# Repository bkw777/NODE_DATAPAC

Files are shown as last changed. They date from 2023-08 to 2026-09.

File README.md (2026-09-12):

# NODE Systems DATAPAC
* [Documentation](#documentation)
* [Hardware](#datapac-hardware)
  * [Reproduction Schematic & PCB](#reproduction-schematic--pcb)
  * [Theory of Operation](#theory-of-operation)
  * [Battery](#battery)
  * [Upgrading 128K to 256K](#upgrading-to-256k)
  * [Model Compatibility](#model-compatibility)
* [Software](#software)
  * [BASIC](#basic)
<!-- 
  * [RAMDSK](#ramdsk)
    * [Installation](#installing-ramdsk)
    * [Usage](#using-ramdsk)
  * [NBOOT](#nboot)
  * [RAMPAC Inspector](#rampac-inspector)
  * [XOS-C](#xos-c)
  * [N-DKTR](#n-dktr)
  * [NODE-PDD-Link](#node-pdd-link)
  * [NDEXE](#ndexe)
  * [RAMPAC Diagnostic](#rampac-diagnostic)
-->
* [MiniNDP](#minindp)
<!--
  * [PCB & BOM](#minindp-pcb--bom)
  * [Cover](#minindp-cover)
-->

This repo documents the NODE Systems [DATAPAC](PICS/DATAPAC/), [rampac](PICS/rampac/), and a new clone, the [MiniNDP](#minindp).

The NODE Systems DATAPAC/rampac was a popular ram disk peripheral for TRS-80 / TANDY Models 100, 102, & 200 computers.

The schematic and PCB below documents the DATAPAC.

rampac is a smaller later version of the same device that uses fewer larger sram chips and replaces most of the discrete logic IC's with a single PLD, but functions exactly the same.

Here is some disorganized [INFO](software/) mostly gathered from the [M100SIG archive](https://github.com/LivingM100SIG/Living_M100SIG) and [club100](http://www.club100.org).

TLDR: To use the hardware, install [RAMDSK](software/RAMDSK), and what you get is a ram disk of 128k to 1M depending on model and installed ram.

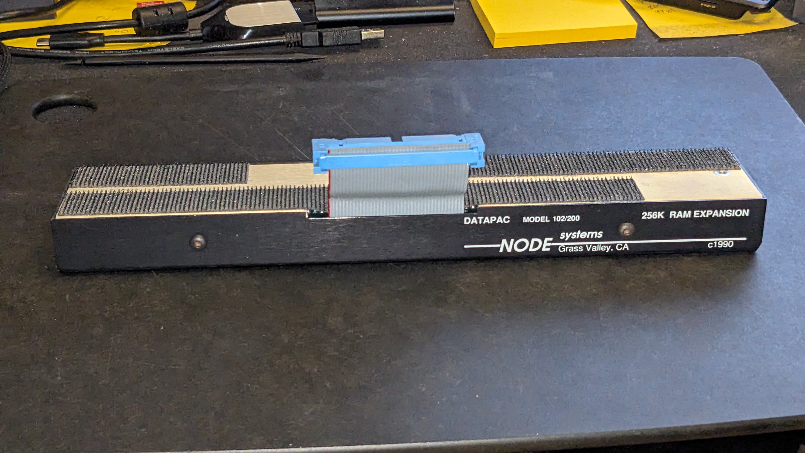
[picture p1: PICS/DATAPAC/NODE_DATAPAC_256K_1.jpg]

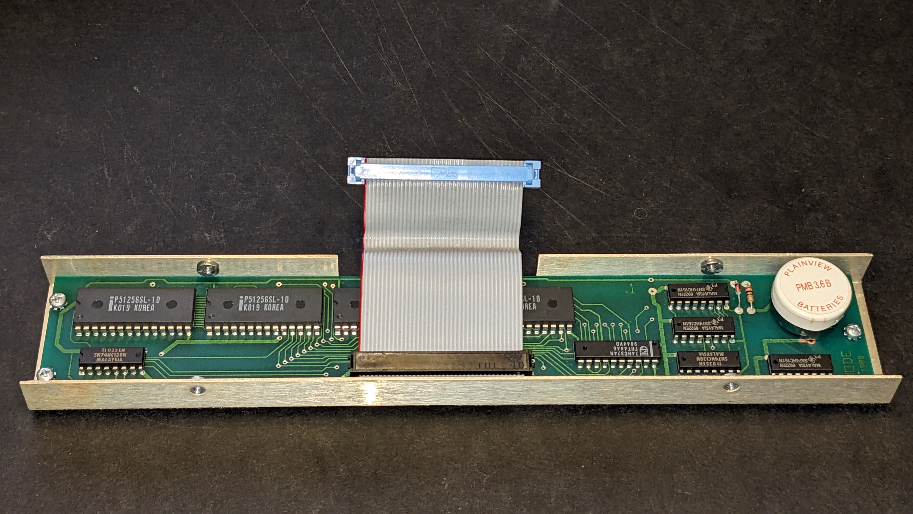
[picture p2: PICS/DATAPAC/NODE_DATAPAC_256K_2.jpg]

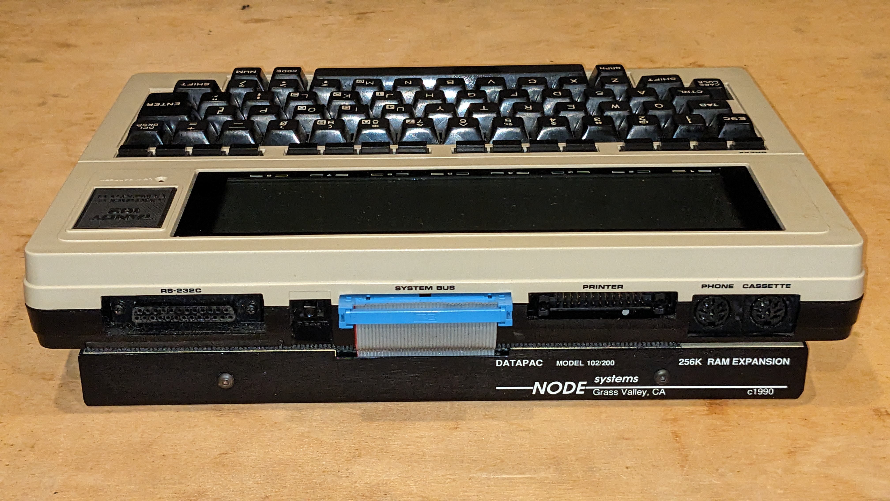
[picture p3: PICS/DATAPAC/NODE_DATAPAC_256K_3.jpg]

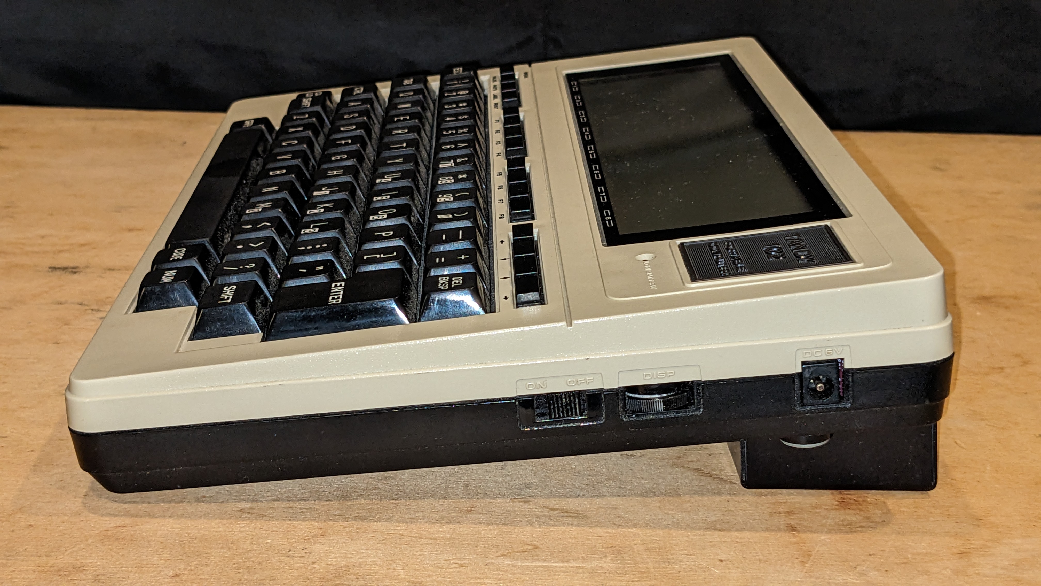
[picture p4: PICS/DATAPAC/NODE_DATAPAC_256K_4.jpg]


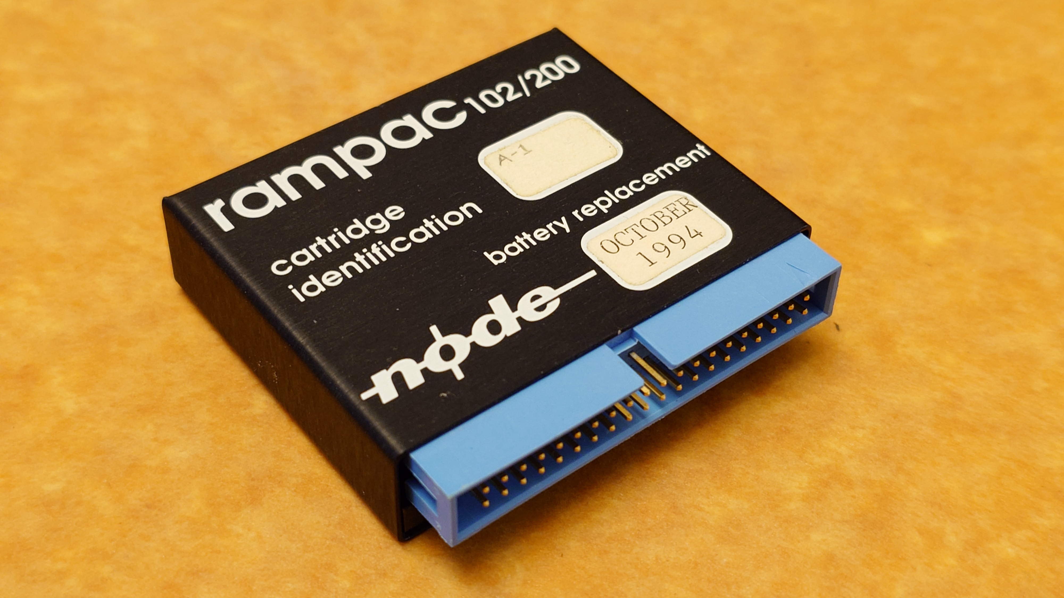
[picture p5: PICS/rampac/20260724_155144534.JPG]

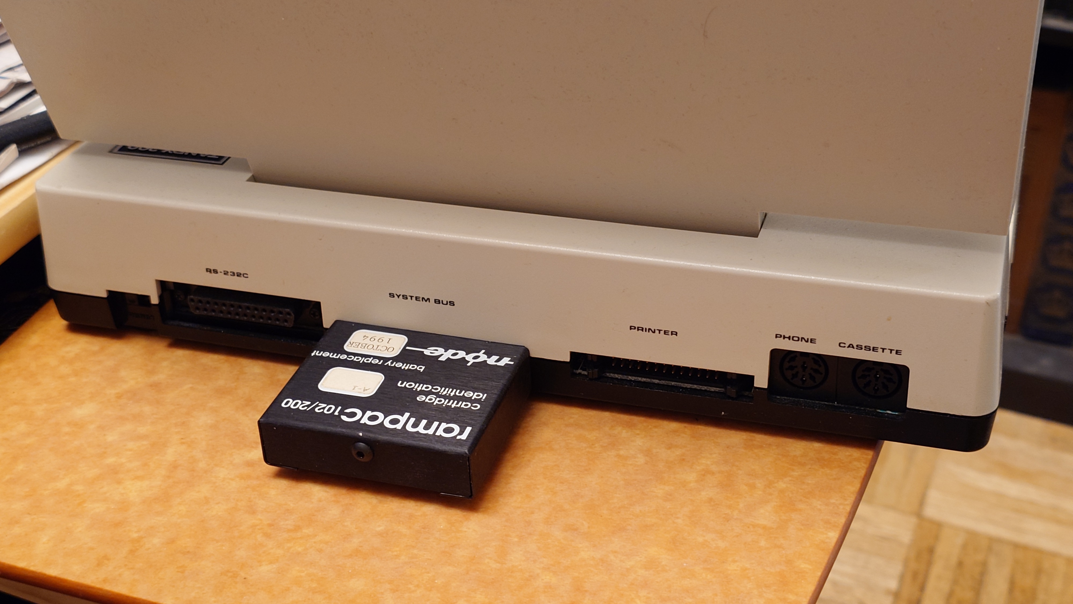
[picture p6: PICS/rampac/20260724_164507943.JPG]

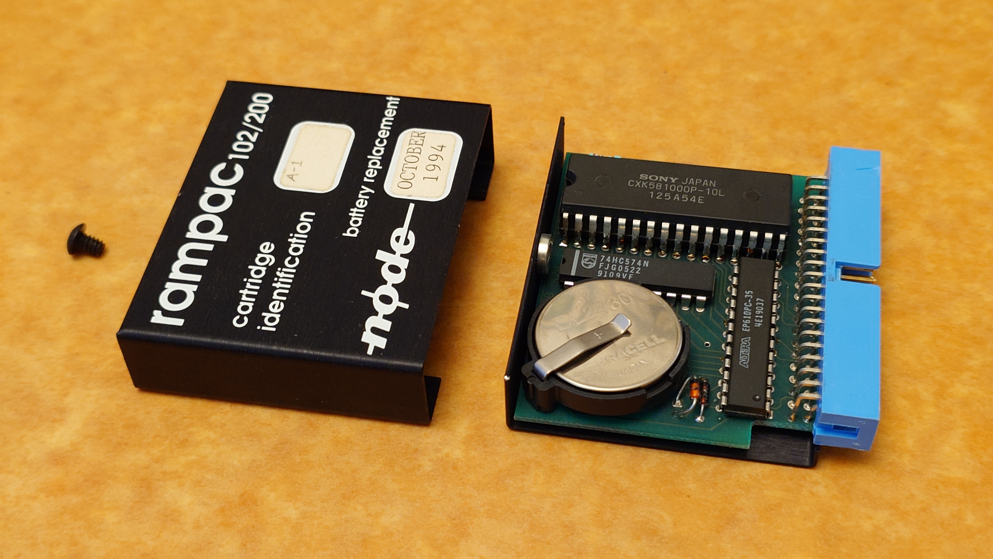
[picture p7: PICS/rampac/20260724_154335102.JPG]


# Documentation
The original text file manual [RAMDSK.DO](ROM/100/RAMDSK.DO).  
The [NODE ROM](ROM) that came with the unit generates this file when formatting a device.

There are also some discussions in the [M100SIG archive](https://github.com/LivingM100SIG/Living_M100SIG) and Paul Globmans software on [club100](http://www.club100.org/library/libpg.html).  
Most of these are collected in [docs](docs).  
See also the docs for the various bits of [software](software).

Other References  
* "Database management with both the Node RAMPAC & DATAPAC."  
  Alspaugh, Ron - [Portable 100, Nov 90:8-11](https://archive.org/details/P100-Magazine/1990-11/page/8/)  
* "Node utility mini-extravaganza! Here are two special programs for Node Datapac/RAMPAC users."  
  Globman, Paul - [Portable 100, Dec 90:19-20](https://archive.org/details/P100-Magazine/1990-12/page/18/)  

# DATAPAC Hardware
## Reproduction Schematic & PCB
This is a new drawing but aims to reflect the original actual device as exactly as possible.  
It's meant to be a form of documentation or reference describing the original hardware as it was.  
For instance, the ungrounded inputs on the 161's, the inconsistent thickness of power traces, the fact that only 1 of the 2 bus VDD pins is connected, the VCC trace that almost touches one of the mounting screw heads, etc, are all exactly as in the original.  
(I added a fiber washer to that screw in my units after noticing that. The case is not connected to ground, but still...)  

For a historical reproduction version of the original PCB (minus the NODE copyright mark), see: NODE_DATAPAC_256K_historical_reproduction.kicad_pro

For a version of the original PCB that still uses the same components and fits in the same case, but cleans up a few things, see: NODE_DATAPAC_256K_bkw.kicad_pro



PCB TOP
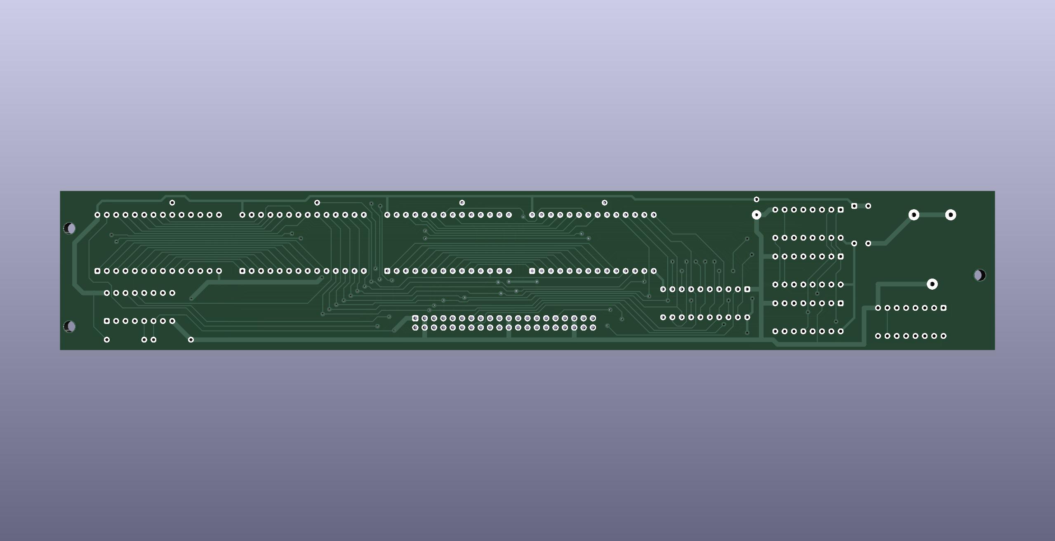
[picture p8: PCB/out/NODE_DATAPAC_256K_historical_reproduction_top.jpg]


PCB BOTTOM
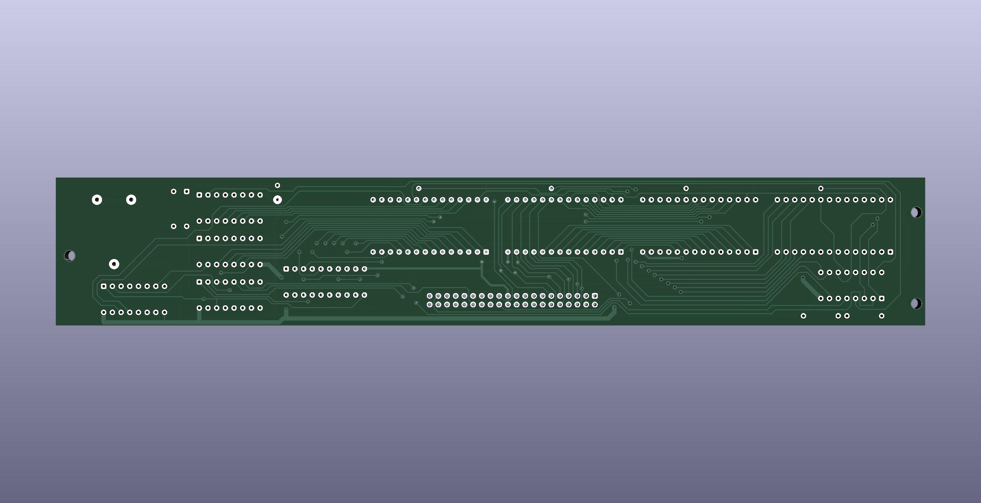
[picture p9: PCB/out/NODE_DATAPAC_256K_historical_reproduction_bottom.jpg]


The original PCB has no silkscreen. This image has silkscreen added to show where the components from the schematic go.
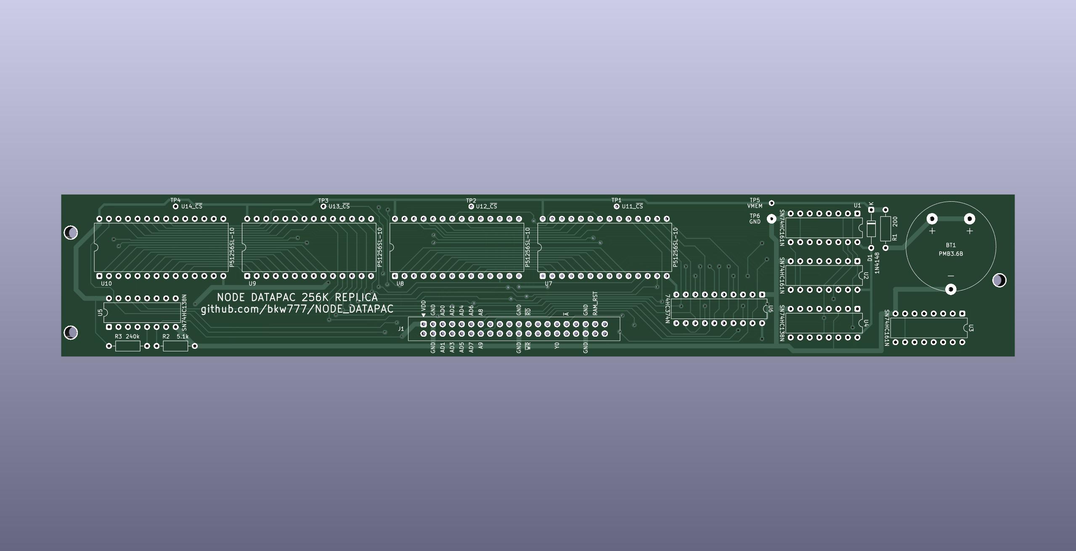
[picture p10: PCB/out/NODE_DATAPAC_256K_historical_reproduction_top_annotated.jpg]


<!--
## Updated Replacement PCB that fits the original case

Uses all the same through-hole parts, fits in the original enclosure, improves the trace routing a little, for example moving that VCC line away from that screw head, GND traces replaced by zone fills, thicker and all the same size vcc lines, decoupling caps, silkscreen.  
![](PCB/out/NODE_DATAPAC_256K_bkw.svg)
![](PCB/out/NODE_DATAPAC_256K_bkw.top.jpg)
![](PCB/out/NODE_DATAPAC_256K_bkw.bottom.jpg)
![](PCB/out/NODE_DATAPAC_256K_bkw.f.jpg)
![](PCB/out/NODE_DATAPAC_256K_bkw.b.jpg)
-->

## Theory of Operation
The circuit has 2 functions, SELECT-BLOCK and READ/WRITE-BYTE, controlled by the internal active-low signals /BLOCK and /BYTE.

The U4 HC138 monitors four lines from the bus, `/Y0` `(A)` `A8` `A9`, and based on that asserts either `/BLOCK` or `/BYTE` or neither.  
If neither /BLOCK nor /BYTE is asserted then the bus traffic has no effect on any of the other chips.

The 3 HC161 form a 0-1023 counter, setting SRAM address bits A0-A9.  
Call this the byte-number or byte-position counter or offset.

The HC374 sets SRAM address bits A10-A17 from the bus data bits AD0-AD7, and latches that value on its outputs until triggered to update to a new value.  
Call this the block-number or block selector.

The U5 HC138 converts 3 bits of the block-number into 1 of 8 chip-select to select 1 of 8 32K SRAM chips,  
and also monitors both /BYTE and RAMRST and disables all ram while either /BYTE or RAMRST is high.

----

### SELECT-BLOCK
When /BLOCK goes low:
* SRAM A0-A9 are reset to 0  (byte-position counter is reset to 0)
* BUS AD0-AD7 are copied to SRAM A10-A17  (bus data lines AD0-AD7 select a block-number)

When /BLOCK goes high:
* SRAM A10-A17 are held latched at whatever they were set to  (block-number is locked in until next /BLOCK)

----

### READ-BYTE / WRITE-BYTE
When /BYTE goes low:
* SRAM is enabled  (bus data lines AD0-AD7 read from or write to the current address in SRAM)

When /BYTE goes high:
* SRAM is disabled
* A0-A9 are incremented by 1 (byte-position, thus the current address in SRAM, is advanced to the next byte)

----

The byte-number and block-number combine to form the current address in SRAM at any given time.  

The device provides up to 256 blocks (8-bit block-number) of 1024 bytes each (10-bit byte-number).

The host computer first does a SELECT-BLOCK to select a block number from 0-255, then does READ-BYTE or WRITE-BYTE to read or write one byte of data at byte number 0 in that block, then repeats the BYTE operation up to 1023 more times to read or write up to all 1024 bytes in the block.  

If you read or write more than 1024 times without selecting a new block, the byte-number counter just rolls over to 0 again.

You can also mix reads and writes in the same block. Each read OR write advances the byte position the same way each time, regardless if the previous operation was a read or a write. For instance in order to skip over 64 bytes without modifying them and then start writing at the 65th byte, you would read-and-ignore 64 times and then start writing.

"ramdisk" is an appropriate term because the device actually does operate like a disk even though it has no brains or firmware. The block-select latch acts like a track or sector address, and the binary counter acts like a disk or tape head reading or writing a sequential stream of bytes.

Later versions of RAMPAC were offered with 384k or 512k by adding a second bank of up to 256k, and later versions of RAMDSK.CO know how to access the 2nd bank.

In 512K units, the extra 256K is accessed by the state of bus address line A10 during a SELECT-BLOCK operation.  
SELECT-BLOCK with BUS_A10 low accesses bank0, with BUS_A10 high accesses bank1.  
All other aspects are the same, so accessing bank0 on a a 512K device is the same as accessing the only bank on a 256K device.  Old software is still compatible with bank0 on new hardware, new software is still compatible with old hardware.

[What this all means from the host computer software side of things](https://github.com/bkw777/NODE_DATAPAC?tab=readme-ov-file#low-level-direct-access-using-only-basic)

## Battery
The original battery is no longer made, and the modern cross-reference is almost 2mm taller and does not fit inside the enclosure.

NODE Systems themselves used to perform an update to older units to replace the original rechargeable NiCD cell with a non-rechargeable lithium cell which was supposed to last about 5 years.

The change is simple and easy, and the parts are common. You just remove the old battery and the 200 ohm resistor, and replace them with a CR2032 holder and a diode. That's it. Both parts fit and solder right in the same locations where the old parts came out. Point the diode stripe away from the battery, just like the other diode that is right there next to it. Any standard diode will do. Schottky is not recommended because the reverse leakage is not good for a lithium cell. Another 1N4148 like the one that's already there is perfect.  
This should give at least 4 years of memory.  
(The original NiCD battery may have only lasted as little as a few months per charge according to a review in the archives. So the coin cell mod is not merely more conveniently available with current parts, it's an improvement.)

BEFORE
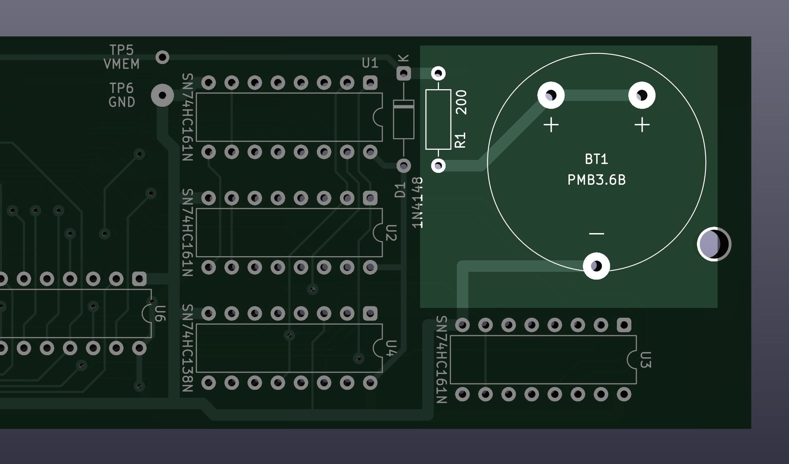
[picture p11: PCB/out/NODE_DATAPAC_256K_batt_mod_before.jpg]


AFTER
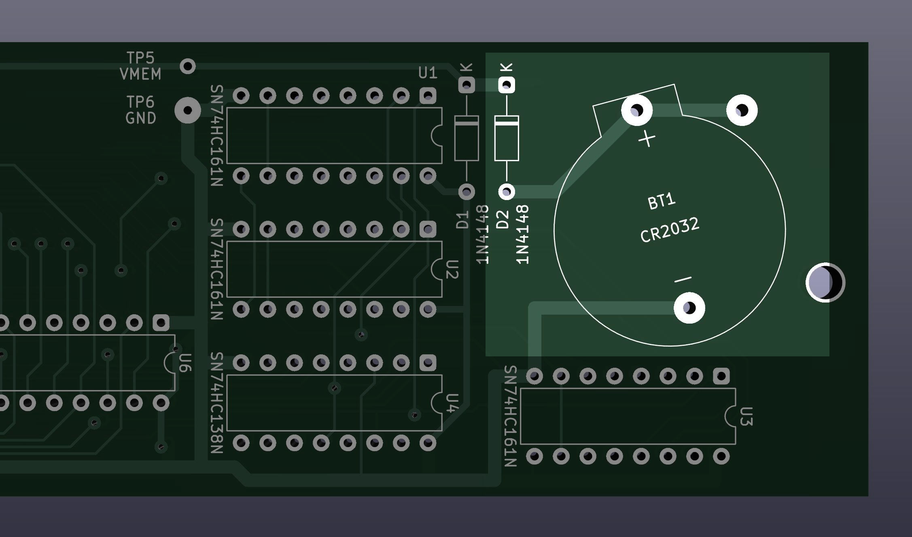
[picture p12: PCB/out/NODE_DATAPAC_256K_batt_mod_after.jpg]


STEPS
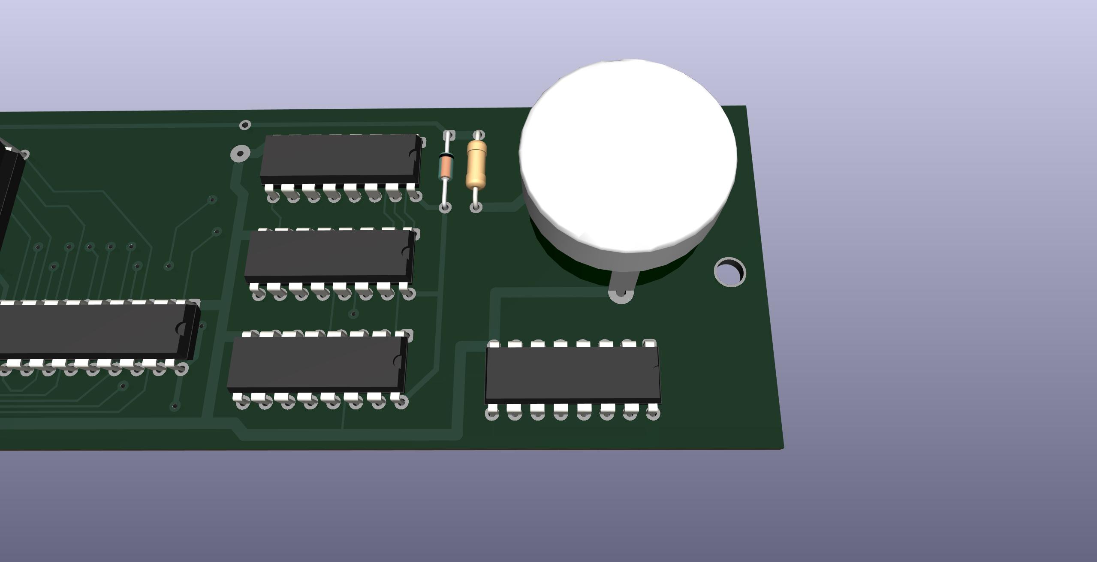
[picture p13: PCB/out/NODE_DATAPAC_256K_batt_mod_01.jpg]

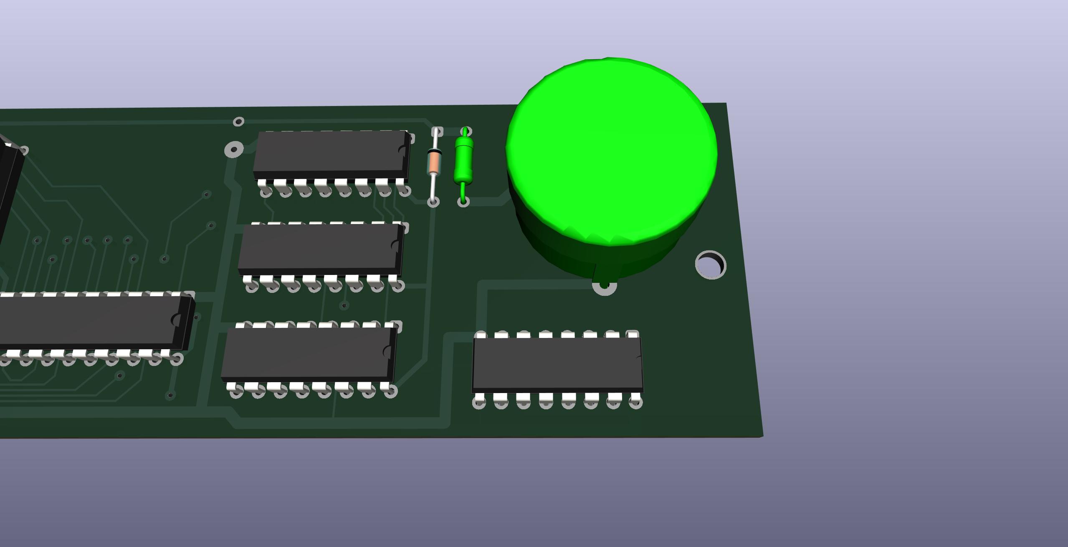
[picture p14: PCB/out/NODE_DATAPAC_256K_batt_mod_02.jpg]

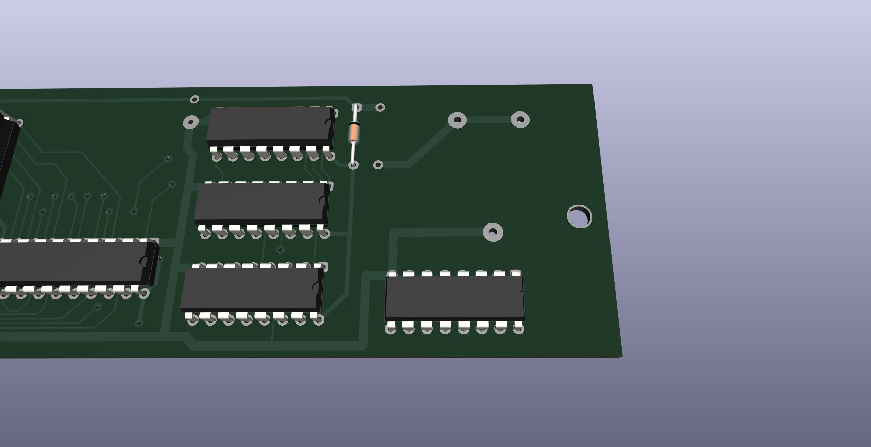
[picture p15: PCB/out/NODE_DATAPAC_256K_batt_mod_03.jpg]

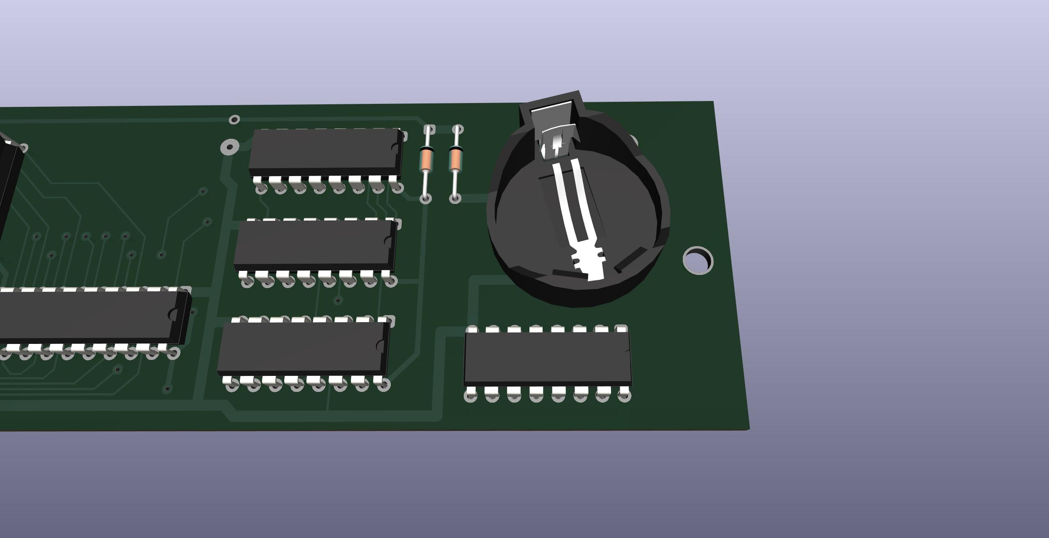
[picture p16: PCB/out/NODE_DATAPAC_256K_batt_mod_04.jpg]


If you wish to keep using a rechargeable battery, then one suitable option is FL3/V80H. That is 3 16x5.8mm NiMH button cells in a flat in-line pack with wire leads. It fits perfectly in the space next to the ribbon cable. It needs to be secured with hot glue or foam mounting tape, and connected with wires run to the original battery location.  
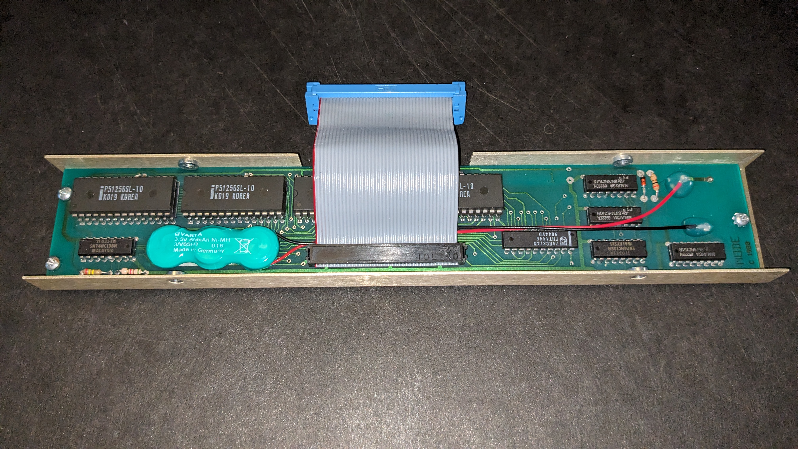
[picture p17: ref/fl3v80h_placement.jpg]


The charging circuit is utterly basic, so do not connect any other type of battery except NiCD or NiMH.  
You can use any cell form factor and any larger or smaller mAh capacity, but must be 3.6v and only NiCD or NiMH chemistry.

## Upgrading to 256K
A 128k unit may be upgraded to 256k by just adding 4 more SRAM chips piggy-backed onto the existing chips.

The PCB has 4 DIP-28 footprints for the SRAM chips.  
Each DIP-28 footprint also has an extra via close to pin 20.

A 128k unit has a low-power 62256 installed in each footprint, and nothing connected to the via near pin 20.

To get 256k, a second set of chips are soldered piggyback on top of the first four.  
All pins except pin 20 (chip-select) are simply soldered to the chip below.  
Pin 20 is bent out and connected to the extra via on the pcb (with a short bit of wire to reach) and not connected to the chip below.  

No other parts or changes are needed to upgrade an existing 128k unit to 256k.

Any 62256 will work, but for old parts you want the low-power version for standby battery life.  
New parts already naturally have as low or lower standby current than the low-power versions of old parts even if they don't say "low power".  
Old standard: HM62256    70uA  
Old lowpower: HM62256LP  4uA  
Old lowpower: P51256SL   2uA  
New standard: AS6C62256  1uA

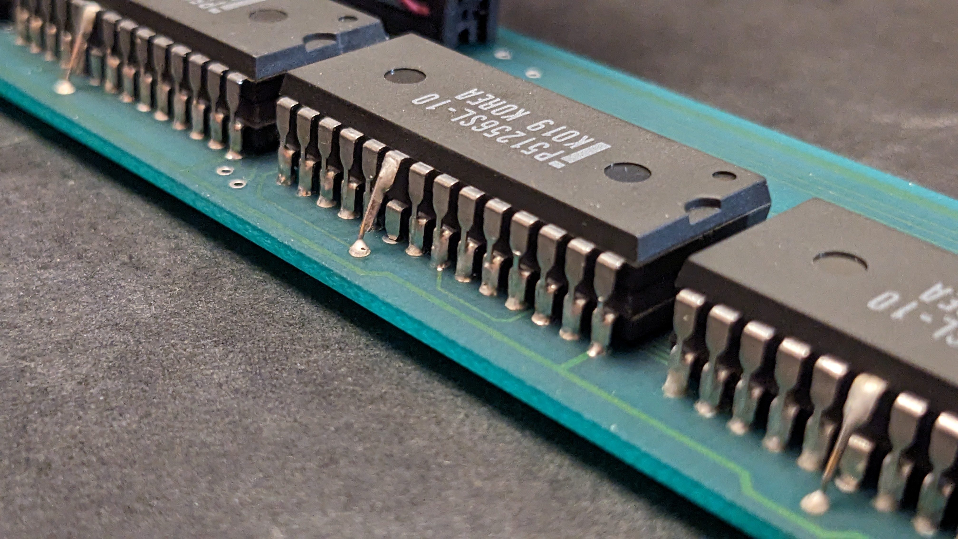
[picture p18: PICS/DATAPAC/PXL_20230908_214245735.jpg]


The same is true for rampac. Except:  
 - single 128k sram chip, ex: AS6C1008
 - chip-select is pin 30
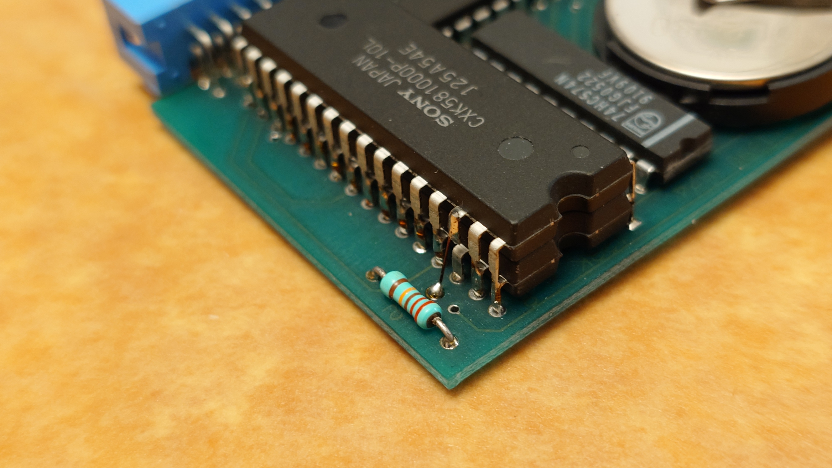
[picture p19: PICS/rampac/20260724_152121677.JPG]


## Model compatibility  
Originally only North-American Models 100, 102, & 200 were ever supported.  
Kyotronic KC-85 and Olivetti M-10 are also supported today because RAMDSK has been disassembled and ported, and the assembly source means the international models could be added as well.  
The device is not compatible with NEC PC-8201/PC-8300.

Although the DATAPAC was primarily designed for Model 102 & 200, the crimp-on boxed male IDC pin header on the cable does not actually fit into a 200 without enlarging the opening around the bus connector on the 200. If you want to connect an original DATAPAC to a 200 without hacking up the 200's case or modifying the DATAPAC cable, you can build a small [adapter](ref/T200_adapter.jpg) by just soldering a [male](https://www.digikey.com/en/products/detail/sullins-connector-solutions/SBH11-PBPC-D20-ST-BK/1990068) & [female](https://www.digikey.com/en/products/detail/sullins-connector-solutions/SFH11-PBPC-D20-ST-BK/1990093) solder-type 2x20 boxed pin headers back to back. The solder box header does fit in the opening.
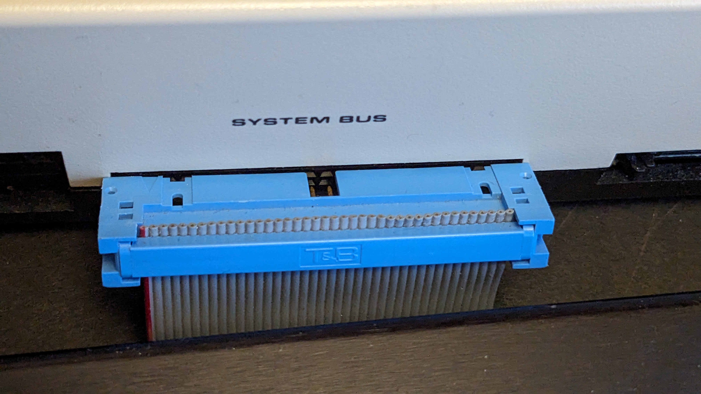
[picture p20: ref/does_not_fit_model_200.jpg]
  
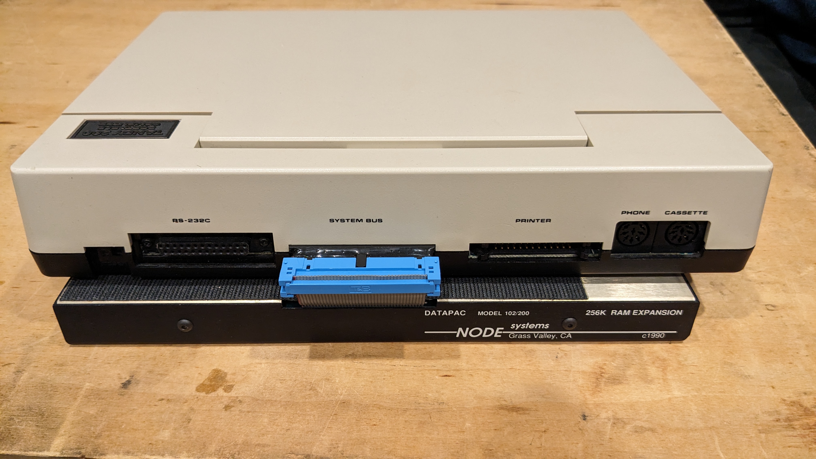
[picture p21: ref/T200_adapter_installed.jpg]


The DATAPAC case says "102/200", but it also works on Model 100, K85, and M10 with the right adapter cable. It's electrically compatible with everything but NEC.

For 100 & K85 the cable is just an IDC-DIP-40 aka "DIP-40 wire-to-board" connector and a standard 2x20 female IDC connector, both crimped onto a 40-pin ribbon cable about 8 inches long.  
[The Model 100 adapter part](https://github.com/bkw777/TRS-80_Disk_Video_Interface_Cable/blob/main/README.md#part-3---model-100-adapter) of this [3-part Disk/Video Interface Cable](http://tandy.wiki/Disk/Video_Interface:_Cable) is the same thing.

For Olivetti M-10 the cable is even simpler, a standard female to female IDC 40-pin ribbon cable.

[MiniNDP](#minindp) fits directly on both 102 and 200 with no adapter or cable, or M10 with a female-female ribbon cable at least 5 inches long.

[MiniNDP_u1M](#minindp-u1m---for-model-100-or-kyotronic-kc-85) fits directly in the bus socket of 100 or K85 with no adapter or cable, and the cover can even be closed over it.

# Software

 - [NODE ROM](ROM)  
 - [RAMDSK.CO](software/RAMDSK)  
 - [XOS-C](http://www.club100.org/library/libpg.html) ("sort of an OS" for the Model 200, does not require a rampac but leverages one if available. [Several of the NODE utils from the M100SIG require XOS-C.](software/Requires_XOS-C/))
 - [other](software)  

Originally these shipped with an [OPTION ROM](ROM) from NODE called RAMDISK.

Later, Paul Globman wrote [RAMDSK.CO](software/RAMDSK), and that was eventually licensed by NODE and shipped with new units.  

Later still, RAMDSK was updated with 2 changes:  
 - automatic repair of a corrupted format stamp on start-up  
 - support for 512k in 2 banks of 256k (RAMPAC & EXTRAM)

Recently, RAMDSK has been updated yet further:  
- disassembled to produce assembly source  
- ported to Kyotronic KC-85  
- ported to Olivetti M-10  
- support for 4 banks  
- format on demand from Label button  
- added safety confirmation to format & repair  
- removed dead code

Some other software culled from the [M100SIG archive](https://github.com/LivingM100SIG/Living_M100SIG) and [Club100](https://www.club100.org) are collected here in the [software](software) directory.  

## BASIC
How to access the hardware from BASIC.

### High level file operations using CALLable machine language routines
See [RAMDSK.DO](ROM/100/RAMDSK.DO) for the NODE ROM routines.  
See [RAMDSK.TIP](software/RAMDSK/RAMDSK.TIP) for the RAM100.CO/RAM200.CO routines.  
But note, the addresses in RAMDSK.TIP are incorrect for RAMDSK v2. We don't have a copy of RAMDSK v1 for 100 but we do for 200. So you can't follow those directions exactly except with RAMDSK v1 on 200.  

The latest RAMDSK built from the new source includes *.calls files that give the current addresses to the routines in those binaries, but actually using them has not been tested.

### Low level direct access using only BASIC
There are two low level operations that you use to access the device,  
BLOCK and BYTE, and each of those has two variations, for four total ops.

Select a BLOCK from BANK 0  
`OUT 129,n`  
Selects block# **n** (0-255) in bank 0, and resets the byte position to 0.

Select a BLOCK from BANK 1  
`OUT 133,n`  
Selects block# **n** (0-255) in bank 1, and resets the byte position to 0.

Read a BYTE  
`INP(131)`  
Reads the byte at the current byte position, and advances the byte position by one.

Write a BYTE  
`OUT 131,n`  
Writes the value **n** (0-255) to the current byte position, and advances the byte position by one.

The first read or write after selecting a block# applies to byte #0 of that block.  
The byte position advances by one after each read or write, so the next read or write will be byte #1, then byte #2, etc up to 1024.  
If you read or write more than 1024 times without selecting some other block, the byte position just rolls over to 0 again.

The position counter advances the same whether reading or writing.

Since the device can only read or write a single unsigned byte at a time, it's most efficient to use integer variables.  
Use the % suffix or DEFINT: `B%=INP(131)` or `DEFINT B : B=INP(131)`

The general sequence is always:  
1 - select a bank+block  
2 - read/write byte 0-1024 times

To seek to an arbitrary offset before reading or writing, read-and-ignore that many bytes.

For instance, in RBOOT.DO, to skip over the first 16 bytes of the block, it does `FORA=0TO15:N=INP(131):NEXT`  
N is not actually used, it's just reading 16 times and ignoring the data. This just advances the byte position counter to get from byte #0 past the 10-byte RAMDSK header and 6-byte .CO header to the start of the .CO executable data.

Examples

Select bank 0 block 0  
`OUT129,0`

read a byte, which will be byte #0 of this block  
`INP(131)`

Read and print the ascii of all the bytes in bank 0 block 2.  
(this will mess up the display from control bytes if there is a binary .CO file in this block)
```
10 OUT 129,2
20 FOR I=0 TO 1023
30 PRINT CHR$(INP(131));
40 NEXT
```

Do the same but in bank 1  
change line 10 to:  
`10 OUT 133,2`

Manually repair the first two bytes of block 0 to mark the bank as being formatted without touching any of the data.  
This means:
1. Select bank0 block0  
2. write one byte, value 64  
3. write one byte, value 4

`OUT129,0:OUT131,64:OUT131,4`

(BTW you usually don't need to do this because RAMDSK.CO will do it for you.)

# MiniNDP

New design that functions the same as DATAPAC/rampac.

1 megabyte in 4 banks of 256k.

How to access all 4 banks:  
Select bank 0, block N: `OUT 129,N`  
Select bank 1, block N: `OUT 133,N`  
Select bank 2, block N: `OUT 137,N`  
Select bank 3, block N: `OUT 141,N`

Everything else works the same as normal DATAPAC/rampac.

## MiniNDP EZ1M - For Model 102 and 200

Unlike the original DATAPAC, this actually fits into the bus port on the Model 200 without having to hack it's case.

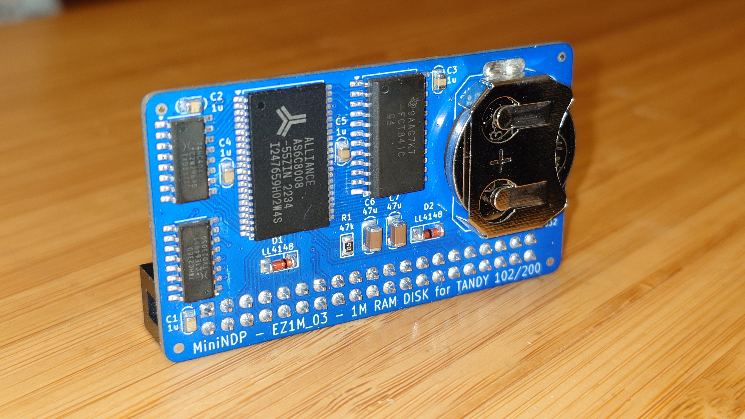
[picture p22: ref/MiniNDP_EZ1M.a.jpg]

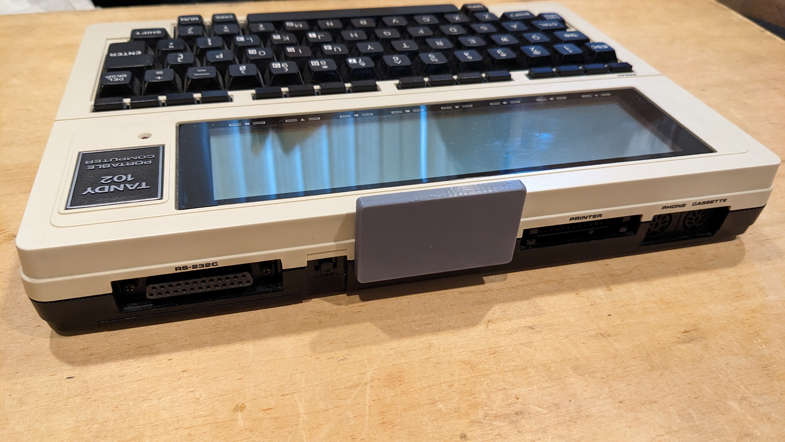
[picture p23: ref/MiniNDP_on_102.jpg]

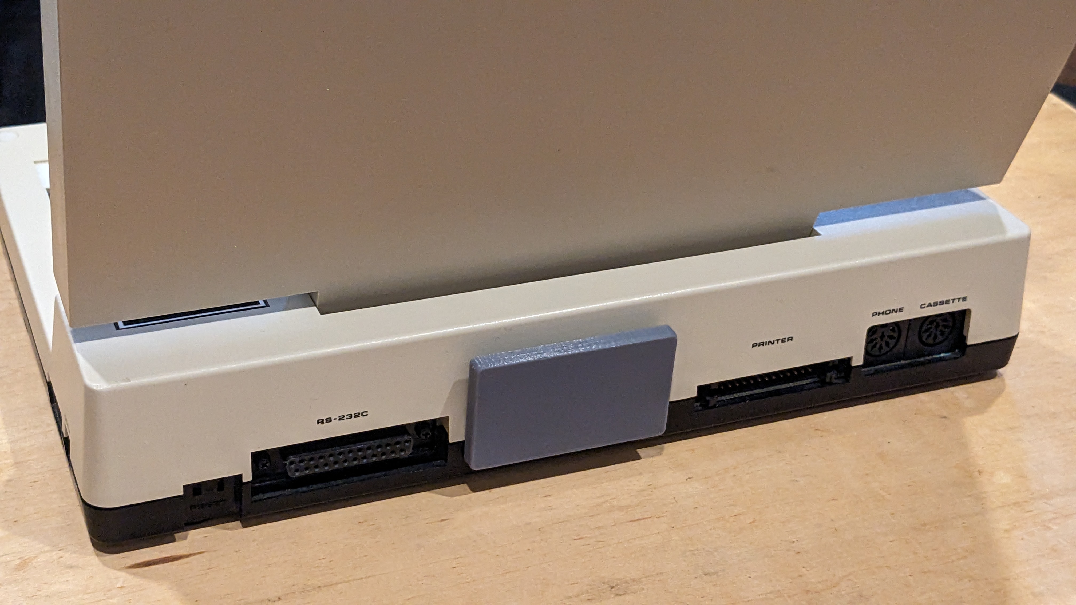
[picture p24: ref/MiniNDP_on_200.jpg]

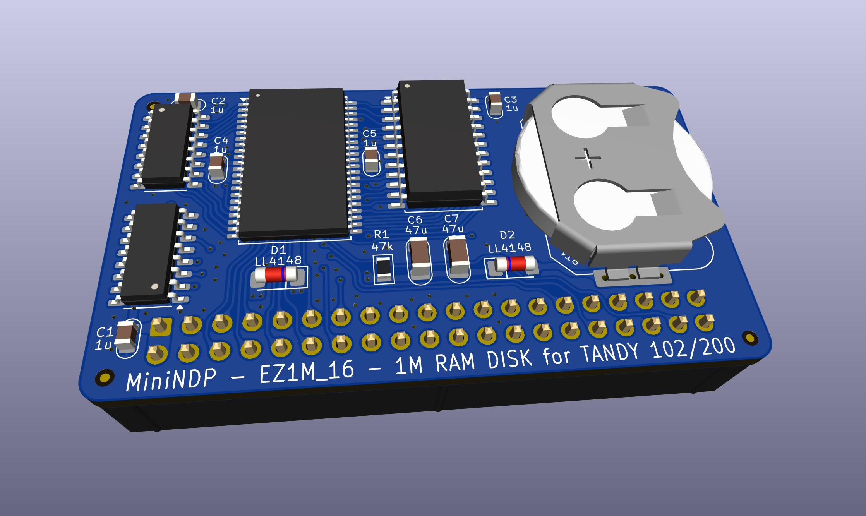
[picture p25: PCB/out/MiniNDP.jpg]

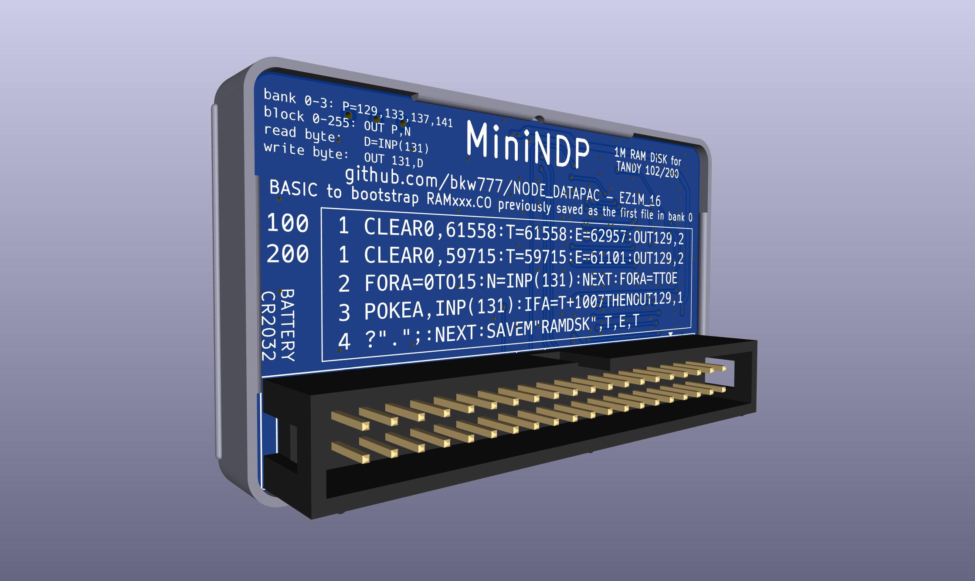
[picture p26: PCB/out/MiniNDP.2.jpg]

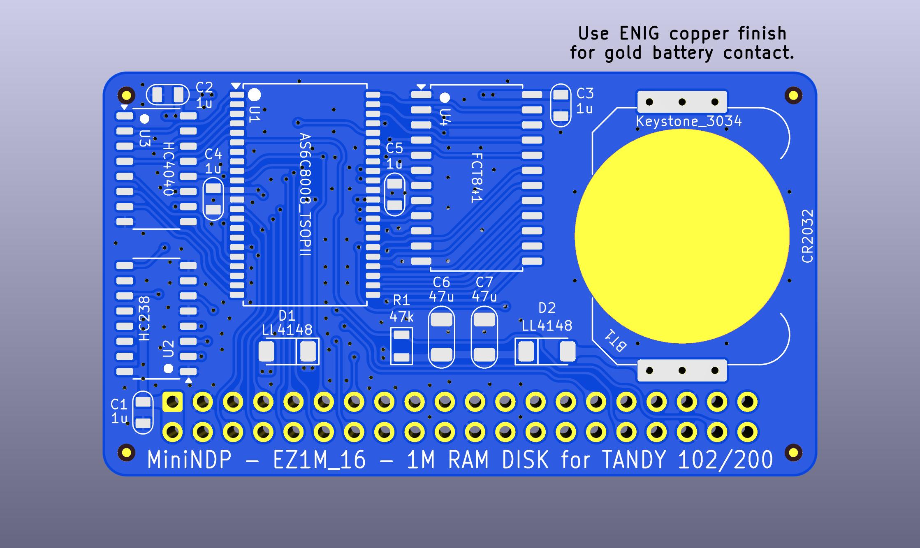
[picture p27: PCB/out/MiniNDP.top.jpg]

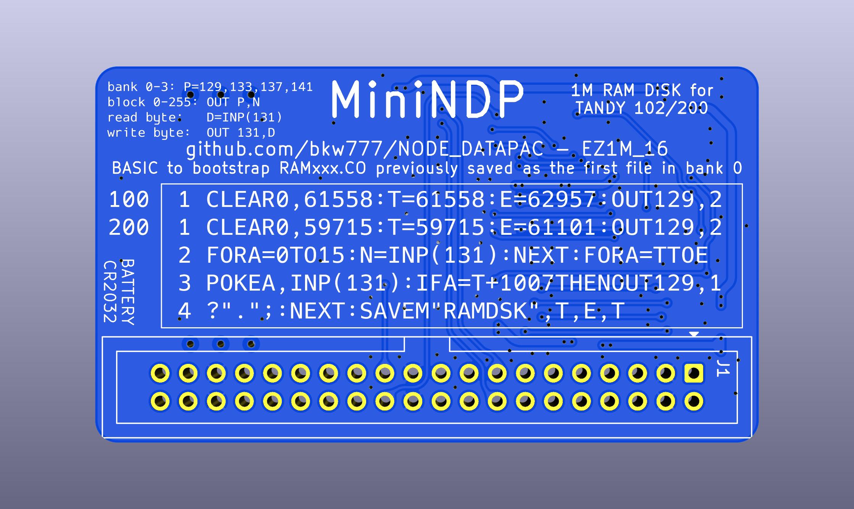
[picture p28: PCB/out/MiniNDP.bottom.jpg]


[MiniNDP.bom.csv](PCB/out/MiniNDP.bom.csv)

BOM: [DigiKey](https://www.digikey.com/short/m4h7bmh0)  
[MiniNDP EZ1M_16 PCB @ OSHPark](https://oshpark.com/shared_projects/7Jpm6F6c)  
Cover: [MiniNDP_Cover.stl](COVER/out/MiniNDP_Cover.stl) -- [Cover @ JawsTec](https://shop.jawstec.com/3d-printed-minindp-cover_p658.php)  
[Both PCB & Cover @ PCBWAY](https://www.pcbway.com/project/shareproject/MiniNDP_mini_Node_DataPac_d08018c4.html)  

## MiniNDP u1M - For Model 100 or Kyotronic KC-85

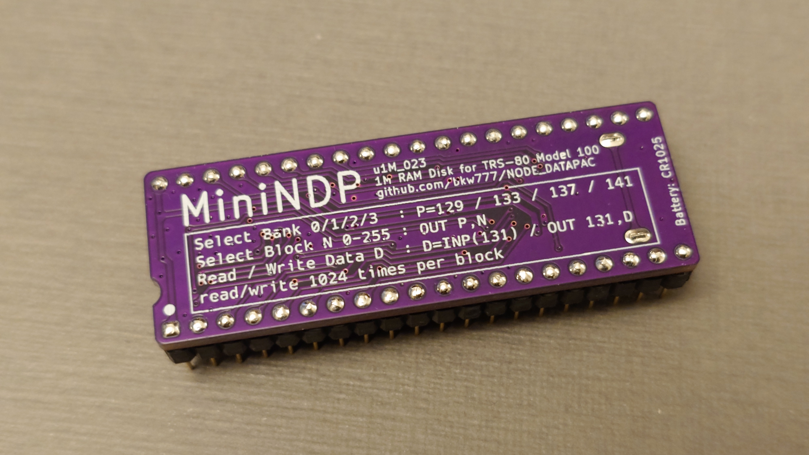
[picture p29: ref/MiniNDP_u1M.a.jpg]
  
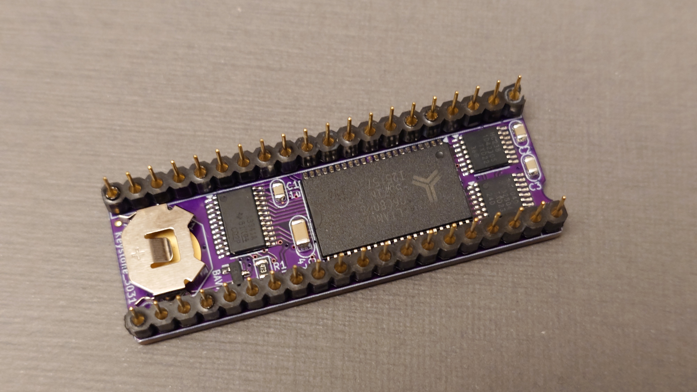
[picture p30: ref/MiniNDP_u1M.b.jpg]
  
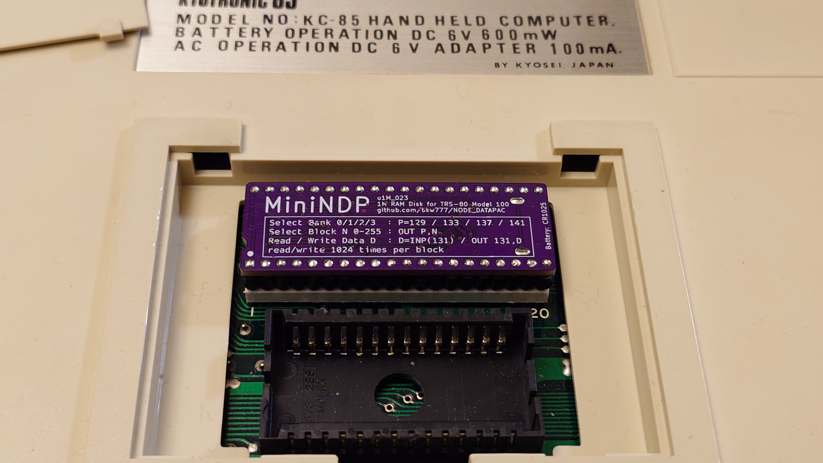
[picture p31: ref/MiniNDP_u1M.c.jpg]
  
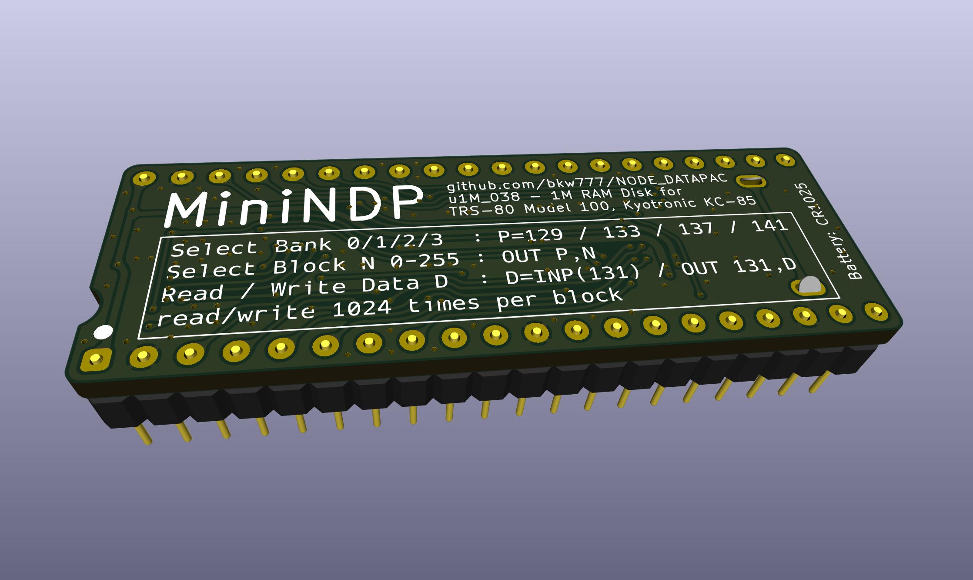
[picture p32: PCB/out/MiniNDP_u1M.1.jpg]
  
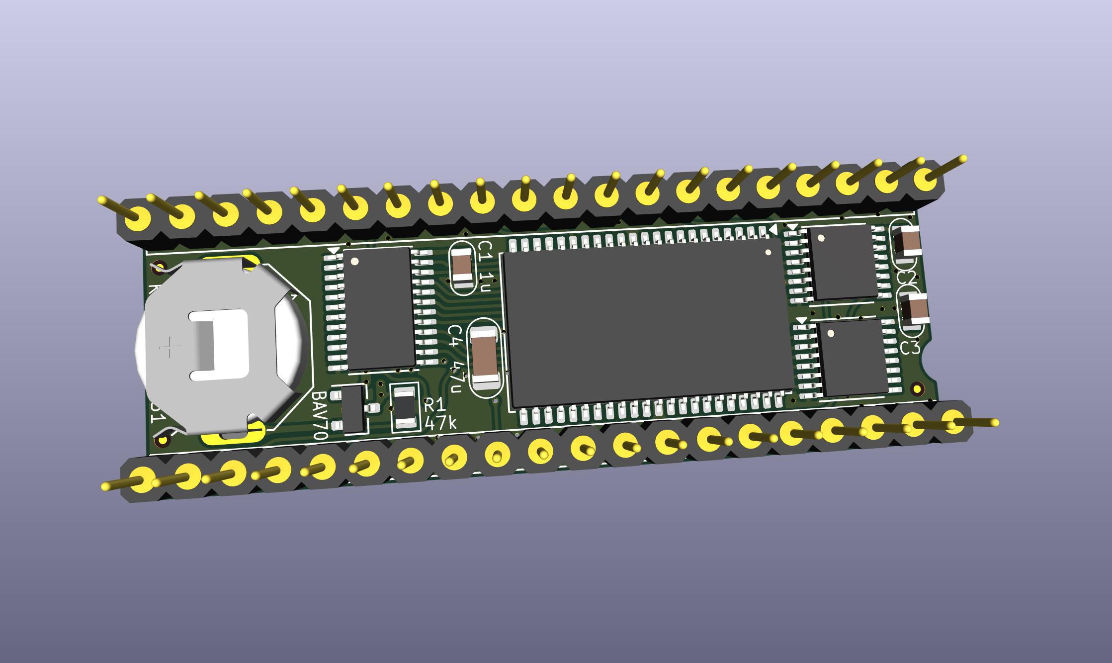
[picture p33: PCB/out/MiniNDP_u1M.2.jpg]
  
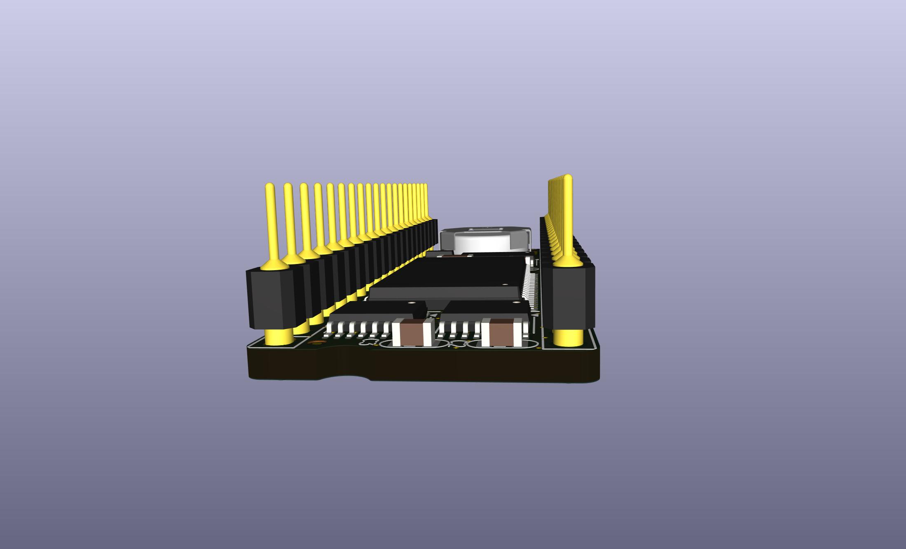
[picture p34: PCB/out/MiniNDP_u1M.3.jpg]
  
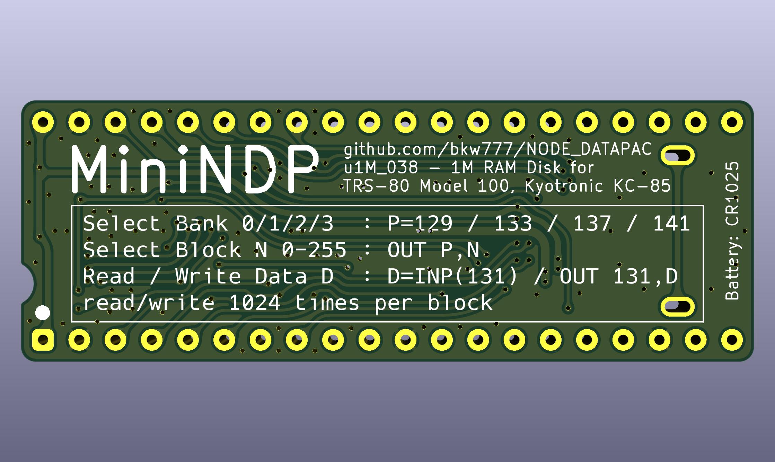
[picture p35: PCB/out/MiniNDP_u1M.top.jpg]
  
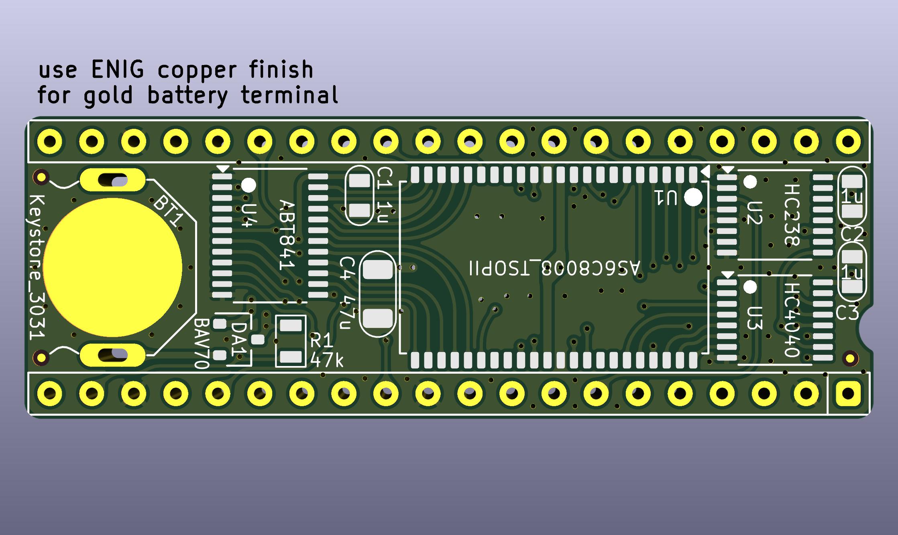
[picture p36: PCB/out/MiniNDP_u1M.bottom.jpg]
  
  

BOM: [MiniNDP_u1M.bom.csv](PCB/out/MiniNDP_u1M.bom.csv)  
[MiniNDP u1M_038 PCB @ OSHPark](https://oshpark.com/shared_projects/XwUDgfQu)

## MiniNDP M10 - For Olivetti M-10

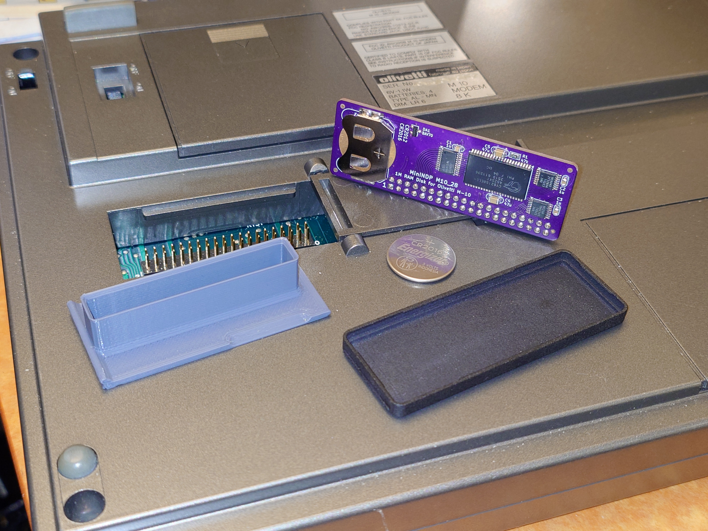
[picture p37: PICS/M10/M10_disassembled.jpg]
  
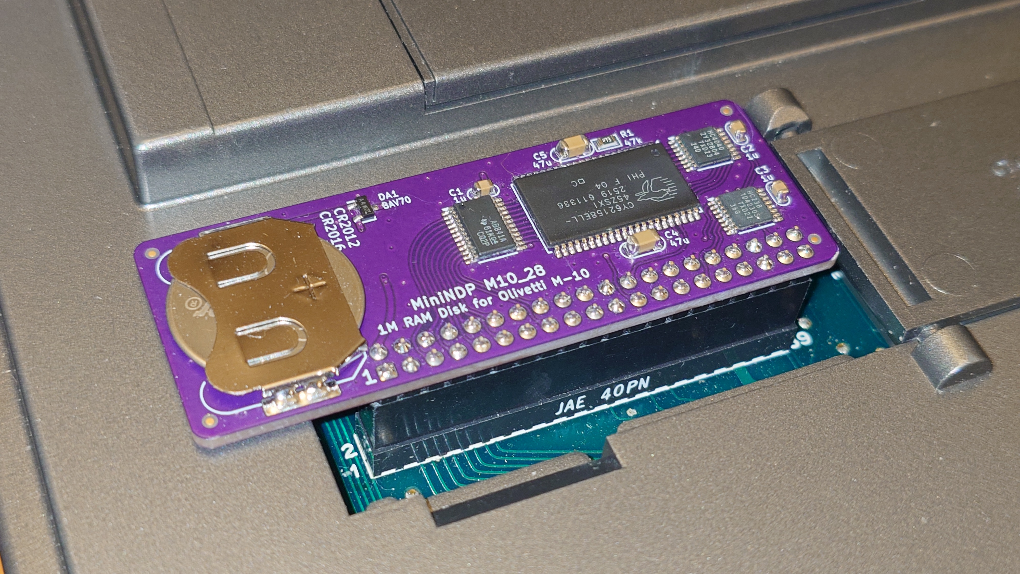
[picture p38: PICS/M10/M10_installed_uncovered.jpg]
  
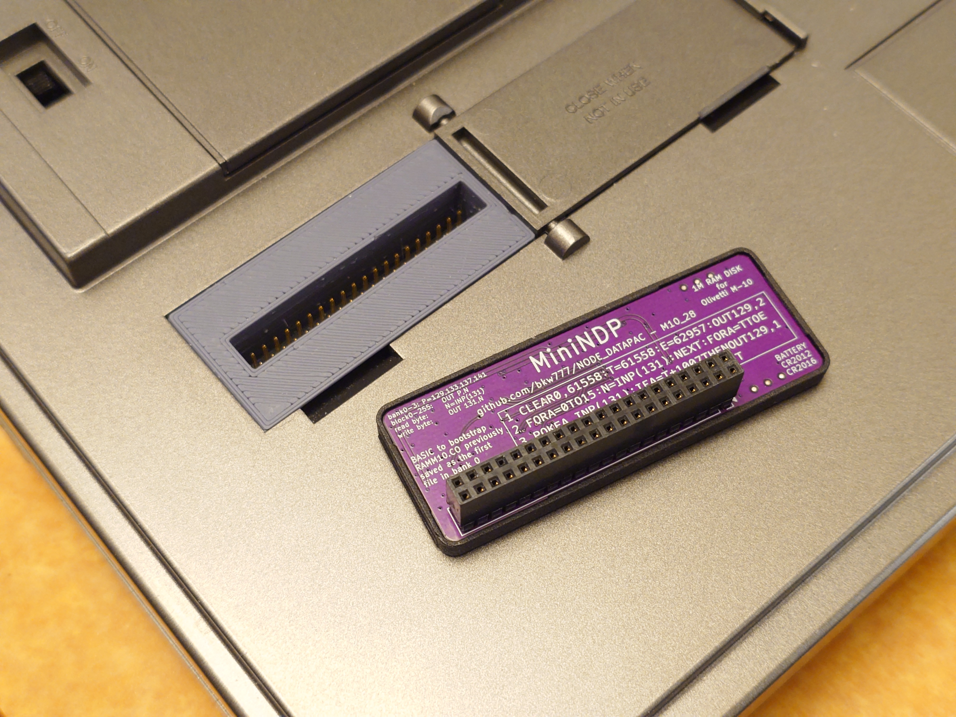
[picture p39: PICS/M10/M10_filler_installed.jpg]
  
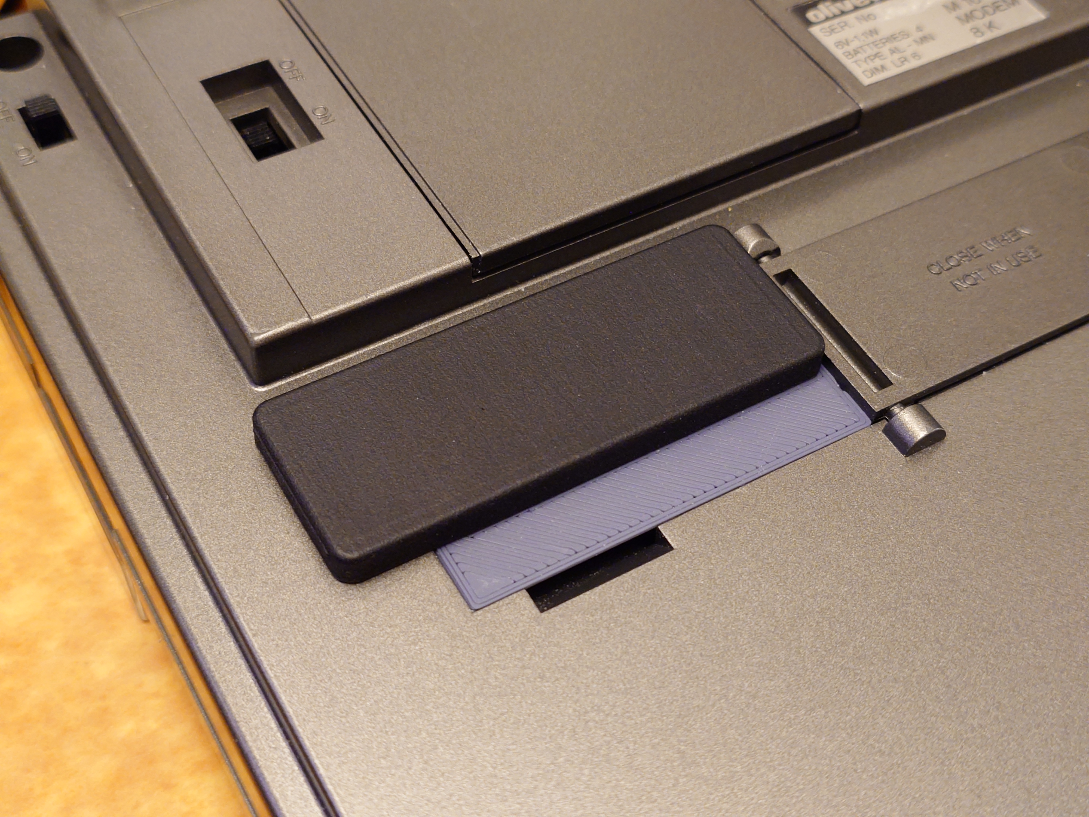
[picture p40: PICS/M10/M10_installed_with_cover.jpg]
  
  
  
  
  
  

BOM: [MiniNDP_M10.bom.csv](PCB/out/MiniNDP_M10.bom.csv)  
[MiniNDP M10_40 PCB @ OSHPark](https://oshpark.com/shared_projects/pgmxRV8e)  
Cover for M10: [MiniNDP_Cover_M10.stl](COVER/out/MiniNDP_Cover_M10.stl) -- [M10 Cover @ JawsTec](https://shop.jawstec.com/3d-printed-minindpm10-cover_p657.php)  
Bus connector guide & filler plate for M10 [M10_BUS_Filler_Plate.stl](COVER/out/M10_BUS_Filler_Plate.stl)

## [Other Versions](MiniNDP_variants.md)  
[SL1M](MiniNDP_variants.md#sl1m---slim-1-meg) - slim 1 meg, all thin chips to make a thin card  
[T512](MiniNDP_variants.md#t512---tsop-128k256k512k) - TSOP 128k/256k/512k  
[EZ512](MiniNDP_variants.md#ez512---easy-build-512k) - SOIC 512k  
<!-- ["OG"](MiniNDP_variants.md#minindp-og) - 128k-512k, most like the original DATAPAC schematic, more parts and more difficult, but the parts are more common  -->

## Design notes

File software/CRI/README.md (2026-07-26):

# Crude RAMPAC Inspector

You supply a bank number, block number, starting byte offset, and number of bytes, and it reads those bytes and displays them on screen.

bank: 0-3
block: 0-255
start: 0-1023
length: 1-1024

Press F2 while it's running to switch between ascii or hex display mode.

Press F8 while it's running or BREAK at the input prompt to quit.

The reason it exists when [RD](../Rampac_Diagnostic/) and [N-DKTR](../N-DKTR/) already exist is,  
* Smaller  
* No machine code - you can see everything it does or change anything it does all in BASIC  
* Stand-alone - does not require either the NODE rom or RAMDSK to work  
* Supports banks / devices with more than 256k

TODO - display/repair first 2 bytes formatted flag.  
TODO - display filenames and lengths from the headers.

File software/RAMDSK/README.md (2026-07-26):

# RAMDSK

Originally the DATAPAC was shipped with an option rom from Node (possibly commissioned from Travelling Software?) which saved and loaded files to/from the device.

Later, Paul Globman reverse-engineered the data format and wrote RAMDSK.CO, and Node eventually just licensed RAMDSK from Paul and shipped it with with the devices. (I call this RAMDSK v1)

Later still, Paul (or someone but presumably Paul) added support for 2 banks and added the format stamp repair function. (I call this RAMDSK v2)

Later still, I disassembled RAMDSK and modified it to support 4 banks and to improve the format/repair ux a little, and remove dead code, while artificially preserving the same file size and entry address as the previous version so that it would not require different boostrap/recovery BASIC code.

RAMDSK provides the same functionality as the NODE ROM, and is compatible with it.  
They both write the same filesystem structure to the device, either one can read/write a device that was formatted by the other.

Differences between the NODE ROM and RAMDSK:

The NODE ROM creates a text file when it formats a blank device, RAMDSK does not.

The NODE ROM docs claim it also supports PG Designs and PCSG ram expansions, which are NOT clones or work-alikes of the DATAPAC. RAMDSK only supports the DATAPAC or anything that works exactly the same way such as rampac, EXTRAM, MiniNDP.

RAMDSK supports banks (devices with more than 256K of ram), the NODE ROM only supports up to 256K.

RAMDISK includes a feature to automatically repair the easily-corrupted format stamp in the first 2 bytes of the device, the NODE ROM does not.

# Installing RAMDSK the first time

To get RAMDSK installed for the first time, use the appropriate `RAMxxx.DO` BASIC loader for your machine:  
  100: TRS-80 Model 100, TANDY Model 102  
  200: TANDY Model 200  
  K85: Kyotronic KC-85  
  M10: Olivetti M-10  

To bootstrap the BASIC loader from a PC running Windows:  
Install [tsend](https://github.com/bkw777/tsend)  
Then: `C:> tsend.ps1 -file RAM100.DO`

To bootstrap the BASIC loader from a PC running Linux, MACOS, FreeBSD, any unix, Cygwin/MSYS2:  
Install [dl2](https://github.com/bkw777/dl2)  
Then: `$ dl -v -b RAM100.DO`

Then run RAMDSK to format and use the device.

# Reinstalling RAMDSK from the device
Once you have RAMDSK installed, if you save a copy to the device as the very first file after a fresh format, then in the future you can re-install RAMDSK from the device itself after a hard reset by typing in a short BASIC program.

Archived docs mention an 8 line BASIC program called BOOT.  
That program does not seem to be archived anywhere, but I have written `RBOOT` below which is only 4 40-column lines.

Requires first saving a copy of RAMDSK.CO to the device, and must be the first file on the device.

You may notice that the inner byte-read loop is stupid. It's true but doesn't matter.  
This is optimized to tetris-pack into the fewest possible 40-column lines, with all platform differences in the first line.  

This has hard-coded TOP & END values that are only valid for the legacy RAMDSK v2 and the latest RAMDSK, only because the latest version is artificially padded to come out to the same length as the legacy version just for this reason.  
If you compile with other options or modified code, the makefile also generates RBOOT.xxx that is correct for the generated RAMxxx.CO (the same as these but with different TOP & END numbers in the 1st line)  
RAM200.CO v1 would also need different values than these.

## RBOOT for 100, 102, K85, & M10
```
1 CLEAR0,61558:T=61558:E=62957:OUT129,2
2 FORA=0TO15:N=INP(131):NEXT:FORA=TTOE
3 POKEA,INP(131):IFA=T+1007THENOUT129,1
4 ?".";:NEXT:SAVEM"RAMDSK",T,E,T
```

## RBOOT for 200  
```
1 CLEAR0,59715:T=59715:E=61101:OUT129,2
2 FORA=0TO15:N=INP(131):NEXT:FORA=TTOE
3 POKEA,INP(131):IFA=T+1007THENOUT129,1
4 ?".";:NEXT:SAVEM"RAMDSK",T,E,T
```

## multi-boot
Either of above may be adjusted to boot from a different bank instead of bank0.  
For bank 1, 2, or 3, change all (2) occurances of OUT129 to OUT133, 137, or 141.  
Example, Model 200 reinstalling from Bank1 (requres RAM200.CO saved as the first file in bank1):  
```
1 CLEAR0,59715:T=59715:E=61101:OUT133,2
2 FORA=0TO15:N=INP(131):NEXT:FORA=TTOE
3 POKEA,INP(131):IFA=T+1007THENOUT133,1
4 ?".";:NEXT:SAVEM"RAM200",T,E,T
```

You could get fancy and support for example both model 102 and model 200 at the same time on the same device by for example saving RAM100.CO to Bank0 and RAM200.CO to Bank1.

# Using RAMDSK
Usage is mostly pretty self-explanatory.  

A few things that aren't explained on-screen.  

* On legacy version RAMDSK v2 if you keep holding the Enter key down while RAMDSK starts up, then it switches from bank0 to bank1 before anything else, so you essentially start in bank1 instead of bank0.
  This code is omitted from the current version.  

* On startup RAMDSK looks at the first 2 bytes of the disk to tell if the disk is formatted or not.  
  If it does not see a valid format stamp (0x40 0x04), it asks if you want to format the disk.  
  You can answer Y or N here.  
  Don't panic if you get this on a device that is supposed to already be formatted and have files.  
  Just be sure to answer N! On the current version there is also an extra confirmation step so you even get 2 chances to avoid an unwanted format.  
  After you decline to format, you will get a chance to do a non-destructive repair instead.

* [The format stamp is easily corrupted](RAMPAC.001),  
  When this happens, you will get the format prompt above. Don't Panic.  
  If you answer N to format, then next it asks "Repair?"  
  If you answer Y to repair, it just re-writes the format stamp without touching anything else.

  <!-- (As Paul Globman said above, it was not a great decision to use byte0 for this critical purpose (or any purpose) for exactly this reason, but that's what NODE did so we just have to deal with it.)  -->
  <!-- What Paul mentions about the latch being volatile is probably a good thing.  
  Better to always corrupt the same byte 0 than random bytes all over.  
  The latch losing power is like parking the heads. -->
  <!--
  You know what? now that we have source and can hack on RAMDSK, who cares about strict compatibility with the NODE ROM any more?
  TODO: maybe one of these, or something else:  
   - Use only the 2nd byte and ignore the 1st byte (but keep resetting it just to maximise compatibility with old binaries and node rom because no reason not to)  
     Maybe to make it less likely for a random data byte to match the valid format value, make it a checksum over the fcb table? That will definitely break compatibility because the legacy software is looking for exactly 0x40 0x04
   - Ignore both bytes 0 & 1 and don't even perform a format check, just assume it's formatted and display the gibberish if it's not. Format by providing a format button.  
     All of the actual load/save/kill/etc functions must still perform a test-else-abort on the spot every time just before their actual work, because the device is externally attached and can be disconnected at any time. 
     It's harmless to let the file listing display giberish. It's not harmless to let any other function read and operate on gibberish.
   - The 2nd 512 bytes of block0 are un-used, use some of them?
  -->

* Finally it displays a screen full of disk filenames.  
The files are not listed in the order they exist on the device, nor alphabetically. First all of the .BA files are listed, then the .CO files, then the .DO files.

* If there are more than one page of files on the disk, press Enter to see the next page of filenames.

* You can press LABEL to format the disk.

* All other actions done by the labelled F-keys.

F1 Bank - Switch between banks of 256k each.  
  Only functional on a device that has more than 256k.  
  The current bank number is displayed at the top of the screen.

F2 Load - Copy a file from disk to ram.

F3 Save - Copy a file from ram to disk.

F4 Name - Rename a file on disk.

F5 Kill - Delete a file on disk.

F8 Menu - Exit RAMDSK.

# Filesystem Data Structure

This is not previously documented that I have found.  
This comes from a combination of exploring a formatted device with [RAMPAC Inspector](../CRI), and from disassembling RAMDSK.

At the hardware level the device provides 256 1k blocks (per bank)

The NODE ROM and RAMDSK use that space to store files this way:

Block 0 is reserved for the format stamp and FCB table.

Blocks 1-255 are available for files.

The format stamp is the first 2 bytes of block 0: `0x40 0x04`  
NODE ROM and RAMDISK look for this to decide if a device is formatted or not.

The FCB table is the next 255 pairs of bytes of block 0.

Each FCB corresponds to a block.  
fcb 1-255 <-> block 1-255  

Each FCB is 2 bytes: `attr next`

`attr` is a file attribute  
the same value used by the MKDIRENT routine in the system rom.  
(0x2239 in the North American Model 100 system rom)  

  0x00 = block exists and is available  
  any value > 0x00 = block is not available  
  0x20 = block is part of a file but is not the first block in the file  
  0x40 = block does not exist or is otherwise not available  
  (block 0, blocks 127-255 on a device with only 128k of sram)  
  0x80 = first block of a .BA file  
  0xD0 = first block of a .CO file  
  0xA0 = first block of a .DO file

`next` is the block number of the next block in the file.  
  0x00 = file ends in this block, or block is not part of a file.

Bytes 512-1024 of block 0 are not used.  
You could store 512 bytes of hidden secrets there :)

For the remaining blocks 1-255:

If a block is the first block in a file, then the first 10 bytes of the block contain the RAMDSK file header:  
0-5: 6 bytes filename base  
6-7: 2 bytes filename extension  
8-9: 2 bytes file length, not including the 10-byte header  
The remaining 1014 bytes are file data

If a block is part of a file but not the first block in the file, then the block is all file data starting right at byte 0 and ending wherever the file length says to end.  
The bytes after the end of the file to the end of that block are not used.

The first block of a file is located by scanning the FCB table for all FCBs that have an `attr` matching the file you want, then reading the 10-byte header of each potential matching block until finding the matching filename.

The remaining blocks in a file are found by following the chain of `next` block pointers until filesize runs out and/or `next`=0x00. The FCB for the 1st block points to the 2nd block, the FCB for the 2nd block points to the 3rd, etc.

This means a bank may contain up to 255 1k files, or 1 255k file.

| block | contents |
| --- | --- |
|0|FCB table|
|1|file data|
|...|...|
|255|file data|

Block 0 / FCB table:

|byte#|1 byte|1 byte|desc|
| --- | --- | --- | --- |
|0-1|0x40|0x04|Stamp|
|2-3|attr|next|FCB 1|
|4-5|attr|next|FCB 2|
|...|...|...|...|
|509-510|attr|next|FCB 255|
|512-1024|||unused|

First block of any file:

|basename<br>6 bytes|extension<br>2 bytes|filesize<br>2 bytes|data<br>1014 bytes|
| --- | --- | --- | --- |
|RAMDSK|CO|0x7E 0x05|...|

Any other block:

|data<br>1024 bytes|
| --- |
|...|

# Assembly Source

[src/](src/)

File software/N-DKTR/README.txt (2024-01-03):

2024 Brian K. White

Two notes about N-DKTR

1 - Warning: Do not run N-DKTR at all if the NODE has arbitrary raw data that isn't
a filesystem made by RAMDSK or the NODE ROM.

It appears to overwrite the first 2 bytes of bank 0 block 0 
with the filesystem formatted flag bytes, immediately on startup,
without asking if it's ok or doing any other kind of sanity check,
without the user invoking any functions or responding to any prompts.

This is fine if the device is supposed to have a filesystem,
but if the device is supposed to have arbitrary raw data,
then the first two bytes of data are destroyed.

Since it happens immediately on startup without asking or giving any chance to prevent it,
the only way to avoid losing data is don't run N-DKTR at all in the first place.

(Or modify N-DKTR to improve that behavior, which should be simple.)

2 - Does not support bank1 or >256k.

It looks like it probably could be added fairly easily.

The interactions with the device appear to all be in plain BASIC
so it should be easy to modify all the OUT129 to OUTX and add code to
select X=129 or X=133.

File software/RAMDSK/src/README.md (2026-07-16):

# Assembly Source for RAMDSK
Originally started as a disassembly of Paul Globman's RAM100.CO and RAM200.CO v2

RAMDSK.S85 is the main source  
100/200/K85/M10.S85 are platform headers  
Makefile uses [z88dk](https://github.com/z88dk/z88dk) to compile the asm to RAMxxx.CO, and co2ba.sh from [dl2](https://github.com/bkw777/dl2) to generate RAMxxx.DO  

Changes from the legacy version:  
 * Supports 4 banks / 1 Meg  
 * Kyotronic KC-85  
 * Olivetti M-10  
 * Bank-detect only runs once on start-up vs on every bank-switch  
 * Bank-detect preserves pre-existing disk data so non-ramdsk data is not corrupted  
 * Format & Repair both now have an extra confirm sure prompt  
 * Can trigger format/repair manually by pressing the LABEL key  
 * Answering N to both format & repair no longer exits the app  
 * F8 exit key now also works at the format/repair/sure prompts  
 * Several bits of dead code found and removed  
 * Several small refactors  
 * Binary length & origin artificially match the legacy binary by default for the sake of RBOOT.BA  

Makefile generates all of the following for each platform xxx = 100, 200, K85, M10:  
* RAMxxx.CO - binary executable  
* RAMxxx.DO - BASIC loader that contains and installs RAMxxx.CO  
* RAMxxx.calls - addresses to the main functions that can be CALLed from BASIC or another program  
* RBOOT.xxx - BASIC code that can be manually typed in to reinstall RAMxxx.CO from the device itself after a hard reset  

## Build
Build all: .CO & .DO for 100, 200, K85, & M10  
`make clean all`

## Build a custom relocated binary
Specify desired END address with `XFLAGS='-DHIMEM=addr'`  
`make clean 200 XFLAGS='-DHIMEM=60357'`

## Install  
`make load_100` or _200 _K85 _M10  
Which is just shorthand for `dl -v -b RAMxxx.DO`

Or, on Windows (if not using Cygwin/MSYS2), use the same .DO files with [tsend](http://github.com/bkw777/tsend)

## RBOOT.xxx
RBOOT.BA is an optional way to re-install RAMDSK after a hard reset, by loading it from the device itself without needing a computer or tape or TPDD. You can type-in the 4-line BASIC and that will load the file from the device, as long as RAMxxx.CO is the first file on the device.

The makefile generates RBOOT.xxx with the correct TOP & END addresses for the generated binary.  
IF you build without `-DMATCH_LEGACY_CO_HEADER`, then only the generated RBOOT.xxx will be correct for that binary.  

If you build with `-DMATCH_LEGACY_CO_HEADER` (the default), then the new binary is artificially made to match the old binary, and the RBOOT.BA code in the main readme and silkscreened on MiniNDP PCB which is hard-coded for the legacy binary's length and origin, is also correct for the new binary.  
For K85, use the code for 100 with RAMK85.CO  
For M10, use the code for 100 with RAMM10.CO  

## Legacy Reference Versions

Preserved original binaries:  
[../RAM100/orig/](../RAM100/orig/) and [../RAM200/orig/](../RAM200/orig/)

Assembly source that reproduces the original binaries exactly:  
[../RAM100/orig/disasm/](../RAM100/orig/disasm/) and [../RAM200/orig/disasm/](../RAM200/orig/disasm/)

## programming references
rom addresses cross map, ide support for 8085 asm, system roms & docs  
https://github.com/bkw777/m100_dev

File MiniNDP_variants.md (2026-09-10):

# Other MiniNDP Variants
There are a few other versions of the card just to allow for different parts availability and different soldering difficulty.  
They all work the same from a software point of view, and all are tested.

### SL1M - slim 1 meg
* Same as EZ1M, just with TSOP & TSSOP components.  
* Allows to make a thin card.

Use the thinner CR2016 version of the cover with this.  
The battery holder is technically for CR2012, but you can stuff a CR2016 in it.

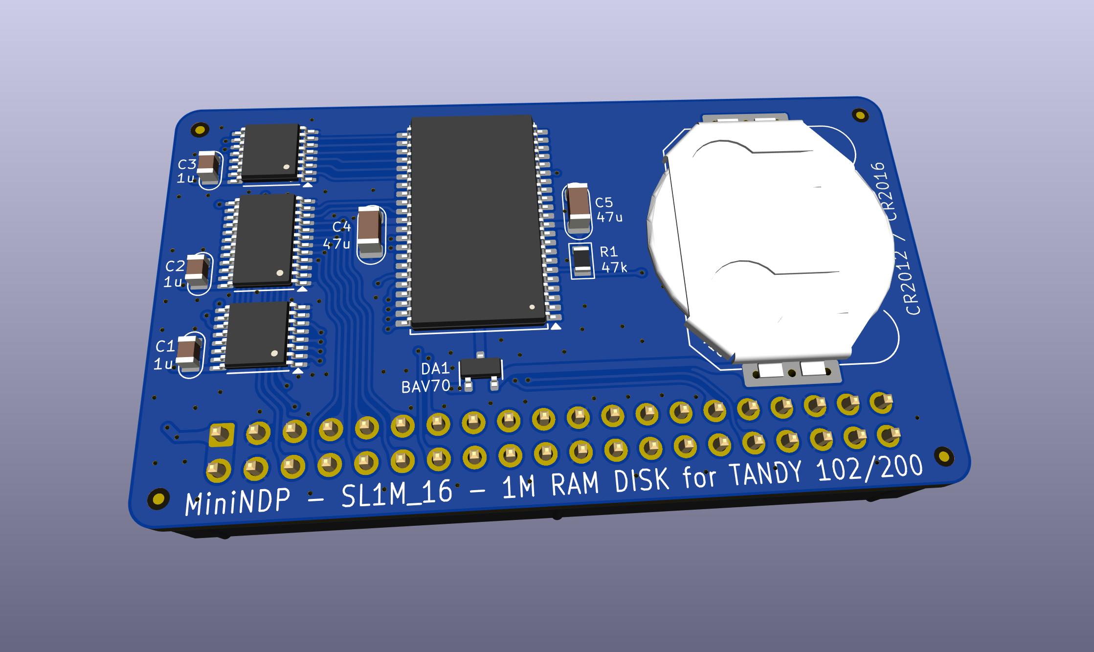
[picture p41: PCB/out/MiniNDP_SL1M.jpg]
  
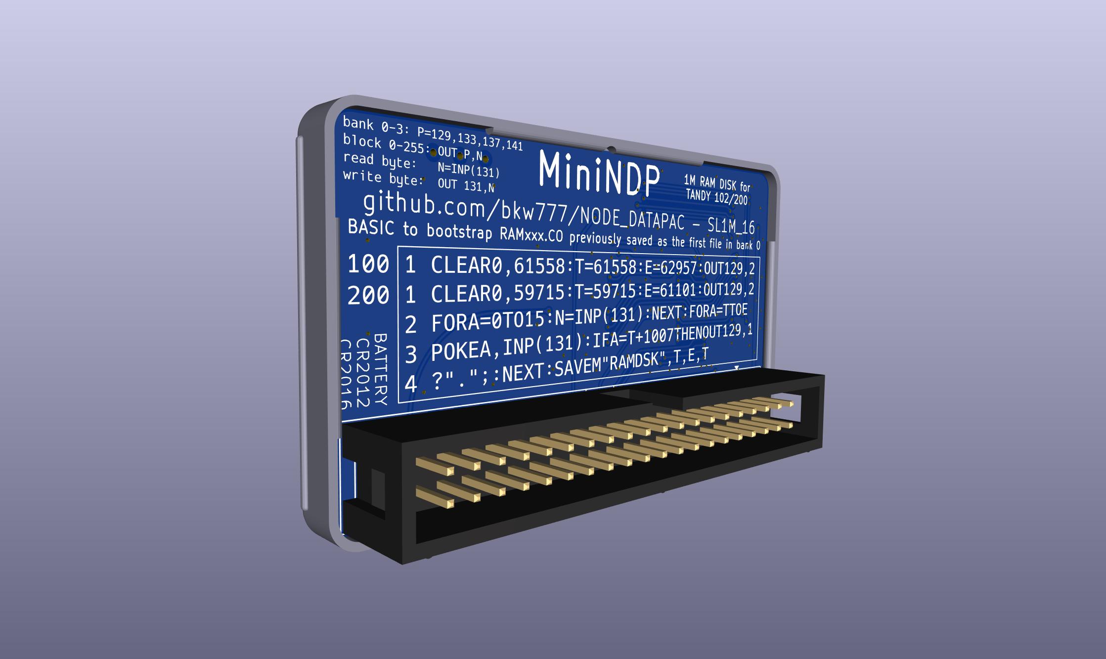
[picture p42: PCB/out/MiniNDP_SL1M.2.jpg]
  
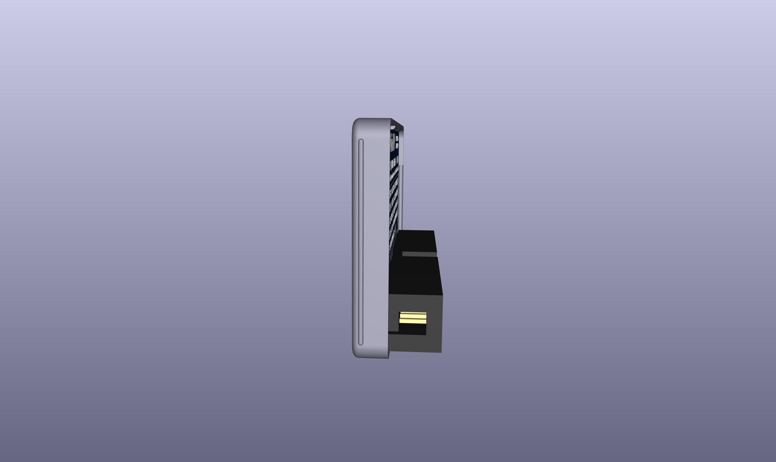
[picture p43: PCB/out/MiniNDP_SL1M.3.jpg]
  
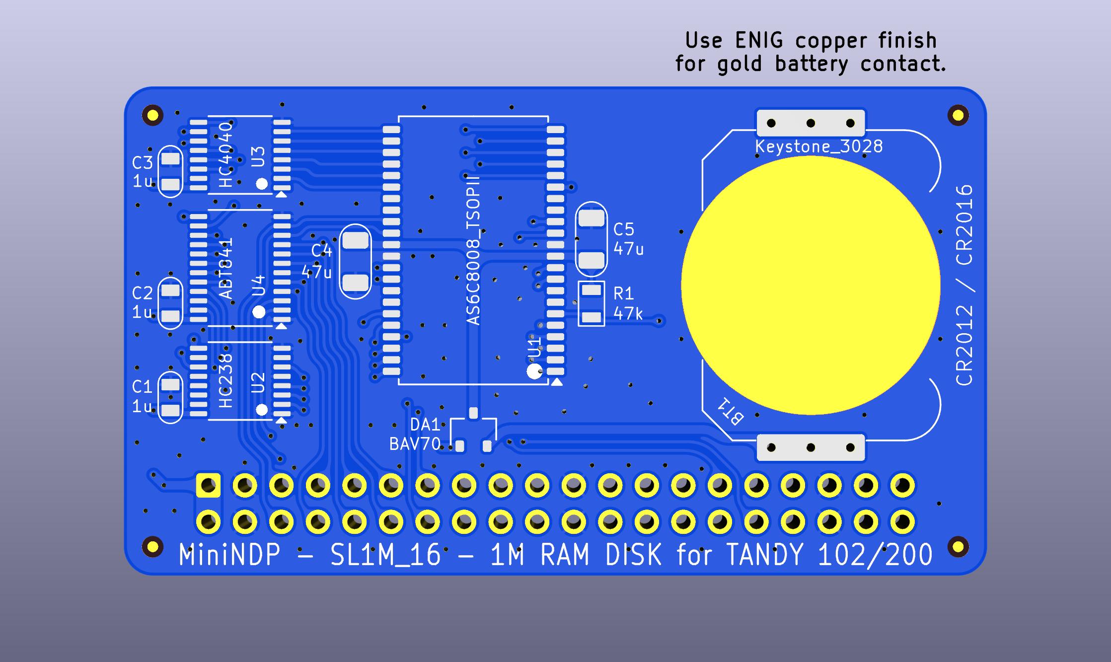
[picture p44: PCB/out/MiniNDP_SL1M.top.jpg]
  
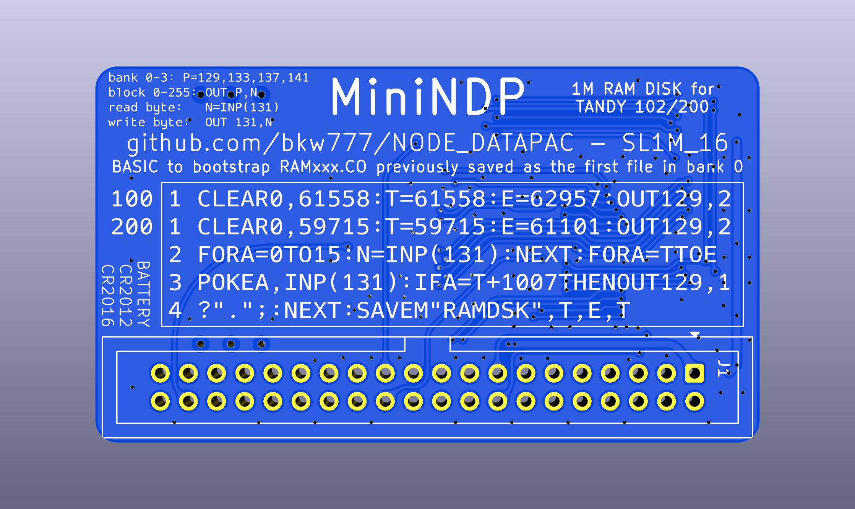
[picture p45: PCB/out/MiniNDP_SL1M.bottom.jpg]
  
  
[MiniNDP_SL1M.bom.csv](PCB/out/MiniNDP_SL1M.bom.csv)  
[MiniNDP SL1M_16 PCB @ OSHPark](https://oshpark.com/shared_projects/UxbSsLw0)  
THIN Cover: [MiniNDP_Cover_THIN.stl](COVER/out/MiniNDP_Cover_THIN.stl)  
[THIN cover @ JawsTec](https://shop.jawstec.com/3d-printed-minindp-sl1mt512-cover_p659.php)

## T512 - TSOP 128k/256k/512k 

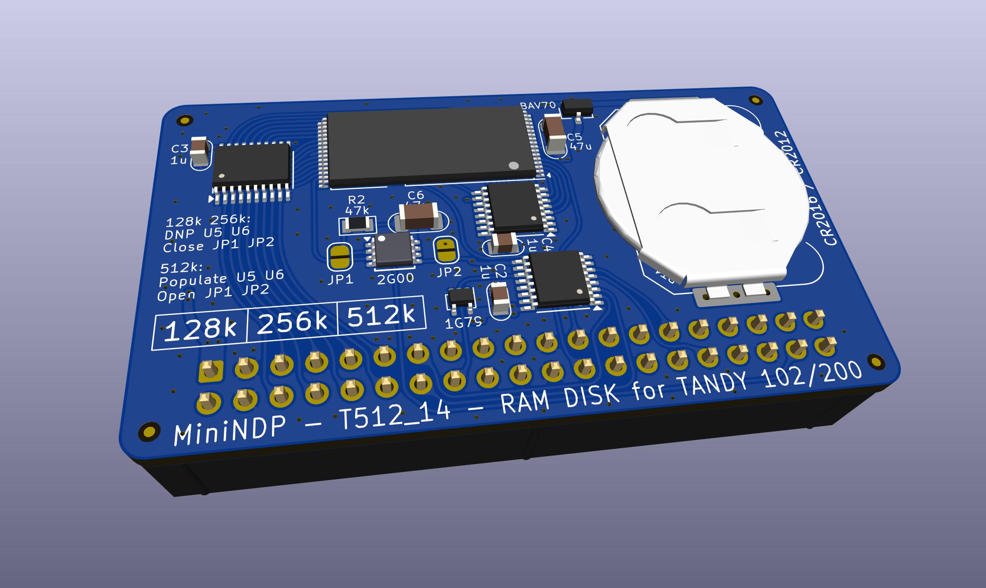
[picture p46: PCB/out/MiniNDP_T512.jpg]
  
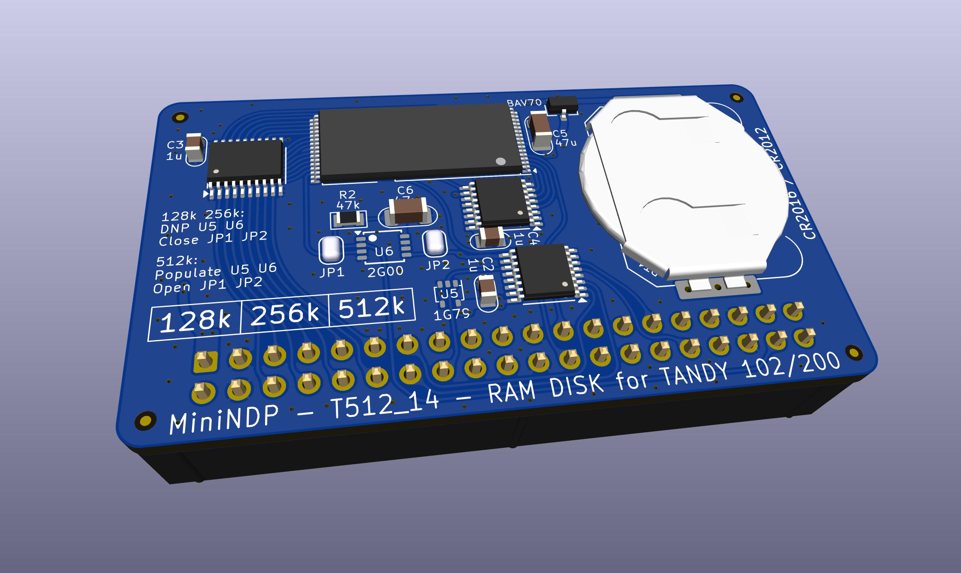
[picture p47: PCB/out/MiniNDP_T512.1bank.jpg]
  
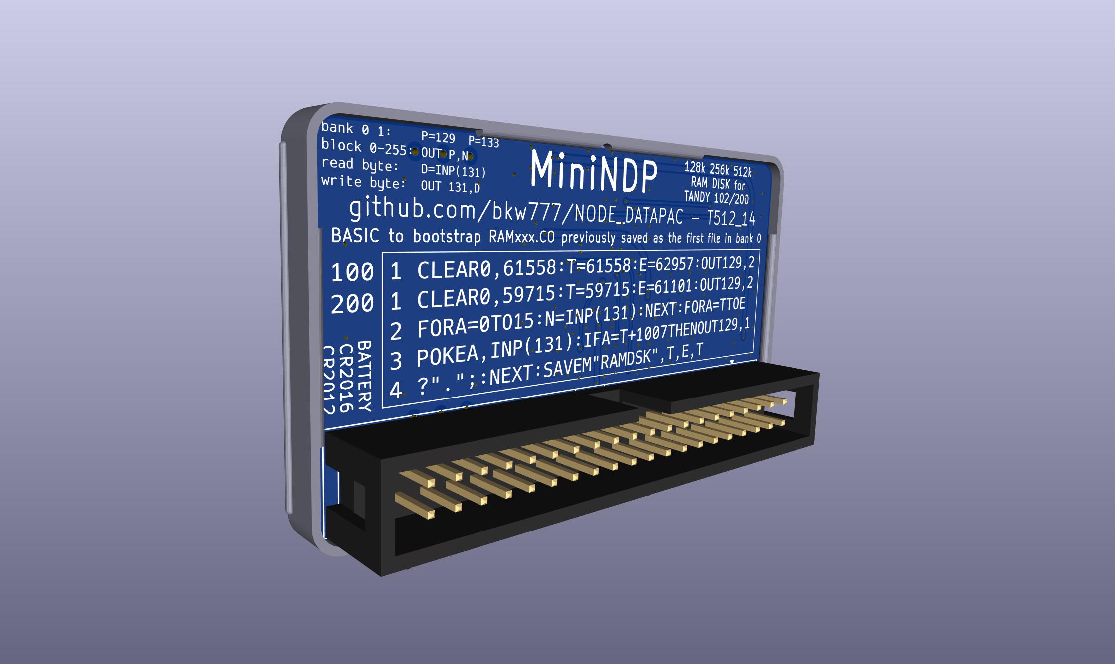
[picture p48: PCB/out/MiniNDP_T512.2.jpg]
  
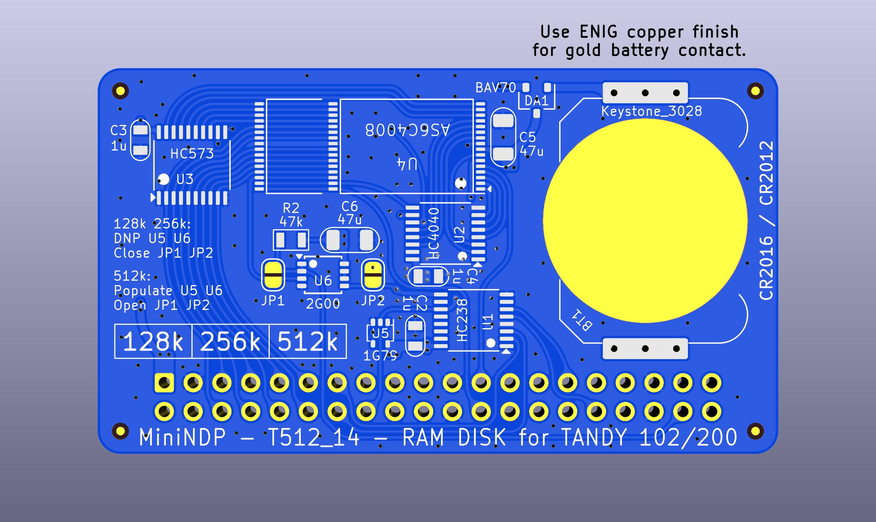
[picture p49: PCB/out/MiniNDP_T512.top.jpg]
  
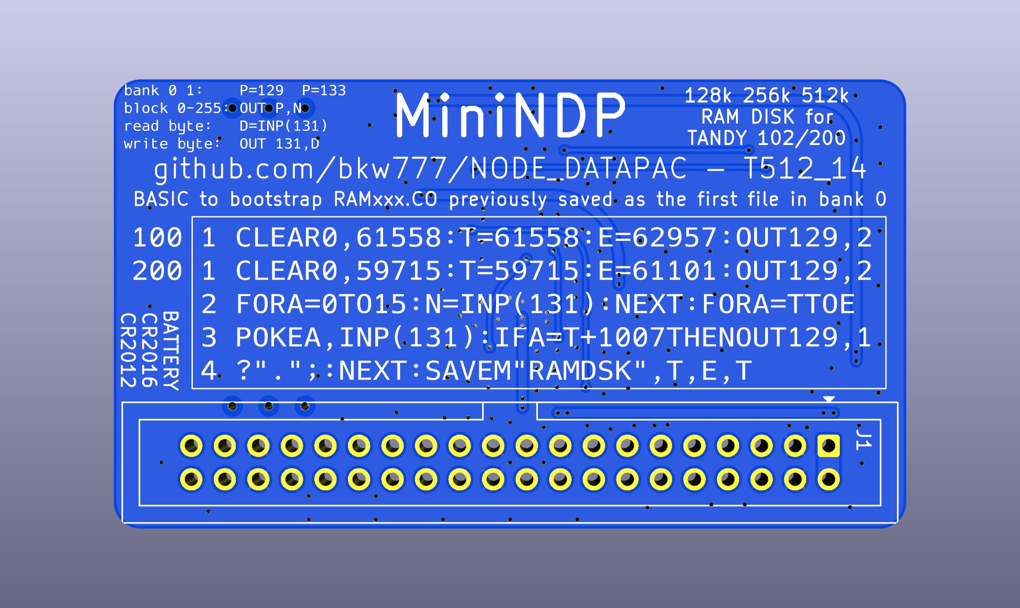
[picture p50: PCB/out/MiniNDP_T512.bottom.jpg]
  
  
[MiniNDP_T512.bom.csv](PCB/out/MiniNDP_T512.bom.csv)  
[MiniNDP T512_14 @OSHPark](https://oshpark.com/shared_projects/DEzuT3Ux)  
Cover: Use either the standard cover or the thin cover depending on if you install the CR2032 holder or the CR2012/CR2016 holder  
[THIN cover @ JawsTec](https://shop.jawstec.com/3d-printed-minindp-sl1mt512-cover_p659.php)

### EZ512 - easy-build 512K
* All larger parts for easier hand-soldering.  
* 1M SOIC/SOJ sram is getting uncommon and expensive.  

It requires an additional chip vs the 1M because the 512K sram doesn't have a CE2 pin.

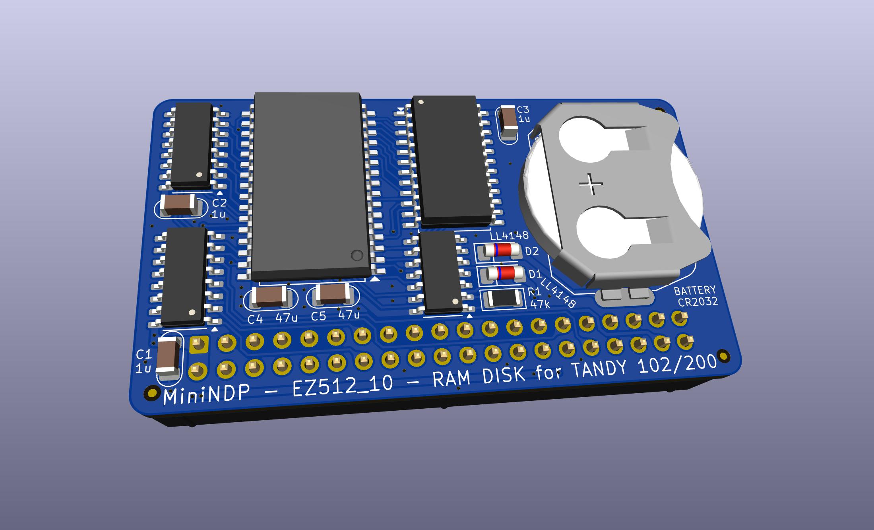
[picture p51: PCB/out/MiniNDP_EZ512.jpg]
  
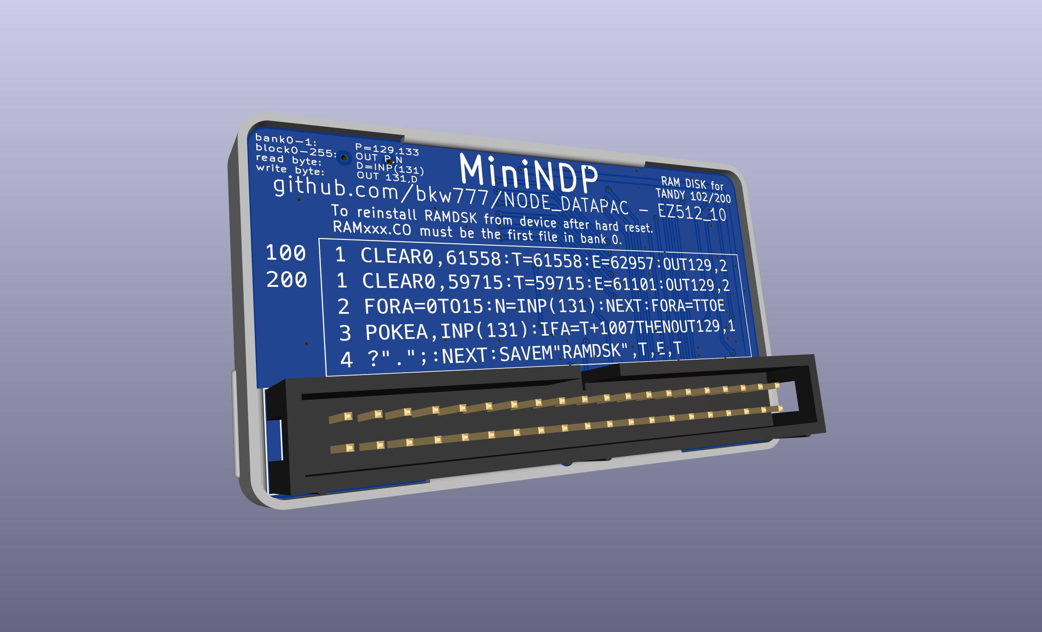
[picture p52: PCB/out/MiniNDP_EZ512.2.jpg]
  
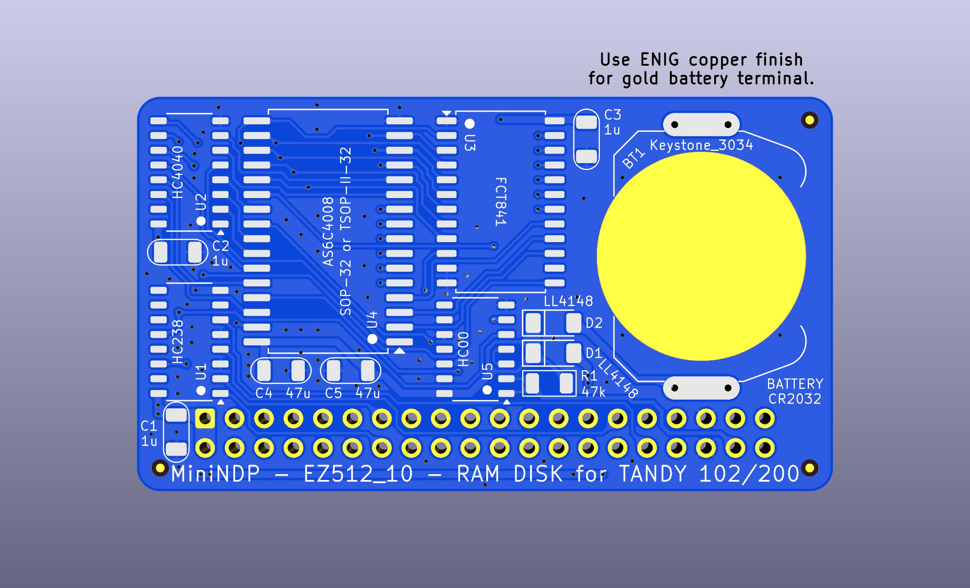
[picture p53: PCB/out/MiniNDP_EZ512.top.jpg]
  
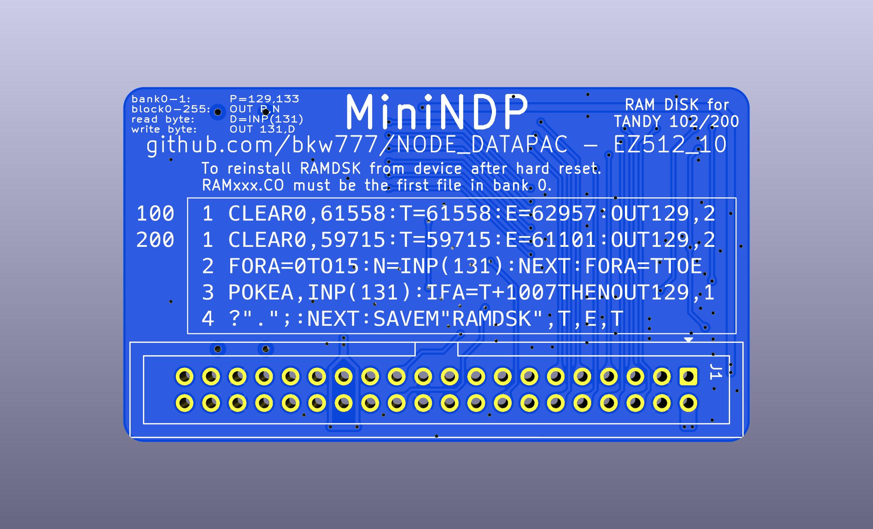
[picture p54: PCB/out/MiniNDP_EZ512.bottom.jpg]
  
  
[MiniNDP_EZ512.bom.csv](PCB/out/MiniNDP_EZ512.bom.csv)  
Cover: Use the standard EZ1M cover

<!-- 
### MiniNDP "OG"
* Circuit is more like the original NODE version.  
* Components are more common & available.  
* Supports 512K, 256K, or 128K.  
* Supports CR2032, CR2016, or CR2012, so you can choose if you want more battery life or a thinner card.  
* Supports a big tantalum cap for more battery-change grace period.

![](PCB/out/MiniNDP_OG.jpg)  
![](PCB/out/MiniNDP_OG.top.jpg)  
![](PCB/out/MiniNDP_OG.bottom.jpg)  
![](PCB/out/MiniNDP_OG.svg)  
[MiniNDP_OG.bom.csv](PCB/out/MiniNDP_OG.bom.csv)  
Cover: Use either the standard cover or the thin cover depending on if you install the CR2032 holder or the CR2012 holder

## Battery Options
Max battery vs thinnest card  
|BATTERY|life|holder|height|tantalum|grace(1)|
|---|---|---|---|---|---|
|CR2032|7-13 years|[Keystone 3034](https://www.digikey.com/en/products/detail/keystone-electronics/3034/4499289)<br>TE/Linx BAT-HLD-001-SMT<br>Adam Tech BH-67<br>MPD BK-912|4.1mm|[TAJC227K010RNJ](https://www.digikey.com/en/products/detail/kyocera-avx/TAJC227K010RNJ/1833766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) - 6032-28 220u 10v|1 minute|
|CR2016|3-6 years|[TE BAT-HLD-002-SMT](https://www.digikey.com/en/products/detail/te-connectivity-linx/BAT-HLD-002-SMT/3044011)(2)|2.8mm|[TLJW157M010R0200](https://www.digikey.com/en/products/detail/kyocera-avx/TLJW157M010R0200/929982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) - 6032-15 150u 10v|40 seconds|
|CR2012|1.5-3 years|[Keystone 3028](https://www.digikey.com/en/products/detail/keystone-electronics/3028/4499284) (picture is wrong, part is correct)|1.7mm|[TLJW157M010R0200](https://www.digikey.com/en/products/detail/kyocera-avx/TLJW157M010R0200/929982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) - 6032-15 150u 10v|40 seconds|

(1) Grace is the battery-change grace period provided by C1.  
With no battery installed, how long it takes for C1 to discharge from 2.0v (coin cell about to die) down to 1.5v (sram data retention).

(2) This CR2016 holder is taller than needed for a CR2016, so much so that you may as well just use a full CR2032 holder and get double the years.  
But you can actually stuff a CR2016 into the CR2012 holder. It's just a stiff fit.  
You can adjust the CR2012 holder to fit perfect so there will be less strain on the solder joints by either bending the tabs down slightly before soldering,  
or by soldering with the holder clamped over a piece of PCB in the holder as a filler block in place of a battery. PCB is 1.6mm just like CR2016.

CR2032 height
![](PCB/out/MiniNDP_256_CR2032.jpg)

CR2016 height (nominally a CR2012 holder, but can take a CR2016)  
![](PCB/out/MiniNDP_256_CR2016.jpg)
-->

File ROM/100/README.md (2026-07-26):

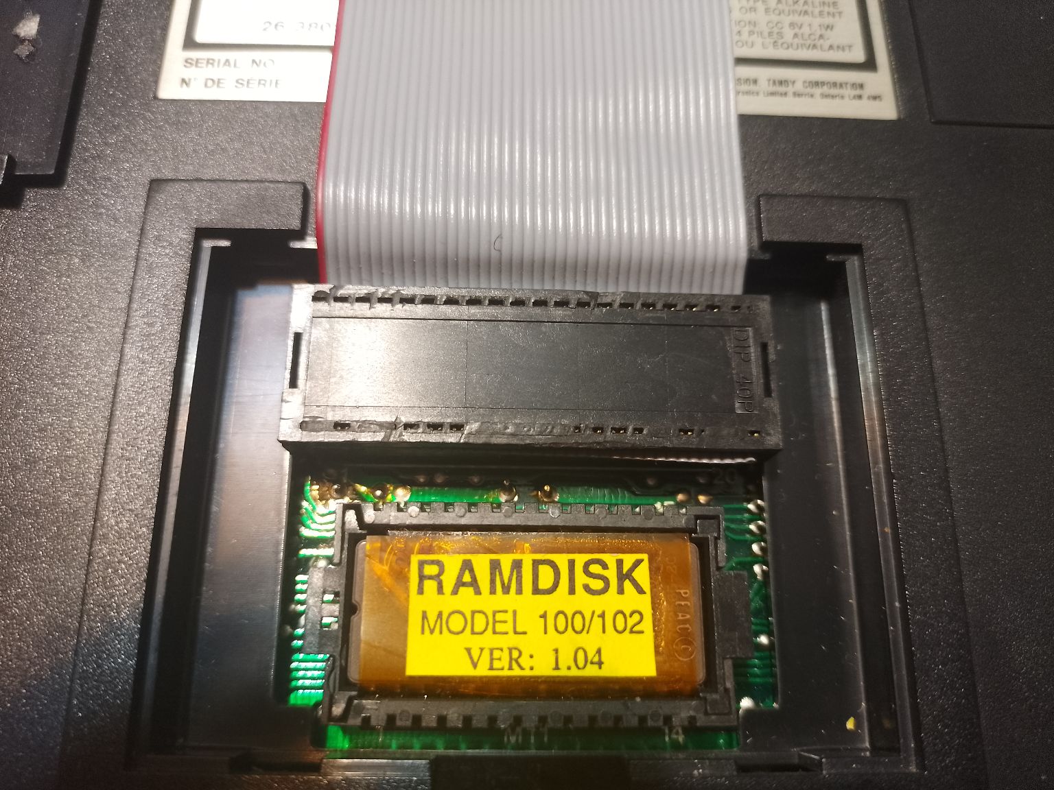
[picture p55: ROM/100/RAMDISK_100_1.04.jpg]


Oct 2025 - Thanks to Michael Brigham for dumping this rom which was otherwise lost.
The text file manual was also lost until the rom was available to regenerate it.

This ROM is not needed to use the hardware. RAMDSK.CO can be used in place of the ROM.

NODE-DATAPAC-100-1.04.ROM is the NODE option rom v1.04 for 100/102

RAMDSK.DO is a copy of the text file manual created by the rom when it formats a ramdisk

N1DEMO.DO is the ascii basic demo program excerpted out of RAMDSK.DO

N1DEMO.BA is the tokenized basic demo program

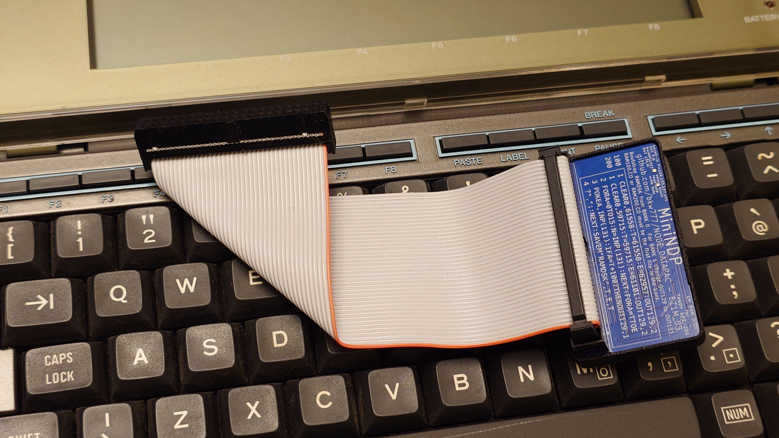
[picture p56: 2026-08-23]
PICS/M10/102_200_M10_0.jpg

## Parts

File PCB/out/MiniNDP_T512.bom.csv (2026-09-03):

Reference | Value | Datasheet | Footprint | Qty | DNP | MPN | Description
BT1 | Keystone_3028 | datasheets/Keystone_3034.pdf | 000_LOCAL:Keystone_3028_3034_bkw | 1 |  | Keystone_3028 | BATTERY RETAINER COIN 20MM x 1.6MM SMT
C2,C3,C4 | 1u | datasheets/CL21B105KAFNNNE.pdf | 000_LOCAL:C_0805 | 3 |  | CL21B105KAFNNNE | CAP CER 1UF 25V X7R 0805
C5,C6 | 47u | datasheets/TDK_MLCC_Cxxxx.pdf | 000_LOCAL:C_1206 | 2 |  | C3216X5R1E476M160DC | CAP CER 47UF 25V X5R 1206
DA1 | BAV70 | datasheets/BAV70.pdf | 000_LOCAL:SOT-23 | 1 |  | BAV70-7-F | DIODE ARRAY GP 75V 150MA SOT23-3
J1 | Conn_02x20_Odd_Even | datasheets/2x20_male_boxed.pdf | 000_LOCAL:IDC-Header_2x20_P2.54mm_Vertical | 1 |  | 302-S401 | CONN HEADER VERT 40POS 2.54MM
R2 | 47k | datasheets/sei-rmcf_rmcp.pdf | 000_LOCAL:R_0805 | 1 |  | RMCF0805FT47K0 | RES 47K OHM 1% 1/8W 0805
U1 | HC238 | datasheets/HC238.pdf | 000_LOCAL:TSSOP-16 | 1 |  | 74HC238PW,118 | IC DECODER/DEMUX 1 X 3:8 16SO
U2 | HC4040 | datasheets/4040.pdf | 000_LOCAL:TSSOP-16 | 1 |  | 74HC4040PW,118 | IC BINARY COUNTER 12-BIT 16SO
U3 | HC573 | datasheets/HC573.pdf | 000_LOCAL:TSSOP-20 | 1 |  | 74HC573PW,118 | 8-bit Latch 3-state outputs
U4 | AS6C4008 | datasheets/AS6C4008.pdf | 000_LOCAL:TSOP32-dual | 1 |  | AS6C4008-55STIN | IC SRAM 512Kx8 PARALLEL STSOP-32
U5 | 1G79 | datasheets/LVC1G79.pdf | 000_LOCAL:SOT-353_SC-70-5 | 1 |  | 74LVC1G79GW,125 | IC FF D-TYPE SNGL 1BIT 5TSSOP
U6 | 2G00 | datasheets/2G00.pdf | 000_LOCAL:TSSOP-8_3x3mm_P0.65mm | 1 |  |  | Dual NAND Gate, Low-Voltage CMOS

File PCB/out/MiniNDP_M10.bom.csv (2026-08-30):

Reference | Value | Datasheet | Footprint | Qty | DNP | MPN | Description
BT1 | Keystone_3028 | datasheets/Keystone_3028.pdf | 000_LOCAL:Keystone_3028_3034_bkw | 1 |  | Keystone 3028 | SMT 20mm x 1.6mm coin cell holder
C1,C2,C3 | 1u | datasheets/CL21B105KAFNNNE.pdf | 000_LOCAL:C_0805 | 3 |  | CL21B105KAFNNNE | CAP CER 1UF 25V X7R 0805
C4,C5 | 47u | datasheets/TDK_MLCC_Cxxxx.pdf | 000_LOCAL:C_1206 | 2 |  | C3216X5R1E476M160DC | CAP CER 47UF 25V X5R 1206
DA1 | BAV70 | datasheets/BAV70.pdf | 000_LOCAL:SOT-23 | 1 |  | BAV70-7-F | DIODE ARRAY GP 75V 150MA SOT23-3
J1 | Conn_02x20_Odd_Even | datasheets/M20-611.pdf | 000_LOCAL:PinSocket_2x20_P2.54mm_Vertical | 1 |  | M20-6112045 | CONN SOCKET VERT THT 02x20 2.54mm pitch 11mm height
R1 | 47k | datasheets/sei-rmcf_rmcp.pdf | 000_LOCAL:R_0805 | 1 |  | RMCF0805FT47K0 | RES 47K OHM 1% 1/8W 0805
U1 | AS6C8008_TSOPII | datasheets/AS6C8008.pdf | 000_LOCAL:TSOP-II-44 | 1 |  | AS6C8008-55ZIN | IC SRAM 1Mx8 PARALLEL 5v TSOP-II-44
U2 | HC238 | datasheets/HC238.pdf | 000_LOCAL:TSSOP-16 | 1 |  | 74HC238PW,118 | IC DECODER/DEMUX 1 X 3:8 16SO
U3 | HC4040 | datasheets/4040.pdf | 000_LOCAL:TSSOP-16 | 1 |  | 74HC4040PW,118 | IC BINARY COUNTER 12-BIT 16SO
U4 | ABT841 | datasheets/sn54abt841.pdf | 000_LOCAL:TSSOP-24 | 1 |  | SN74ABT841APW | IC 10BIT LATCH 3-STATE 24-SOIC

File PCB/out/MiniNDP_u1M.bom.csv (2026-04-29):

Reference | Value | Datasheet | Footprint | Qty | DNP | MPN | Description
BT1 | Keystone_3031 | datasheet/Keystone_3031.pdf | 000_LOCAL:Keystone_3031 | 1 |  | Keystone 3031 | Battery Retainer Coin, 10.0mm 1 Cell PC Pin
C1,C2,C3 | 1u | datasheets/CL21B105KAFNNNE.pdf | 000_LOCAL:C_0805 | 3 |  | CL21B105KAFNNNE | CAP CER 1UF 25V X7R 0805
C4 | 47u | datasheets/TDK_MLCC_Cxxxx.pdf | 000_LOCAL:C_1206 | 1 |  | C3216X5R1E476M160DC | CAP CER 47UF 25V X5R 1206
DA1 | BAV70 | datasheets/BAV70.pdf | 000_LOCAL:SOT-23 | 1 |  | BAV70-7-F | DIODE ARRAY GP 75V 150MA SOT23-3
J1 | Model_100_System_BUS | datasheets/TRS-80_Model_100_User_Guide.pdf | 000_LOCAL:DIP-40_PCB | 1 |  | 920-0172-01 | CONN HEADER VERT 40P 2.54MM
R1 | 47k | datasheets/sei-rmcf_rmcp.pdf | 000_LOCAL:R_0805 | 1 |  | RMCF0805FT47K0 | RES 47K OHM 1% 1/8W 0805
U1 | AS6C8008_TSOPII | datasheets/AS6C8008.pdf | 000_LOCAL:TSOP-II-44 | 1 |  | AS6C8008-55ZIN | IC SRAM 1Mx8 PARALLEL 5v TSOP-II-44
U2 | HC238 | datasheets/HC238.pdf | 000_LOCAL:TSSOP-16 | 1 |  | 74HC238PW,118 | IC DECODER/DEMUX 1 X 3:8 16SO
U3 | HC4040 | datasheets/4040.pdf | 000_LOCAL:TSSOP-16 | 1 |  | 74HC4040PW,118 | IC BINARY COUNTER 12-BIT 16SO
U4 | ABT841 | datasheets/sn54abt841.pdf | 000_LOCAL:TSSOP-24_4.4x7.8mm_P0.65mm | 1 |  | SN74ABT841APW | IC 10BIT LATCH 3-STATE 24-SOIC

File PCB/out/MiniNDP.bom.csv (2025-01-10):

Reference | Value | Datasheet | Footprint | Qty | DNP | MPN | Description
BT1 | Keystone_3034 | datasheets/Keystone_3034.pdf | 000_LOCAL:Keystone_3028_3034 | 1 |  | Keystone 3034 | SMT 20mm x 3.2mm coin cell holder
C1,C2,C3,C4,C5 | 1u | datasheets/CL21B105KAFNNNE.pdf | 000_LOCAL:C_0805 | 5 |  | CL21B105KAFNNNE | CAP CER 1UF 25V X7R 0805
C6,C7 | 47u | datasheets/TDK_MLCC_Cxxxx.pdf | 000_LOCAL:C_1206 | 2 |  | C3216X5R1E476M160DC | CAP CER 47UF 25V X5R 1206
D1,D2 | LL4148 | datasheets/ll4148.pdf | 000_LOCAL:D_MiniMELF | 2 |  | FDLL4148 | 50V 1A General Purpose Rectifier Diode
J1 | Conn_02x20_Odd_Even | datasheets/2x20_male_boxed.pdf | 000_LOCAL:IDC-Header_2x20_P2.54mm_Vertical | 1 |  | 302-S401 | CONN HEADER VERT 40POS 2.54MM
R1 | 47k | datasheets/sei-rmcf_rmcp.pdf | 000_LOCAL:R_0805 | 1 |  | RMCF0805FT47K0 | RES 47K OHM 1% 1/8W 0805
U1 | AS6C8008_TSOPII | datasheets/AS6C8008.pdf | 000_LOCAL:TSOP-II-44 | 1 |  | AS6C8008-55ZIN | IC SRAM 1Mx8 PARALLEL 5v TSOP-II-44
U2 | HC238 | datasheets/HC238.pdf | 000_LOCAL:SOIC-16_3.9x9.9mm_P1.27mm | 1 |  | 74HC238D,653 | IC DECODER/DEMUX 1 X 3:8 16SO
U3 | HC4040 | datasheets/4040.pdf | 000_LOCAL:SOIC-16_3.9x9.9mm_P1.27mm | 1 |  | 74HC4040D,653 | IC BINARY COUNTER 12-BIT 16SO
U4 | FCT841 | datasheets/FCT841.pdf | 000_LOCAL:SOIC-24 | 1 |  | CY74FCT841CTSOC | IC 10BIT LATCH 3-STATE 24-SOIC

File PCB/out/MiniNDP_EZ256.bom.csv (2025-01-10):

Reference | Value | Datasheet | Footprint | Qty | DNP | MPN | Description
BT1 | Keystone_3034 | datasheets/Keystone_3034.pdf | 000_LOCAL:Keystone_3028_3034 | 1 |  | Keystone 3034 | SMT 20mm x 3.2mm coin cell holder
C1,C2,C3 | 1u | datasheets/CL05Y105KP6VPN.pdf | 000_LOCAL:C_1206 | 3 |  | CL31B105KAHNNNE | CAP CER 1UF 25V X7R 1206
C4,C5 | 47u | datasheets/TDK_MLCC_Cxxxx.pdf | 000_LOCAL:C_1206 | 2 |  | C3216X5R1E476M160DC | CAP CER 47UF 25V X5R 1206
D1,D2 | LL4148 | datasheets/ll4148.pdf | 000_LOCAL:D_MiniMELF | 2 |  | FDLL4148 | 50V 1A General Purpose Rectifier Diode
J1 | Conn_02x20_Odd_Even | datasheets/2x20_male_boxed.pdf | 000_LOCAL:IDC-Header_2x20_P2.54mm_Vertical | 1 |  | 302-S401 | CONN HEADER VERT 40POS 2.54MM
R1 | 47k | datasheets/TE-4-2176343-5.pdf | 000_LOCAL:R_1206 | 1 |  | CRGCQ1206F47K | RES 47K OHM 1% 1/4W 1206
U1 | HC238 | datasheets/HC238.pdf | 000_LOCAL:SOIC-16_3.9x9.9mm_P1.27mm | 1 |  | 74HC238D,653 | IC DECODER/DEMUX 1 X 3:8 16SO
U2 | HC4040 | datasheets/4040.pdf | 000_LOCAL:SOIC-16_3.9x9.9mm_P1.27mm | 1 |  | 74HC4040D,653 | IC BINARY COUNTER 12-BIT 16SO
U3 | HC573 | datasheets/HC573.pdf | 000_LOCAL:SOIC-20W_7.5x12.8mm_P1.27mm | 1 |  | 74HC573D,653 | IC D-TYPE TRANSP SGL 8:8 20SO
U4 | AS6C2008A | datasheets/AS6C2008A.pdf | 000_LOCAL:TSOP-II-SOP-32_dual | 1 |  | AS6C2008A-55SIN | 256K x 8 High-Speed CMOS Static RAM, 55/70ns, DIP-32/SOP-32

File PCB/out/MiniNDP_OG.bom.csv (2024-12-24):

Reference | Value | Datasheet | Footprint | Qty | DNP | MPN | Description
BT1 | Keystone_3028 | datasheets/Keystone_3034.pdf | 000_LOCAL:Keystone_3028_3034 | 1 |  | Keystone_3028 | BATTERY RETAINER COIN 20MM x 1.6MM SMT
C1 | 150u | datasheets/TAJ.pdf | 000_LOCAL:CP_6032 | 1 |  | TLJW157M010R0200 | CAP TANT 150UF 10% 10V 6032-15
C2,C3,C4,C5 | 1u | datasheets/CL21B105KAFNNNE.pdf | 000_LOCAL:C_0805 | 4 |  | CL21B105KAFNNNE | CAP CER 1UF 25V X7R 0805
DA1 | BAV70 | datasheets/BAV70.pdf | 000_LOCAL:SOT-23 | 1 |  | BAV70-7-F | DIODE ARRAY GP 75V 150MA SOT23-3
J1 | Conn_02x20_Odd_Even | datasheets/2x20_male_boxed.pdf | 000_LOCAL:IDC-Header_2x20_P2.54mm_Vertical | 1 |  | 302-S401 | CONN HEADER VERT 40POS 2.54MM
R1 | 1k | datasheets/RK73.pdf | 000_LOCAL:R_0805 | 1 |  | RK73B2ATTD102J | RES 1K OHM 5% 1/4W 0805
R2 | 47k | datasheets/sei-rmcf_rmcp.pdf | 000_LOCAL:R_0805 | 1 |  | RMCF0805FT47K0 | RES 47K OHM 1% 1/8W 0805
U1,U2,U3 | HC161 | datasheets/HC161.pdf | 000_LOCAL:TSSOP-16 | 3 |  | 74HC161PW,118 | IC BINARY COUNTER 4-BIT 16TSSOP
U4 | HC138 | datasheets/HC138.pdf | 000_LOCAL:TSSOP-16 | 1 |  | 74HC138PW,118 | IC DECODER/DEMUX 1X3:8 16TSSOP
U5 | HC574 | datasheets/HC574.pdf | 000_LOCAL:TSSOP-20 | 1 |  | 74HC574PW,118 | IC FF D-TYPE SNGL 8BIT 20TSSOP
U6 | AS6C4008 | datasheets/AS6C4008.pdf | 000_LOCAL:TSOP32-dual | 1 |  | AS6C4008-55STIN | IC SRAM 512Kx8 PARALLEL STSOP-32
U7 | 1G32 | datasheets/LVC1G32.pdf | 000_LOCAL:SOT-353_SC-70-5 | 1 |  | 74LVC1G32GW,125 | IC GATE OR 1CH 2-INP 5TSSOP
U8 | 1G79 | datasheets/LVC1G79.pdf | 000_LOCAL:SOT-353_SC-70-5 | 1 |  | 74LVC1G79GW,125 | IC FF D-TYPE SNGL 1BIT 5TSSOP

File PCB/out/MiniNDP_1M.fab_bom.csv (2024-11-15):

Reference | Value | Datasheet | Footprint | Qty | DNP | MPN | Description
BT1 | Keystone_3034 | datasheets/Keystone_3034.pdf | 000_LOCAL:Keystone_3028_3034 | 1 |  | Keystone 3034 | SMT 20mm x 3.2mm coin cell holder
C1 | 220u10v | datasheets/TAJ.odf | 000_LOCAL:CP_6032 | 1 |  | TAJC227K010RNJ | CAP TANT 220UF 10% 10V 2312
C2,C3,C4,C5 | 1u | datasheets/CL21B105KAFNNNE.pdf | 000_LOCAL:C_0805 | 4 |  | CL21B105KAFNNNE | CAP CER 1UF 25V X7R 0805
DA1 | BAS70DW-05 | datasheets/BAS70.pdf | 000_LOCAL:SOT-363_SC-70-6_symmetric | 1 |  | BAS70DW-05-7-F | DIODE ARR SCHOTT 70V 70MA SOT363 2-PAIR COMMON-CATHODE
J1 | Conn_02x20_Odd_Even | datasheets/2x20_male_boxed.pdf | 000_LOCAL:IDC-Header_2x20_P2.54mm_Vertical | 1 |  | 302-S401 | CONN HEADER VERT 40POS 2.54MM
R1 | 1k | datasheets/RK73.pdf | 000_LOCAL:R_0805 | 1 |  | RK73B2ATTD102J | RES 1K OHM 5% 1/4W 0805
R2,R3 | 47k | -- mixed values -- | 000_LOCAL:R_0805 | 2 |  | RMCF0805FT47K0 | RES 47K OHM 1% 1/8W 0805
U1,U2,U3 | HC161 | datasheets/HC161.pdf | 000_LOCAL:TSSOP-16 | 3 |  | 74HC161PW,118 | IC BINARY COUNTER 4-BIT 16TSSOP
U4 | HC138 | datasheets/HC138.pdf | 000_LOCAL:TSSOP-16 | 1 |  | 74HC138PW,118 | IC DECODER/DEMUX 1X3:8 16TSSOP
U5 | FCT821 | datasheets/CY74FCT821T.pdf | 000_LOCAL:SOIC-24 | 1 |  | CY74FCT821BTSOC | IC FF D-TYPE SNGL 10BIT 24SOIC
U6 | AS6C8008_TSOPII | datasheets/AS6C8008.pdf | 000_LOCAL:TSOP-II-44 | 1 |  | AS6C8008-55ZIN | IC SRAM 1Mx8 PARALLEL TSOP-II-44
U7 | 1G32 | datasheets/LVC1G32.pdf | 000_LOCAL:SOT-353_SC-70-5 | 1 |  | 74LVC1G32GW,125 | IC GATE OR 1CH 2-INP 5TSSOP

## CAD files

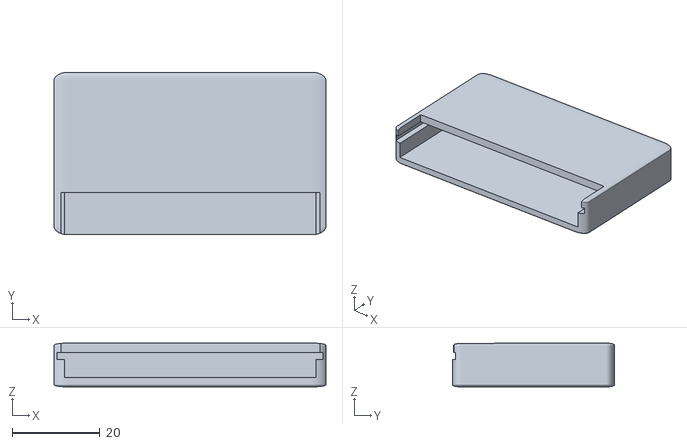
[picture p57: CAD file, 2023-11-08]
COVER/CONTRIB/MiniNDP_FDS_slip_cover.stl
62.0 x 37.0 x 10.0

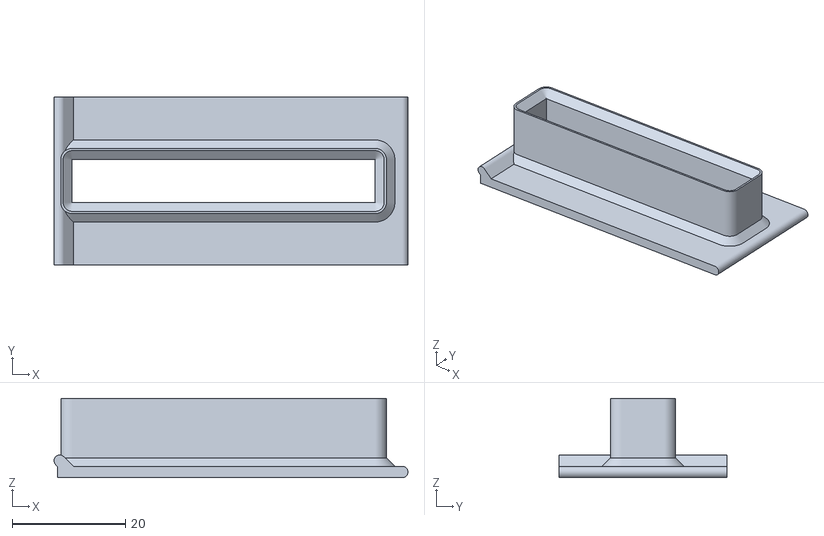
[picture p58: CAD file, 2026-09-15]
COVER/out/M10_BUS_Filler_Plate.stl
62.4 x 29.6 x 14.0

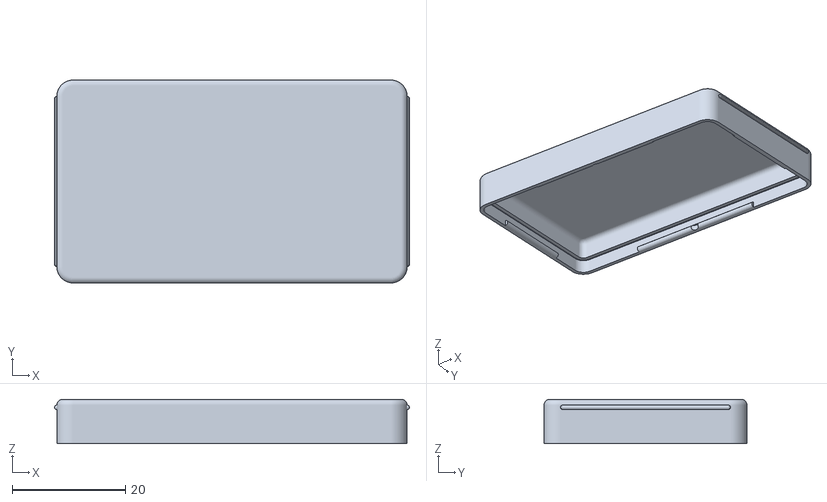
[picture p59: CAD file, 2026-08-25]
COVER/out/MiniNDP_Cover.stl
62.6 x 35.8 x 7.80

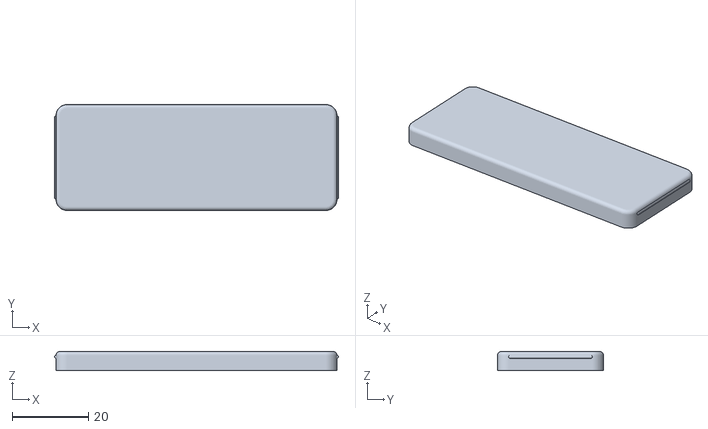
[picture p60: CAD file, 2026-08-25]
COVER/out/MiniNDP_Cover_M10.stl
74.6 x 27.8 x 5.00

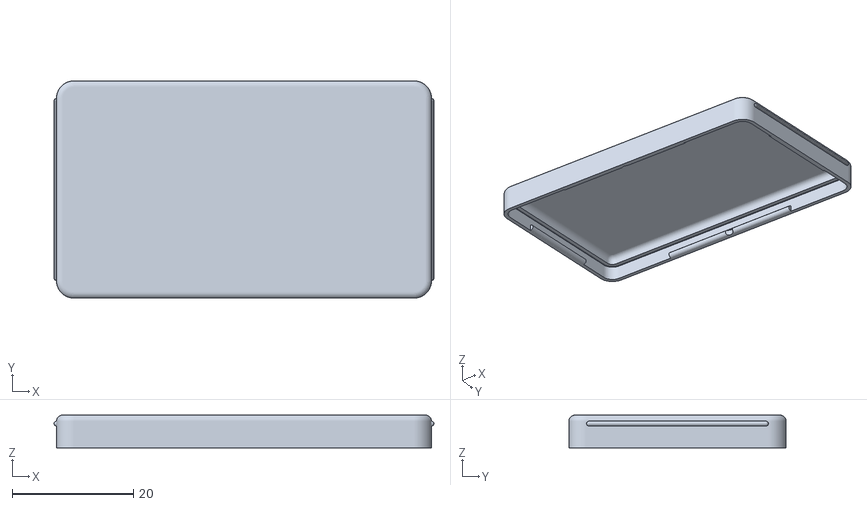
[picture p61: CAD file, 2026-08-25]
COVER/out/MiniNDP_Cover_THIN.stl
62.6 x 35.8 x 5.40

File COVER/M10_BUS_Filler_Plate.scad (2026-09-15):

/* Filler plate & connector guide for bus connector on Olivetti M-10
   https://github.com/bkw777/NODE_DATAPAC

   This has 2 purposes:
   * prevent off-by-one pin misalingment when installing MiniNDP
   * fill the opening to take the place of the open door

 */

plate_width = 61.2;              // 0.1
plate_depth = 30;                // 0.1
plate_thickness = 2;             // 0.1
pt = plate_thickness;

fitment_clearance = 0.2;         // 0.1
fc = fitment_clearance;

pw = plate_width - fc*2;
pd = plate_depth - fc*2;

wt = pt;  // wall thickness

bus_width = 51;                  // 0.1
bus_depth = 5.1;                 // 0.1
// long as possible without touching the motherboard pcb, float 1mm away from pcb
bus_height = 12;                 // 0.1
// distance bus connector edge to door hinge
bus_x = 3.8;                     // 0.1

// large as possible without allowing the connector to be off by one pin, slightly less than 1/2 of 2.54mm pin pitch
bus_fitment_clearance = 1.2;     // 0.1
bfc = bus_fitment_clearance;

bus_base_chamfer = 1.5;          // 0.1  // intentionally not dynamic, not based on wall thickness etc
bus_funnel = wt*0.8;

bw = bus_width + bfc*2;
bd = bus_depth + bfc*2;
bh = bus_height;
bch = wt + bus_base_chamfer;

bx = pw/2-bw/2-bus_x+bfc;


include_finger_pull = false;
finger_pull_width = 19;         // 0.1
finger_pull_x = 7;              // 0.1
finger_pull_angle = 30;
finger_pull_height = pt*0.75;   // 0.1

// adjust the X position of the 45 deg plane so it meets the vertical plane near the bottom edge corner of the top plate
inboard_retainer_x_adj = -(pt*0.2);  // 0.1

th = bh + pt; // total height

// arc smoothness - comment both out before importing into FreeCAD
$fs = 0.2;
$fa = 1;

e = 0.01; // epsilon

// ---------------------------------------------------------------

use <lib/handy.scad>;

module M10_bus_filler_plate () {

  difference() {
  
  // ADD
    group() {

      // the main plate is rounded on the outboard edge
      // to snap under the lip on that side of the opening

      // plate
      hull() {
        // main plate
        translate([0,0,pt/2])
          cube([pw,pd,pt],center=true);
        // outboard retainer
        translate([-pw/2,0,pt/2])
          rotate([90,0,0])
            cylinder(h=pd,d=pt,center=true);
      }
      
      // inboard retainer
      translate([inboard_retainer_x_adj,0,0]) // nudge the whole thing in so the angled wall intersects the vertical at the bottm edge
      hull() {
        translate([pw/2,0,-pt/2])
          rotate([90,0,0])
            cylinder(h=pd,d=pt,center=true);
        translate([pw/2-pt,0,pt/2])
          rotate([90,0,0])
            cylinder(h=pd,d=pt,center=true);
      }

      // tunnel
      translate([bx,0,0]) {
        translate([0,0,-bh/2+e])
        rcube([bw+wt*2,bd+wt*2,bh],rh=wt);

        // tunnel base chamfer
        difference() {
          // add chamfer
          translate([0,0,-bch/2+e])
            sqyl(w=bw+bch*2,d=bd+bch*2,h=bch,r1=0,r2=bch);
          // cut the edge off that pokes out the end
          translate([bch/2+1+pw/2-bx-e,0,0])
            cube([bch+2,bd+bch*2+2,bch+2],center=true);
       }
      }
     
    }

  // CUT
    group() {
      translate([bx,0,0]) {
        // tunnel
        translate([0,0,-th/2+pt])
          cube([bw,bd,th+2],center=true);

        // funnel
        translate([0,0,-bh-wt/2+bus_funnel])
          sqyl(w=bw+wt*2+e*2,d=bd+wt*2+e*2,h=wt,r1=wt+e,r2=0);
      }

      // finger pull
      if (include_finger_pull)
        translate([finger_pull_width/2-pw/2+finger_pull_x,-pd/2,finger_pull_height])
          rotate([90-finger_pull_angle,0,0])
            translate([0,-pt,-3])
              hull()
                mirror_copy([1,0,0])
                  translate([finger_pull_width/2,0,0])
                    cylinder(h=8,r=pt,center=true);
    }
  }
    
}

// reorient for printing
ry = $preview ? 0 : 180 ;
tz = $preview ? 0 : pt ;
translate([0,0,tz]) rotate([0,ry,0]) M10_bus_filler_plate();

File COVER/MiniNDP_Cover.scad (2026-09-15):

/* 3d-printable enclosure for MiniNDP - github.com/bkw777/NODE_DATAPAC */
// version: 003

// ------------------------------------------------------------------------------
// options

Customizer_Note = "";

PCB = "EZ1M"; // [EZ1M,EZ512,SL1M,T512,M10]
loose_fit = false; // set true if FDM print is too tight

DEBUG_X = false;
debug_cut_x = 0;
DEBUG_Y = false;
debug_cut_y = 0;

// ------------------------------------------------------------------------------

low_profile =  // true for CR2016 , false for CR2032
        PCB=="M10" ? true :
        PCB=="SL1M" ? true :
        PCB=="T512" ? true :
        false;

pcb_stl =
        PCB=="EZ512" ? "lib/pcb_EZ512.stl" :
        PCB=="M10" ? "lib/pcb_M10.stl" :
        PCB=="T512" ? "lib/pcb_T512.stl" :
        low_profile ? "lib/pcb_SL1M.stl" :
        "lib/pcb_EZ1M.stl";

// 0=auto
components_height = 0; // 0.1

ch = components_height ? components_height :
        low_profile ? 1.7 :
        4.1;

// PCB dimensions from KiCAD
pcb_thickness = 1.6;
pcb_corner_radius = 2;

pcblw = 
        PCB=="M10" ? [26,72] :
        [34,60];

pcb_length = pcblw[0];
pcb_width = pcblw[1];

// arc smoothness - comment both out before importing into FreeCAD
$fs = 0.2;
$fa = 1;

wall_thickness = 0.8;

// this is both the height of the wall above the pcb surface on the computer side,
// and the diameter of the cylinders that form the pcb retainer bumps
lip =
  PCB=="M10" ? 0.8 :
  1.2;

// width of pcb tray ledge
ledge = 0.8;

// -1 = auto (0.1)
fitment_clearance = -1 ; // 0.1
fc =
  fitment_clearance > -0.01 ? fitment_clearance :
//  PCB=="M10" ? 0.08 :
  loose_fit ? 0.2 :
  0.1;

o = 0.01; // overlap/overcut/overhang

// secondary/smaller fillet radius
sr = 1;   // 0.1

short_retainer_len = pcb_length/2;
long_retainer_len = pcb_width/2;

finger_pull_length = 10;
finger_pull_height = 0.4;

// ---------------------------------------------------------------

assert(lip<=wall_thickness*2);
assert(finger_pull_height<=wall_thickness+fc+ledge);

inner_width = fc + pcb_width + fc;
inner_length = fc + pcb_length + fc;
inner_height = pcb_thickness + ch + fc;
outer_width = wall_thickness + inner_width + wall_thickness;
outer_length = wall_thickness + inner_length + wall_thickness;
outer_height = inner_height + wall_thickness;
outer_corner = pcb_corner_radius + fc;

// 0 = auto
outer_secondary_radius = 0 ; // 0.1
osr =
  outer_secondary_radius>0.01 ? outer_secondary_radius :
  //PCB=="M10" ? sr+wall_thickness+ledge :
  sr;

use <lib/handy.scad>;

module pcb_model () {
  import(pcb_stl);
}

module main_shell() {
 difference() {
  // add the main outer surface
  rcube([outer_width,outer_length,outer_height*2],rh=pcb_corner_radius+fc+wall_thickness,rv=osr);

  union() {
   // cut outer shell in half to leave a (solid) bathtub
   translate([0,0,-outer_height/2-lip])
    cube([1+outer_width+1,1+outer_length+1,outer_height],center=true);

   // cut the main cavity
   rh = (pcb_corner_radius-ledge<sr) ? sr : pcb_corner_radius-ledge ;
   rcube([pcb_width-ledge*2,pcb_length-ledge*2,inner_height*2],rh=rh,rv=sr);

   // cut the pcb tray
   cz = inner_height + lip;
   translate([0,0,-cz/2+pcb_thickness+fc])
    rcube([inner_width,inner_length,cz],rh=pcb_corner_radius+fc,rv=fc);
  }
 }
 
 // add the top & bottom PCB grabbers
  mirror_copy([0,1,0])
   translate([0,inner_length/2,-lip/2])
    difference () {
     rotate([0,90,0])
       cylinder(h=long_retainer_len,d=lip,center=true);
     if(PCB!="M10") translate([0,-1,-0.5])
      cylinder(h=2,r=1,center=true);
    }

 // add the side grabbers
 mirror_copy([1,0,0])
  translate([inner_width/2,0,-lip/2])
   difference() {
    rotate([90,0,0])
     cylinder(h=short_retainer_len,d=lip,center=true);
   }

 // add finger pulls
 translate([0,0,outer_height-finger_pull_height-osr])
  mirror_copy([1,0,0])
   translate([outer_width/2,0,0])
    hull() {
     mirror_copy([0,1,0])
        translate([0,outer_length/2-pcb_corner_radius-fc-wall_thickness-finger_pull_height,0])
       sphere(finger_pull_height);
    }

}

module Cover () {
  difference() {
    dcw = outer_width+2;
    dcd = outer_length+2;
    dch = outer_height*2+2;
    main_shell();
    if ($preview) {
      if (DEBUG_X) translate([debug_cut_x,-dcd/2,-dch/2]) cube([dcw/2-debug_cut_x,dcd,dch]);
      if (DEBUG_Y) translate([-dcw/2,debug_cut_y,-dch/2]) cube([dcw,dcd/2-debug_cut_y,dch]);
    }
  }
}

%pcb_model();
Cover();

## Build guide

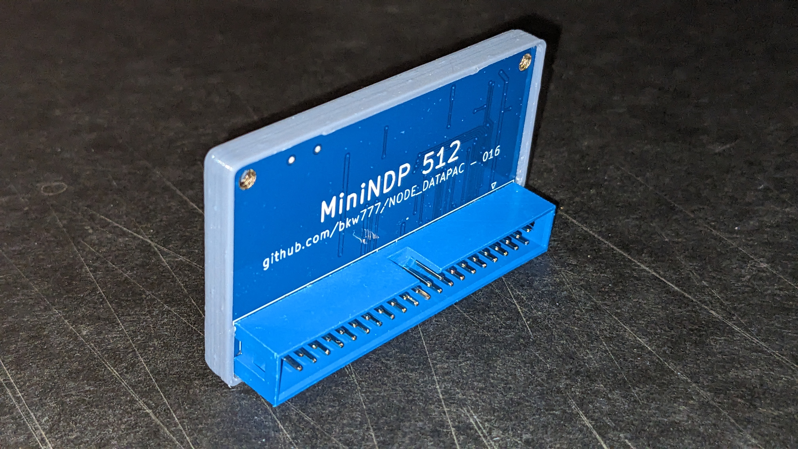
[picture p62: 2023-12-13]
ref/MiniNDP_and_cover.assembled.jpg

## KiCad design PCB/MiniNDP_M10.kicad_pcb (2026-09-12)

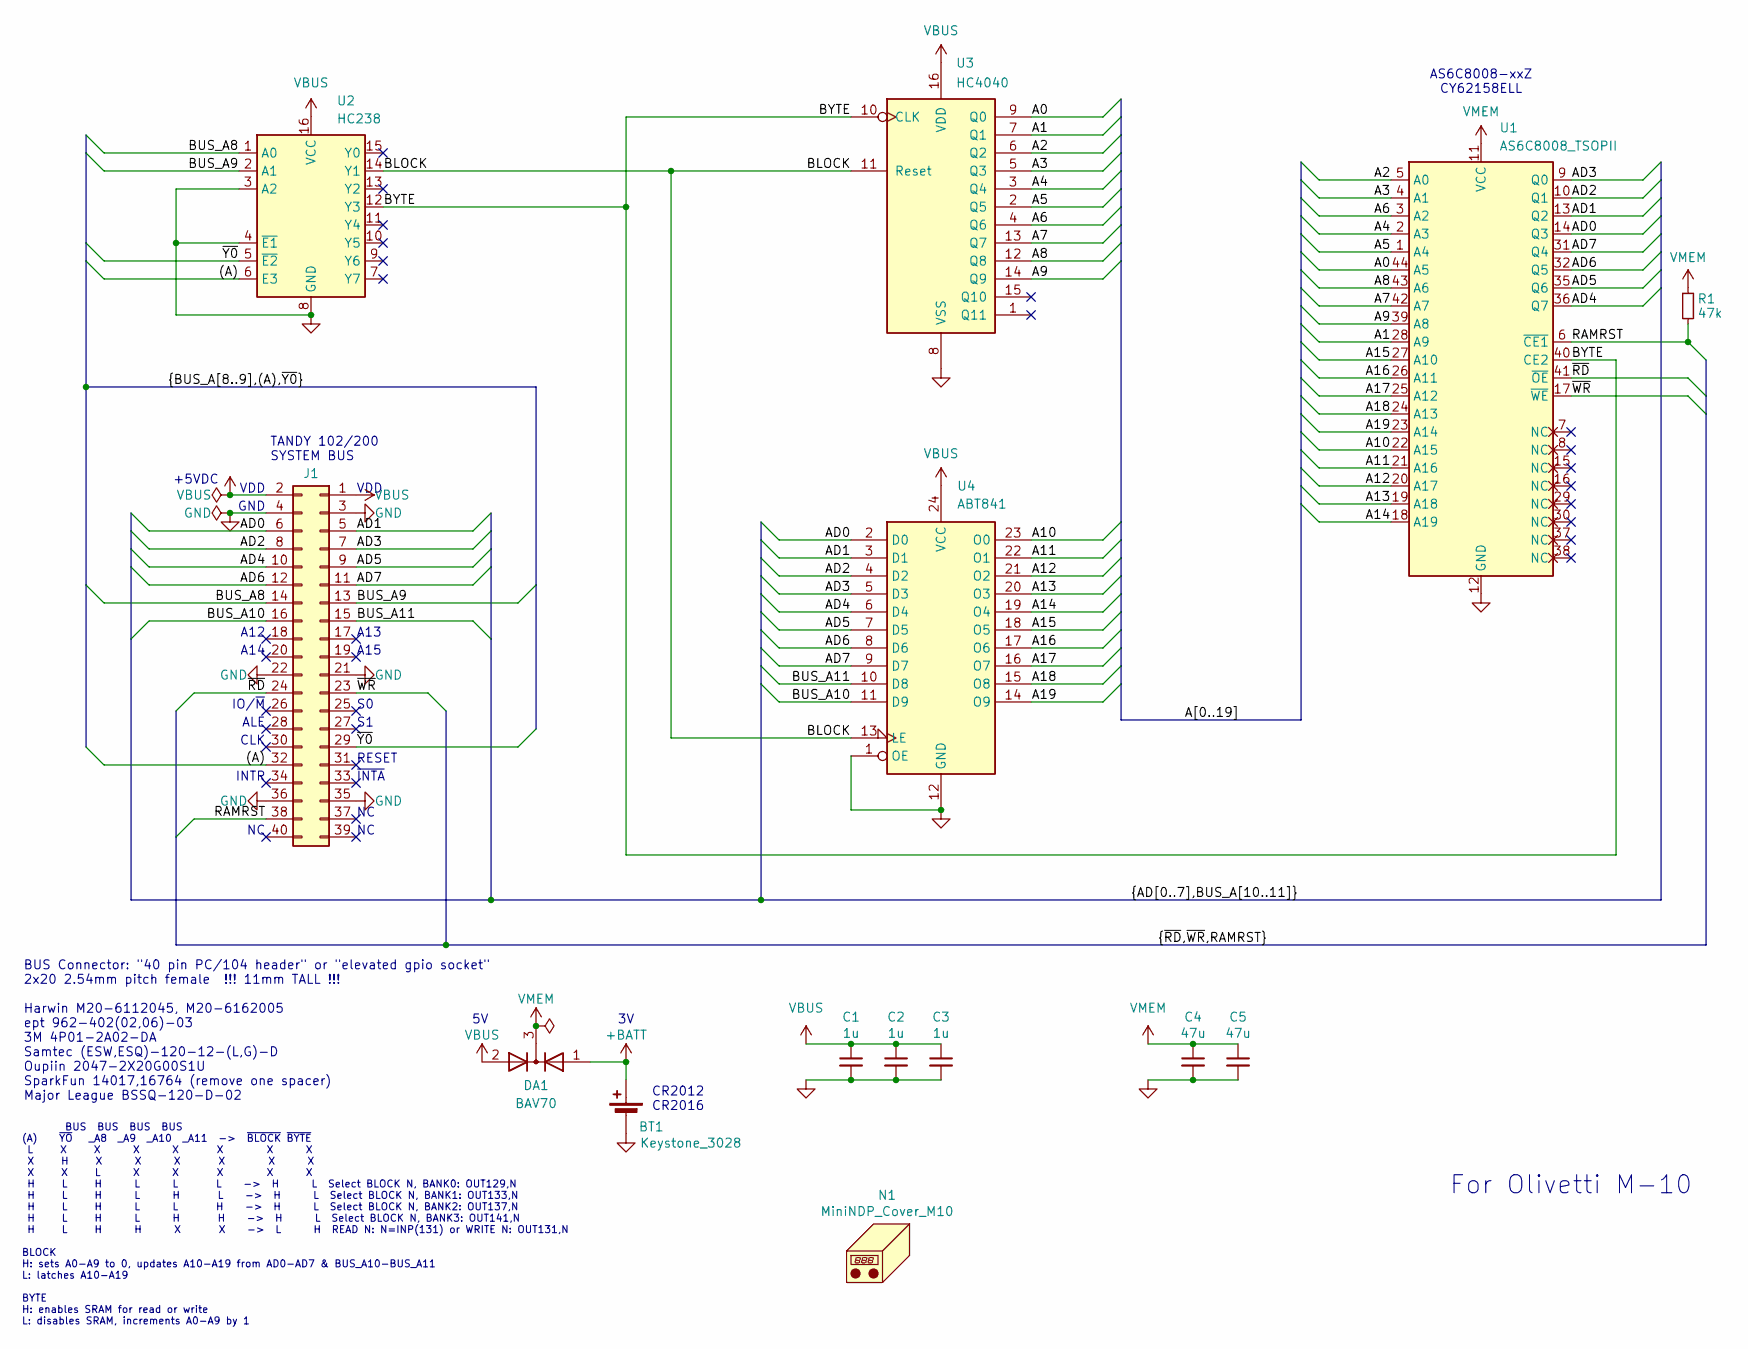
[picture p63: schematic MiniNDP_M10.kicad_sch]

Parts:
BT1: Keystone_3028; Keystone_3028_3034_bkw; MPN Keystone 3028
C1, C2, C3: 1u; C_0805; MPN CL21B105KAFNNNE
C4, C5: 47u; C_1206; MPN C3216X5R1E476M160DC
DA1: BAV70; SOT-23; MPN BAV70-7-F
J1: Conn_02x20_Odd_Even; PinSocket_2x20_P2.54mm_Vertical; MPN M20-6112045
N1: MiniNDP_Cover_M10; MPN MiniNDP_Cover_M10.stl
R1: 47k; R_0805; MPN RMCF0805FT47K0
U1: AS6C8008_TSOPII; TSOP-II-44; MPN AS6C8008-55ZIN
U2: HC238; TSSOP-16; MPN 74HC238PW,118
U3: HC4040; TSSOP-16; MPN 74HC4040PW,118
U4: ABT841; TSSOP-24; MPN SN74ABT841APW

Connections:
+BATT: BT1.1 (+), DA1.1 (A)
/(A): J1.32, U2.6 (E3)
/A0: U1.44 (A5), U3.9 (Q0)
/A1: U1.28 (A9), U3.7 (Q1)
/A2: U1.5 (A0), U3.6 (Q2)
/A3: U1.4 (A1), U3.5 (Q3)
/A4: U1.2 (A3), U3.3 (Q4)
/A5: U1.1 (A4), U3.2 (Q5)
/A6: U1.3 (A2), U3.4 (Q6)
/A7: U1.42 (A7), U3.13 (Q7)
/A8: U1.43 (A6), U3.12 (Q8)
/A9: U1.39 (A8), U3.14 (Q9)
/A10: U1.22 (A15), U4.23 (O0)
/A11: U1.21 (A16), U4.22 (O1)
/A12: U1.20 (A17), U4.21 (O2)
/A13: U1.19 (A18), U4.20 (O3)
/A14: U1.18 (A19), U4.19 (O4)
/A15: U1.27 (A10), U4.18 (O5)
/A16: U1.26 (A11), U4.17 (O6)
/A17: U1.25 (A12), U4.16 (O7)
/A18: U1.24 (A13), U4.15 (O8)
/A19: U1.23 (A14), U4.14 (O9)
/AD0: J1.6, U1.14 (Q3), U4.2 (D0)
/AD1: J1.5, U1.13 (Q2), U4.3 (D1)
/AD2: J1.8, U1.10 (Q1), U4.4 (D2)
/AD3: J1.7, U1.9 (Q0), U4.5 (D3)
/AD4: J1.10, U1.36 (Q7), U4.6 (D4)
/AD5: J1.9, U1.35 (Q6), U4.7 (D5)
/AD6: J1.12, U1.32 (Q5), U4.8 (D6)
/AD7: J1.11, U1.31 (Q4), U4.9 (D7)
/BLOCK: U2.14 (Y1), U3.11 (Reset), U4.13 (LE)
/BUS_A8: J1.14, U2.1 (A0)
/BUS_A9: J1.13, U2.2 (A1)
/BUS_A10: J1.16, U4.11 (D9)
/BUS_A11: J1.15, U4.10 (D8)
/BYTE: U1.40 (CE2), U2.12 (Y3), U3.10 (CLK)
/RAMRST: J1.38, R1.2, U1.6 (~CE1)
/~RD: J1.24, U1.41 (~OE)
/~WR: J1.23, U1.17 (~WE)
/~Y0: J1.29, U2.5 (~E2)
GND: BT1.2 (-), C1.2, C2.2, C3.2, C4.2, C5.2, J1.3, J1.4, J1.21, J1.22, J1.35, J1.36, U1.12 (GND), U1.34 (GND), U2.3 (A2), U2.4 (~E1), U2.8 (GND), U3.8 (VSS), U4.1 (OE), U4.12 (GND)
VBUS: C1.1, C2.1, C3.1, DA1.2 (A), J1.1, J1.2, U2.16 (VCC), U3.16 (VDD), U4.24 (VCC)
VMEM: C4.1, C5.1, DA1.3 (K), R1.1, U1.11 (VCC), U1.33 (VCC)

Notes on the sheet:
INTR
BUS BUS BUS BUS (A) ~{YO} _A8 _A9 _A10 _A11 -> ~{BLOCK} ~{BYTE} L X X X X X X X X H X X X X X X X X L X X X X X H L H L L L -> H L Select BLOCK N, BANK0: OUT129,N H L H L H L -> H L Select BLOCK N, BANK1: OUT133,N H L H L L H -> H L Select BLOCK N, BANK2: OUT137,N H L H L H H -> H L Select BLOCK N,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
VDD
A14
CLK
~{INTA}
A12
A15
ALE
For Olivetti M-10
A13
GND
IO/~{M}
RESET
AS6C8008-xxZ CY62158ELL
BUS Connector: "40 pin PC/104 header" or "elevated gpio socket" 2x20 2.54mm pitch female !!! 11mm TALL !!! Harwin M20-6112045, M20-6162005 ept 962-402(02,06)-03 3M 4P01-2A02-DA Samtec (ESW,ESQ)-120-12-(L,G)-D Oupiin 2047-2X20G00S1U SparkFun 14017,16764 (remove one spacer) Major League BSSQ-120-D-02
+5VDC
TANDY 102/200 SYSTEM BUS
CR2012 CR2016

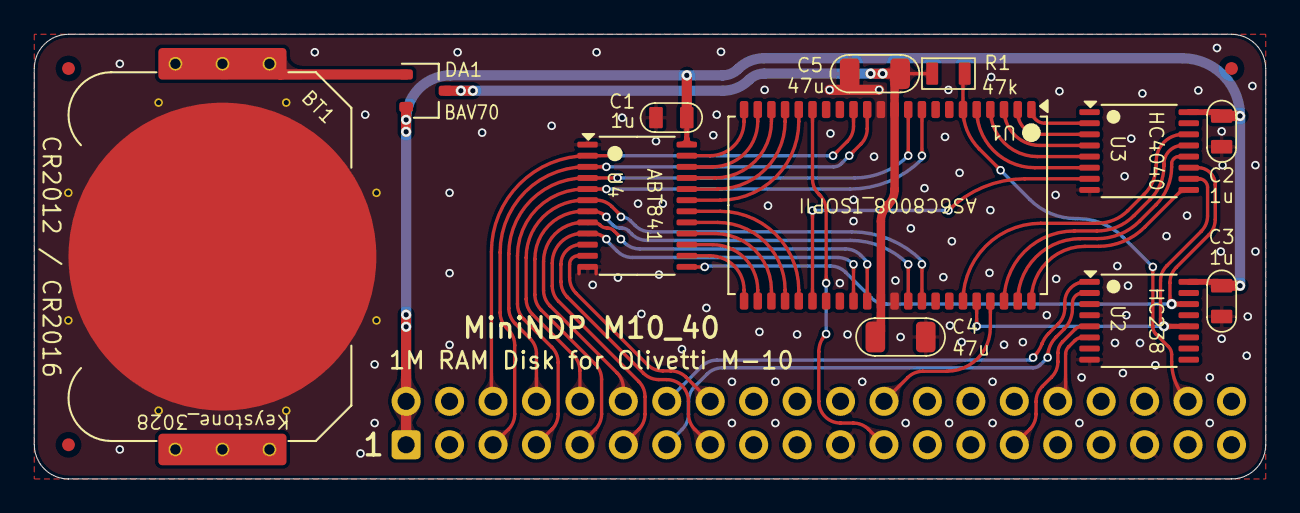
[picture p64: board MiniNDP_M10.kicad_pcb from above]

Board: 2 copper layers, 72.0 x 26.0 mm, 17 parts (1 on the bottom side), 43 nets.

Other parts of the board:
F3, F3#2, F3#3: Fiducial_0.75_1.5

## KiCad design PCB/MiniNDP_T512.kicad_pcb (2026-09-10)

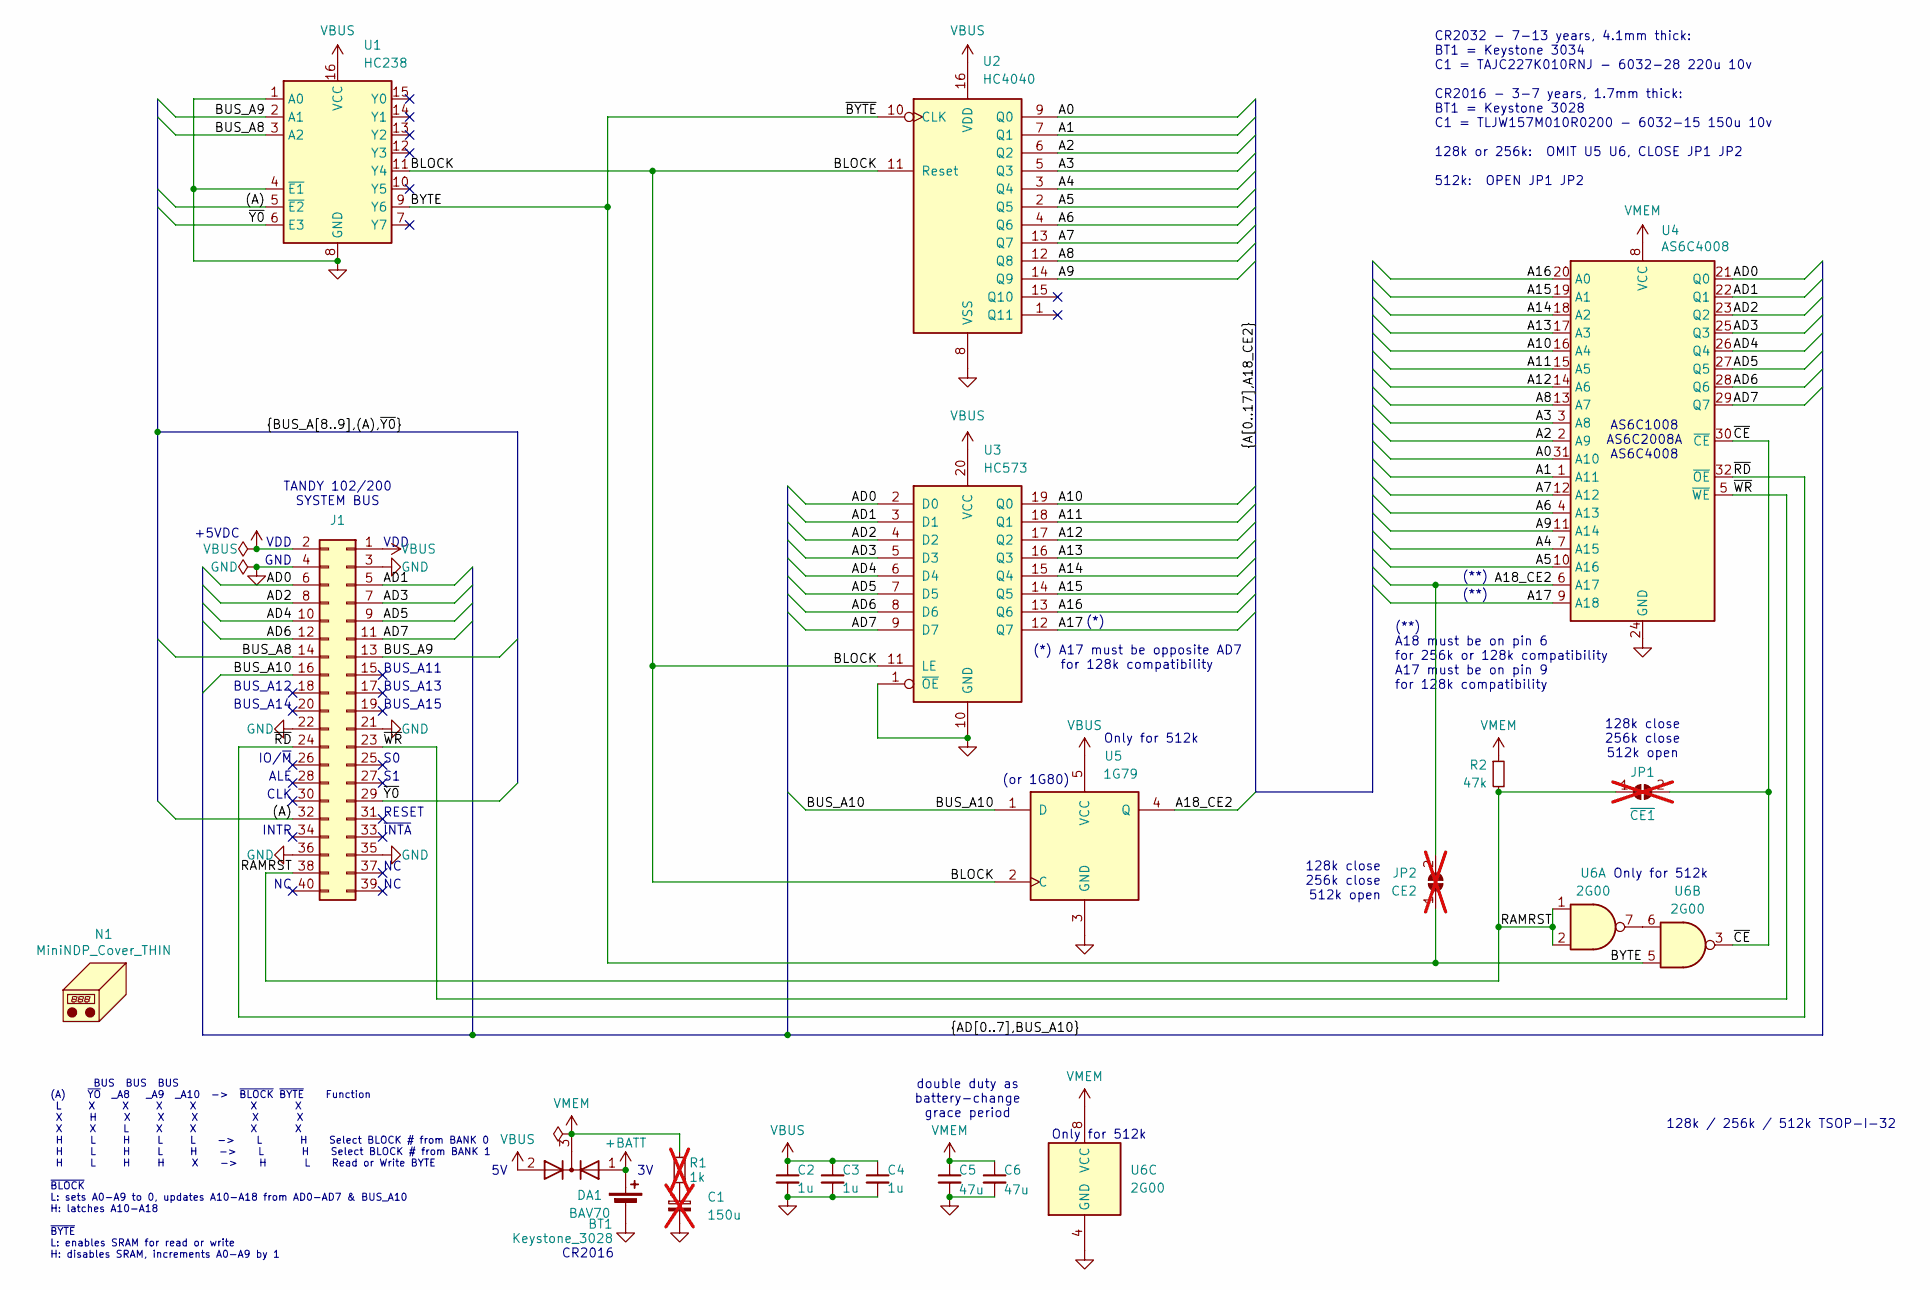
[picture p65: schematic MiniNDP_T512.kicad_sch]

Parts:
BT1: Keystone_3028; Keystone_3028_3034_bkw; MPN Keystone_3028
C1: 150u; CP_6032; MPN TLJW157M010R0200; not fitted
C2, C3, C4: 1u; C_0805; MPN CL21B105KAFNNNE
C5, C6: 47u; C_1206; MPN C3216X5R1E476M160DC
DA1: BAV70; SOT-23; MPN BAV70-7-F
J1: Conn_02x20_Odd_Even; IDC-Header_2x20_P2.54mm_Vertical; MPN 302-S401
JP1: ~{CE1}; SolderJumper-2_P1.3mm_Open_RoundedPad1.0x1.5mm; not fitted
JP2: CE2; SolderJumper-2_P1.3mm_Open_RoundedPad1.0x1.5mm; not fitted
N1: MiniNDP_Cover_THIN; MPN MiniNDP_Cover_THIN.stl
R1: 1k; R_0805; MPN RK73B2ATTD102J; not fitted
R2: 47k; R_0805; MPN RMCF0805FT47K0
U1: HC238; TSSOP-16; MPN 74HC238PW,118
U2: HC4040; TSSOP-16; MPN 74HC4040PW,118
U3: HC573; TSSOP-20; MPN 74HC573PW,118
U4: AS6C4008; TSOP32-dual; MPN AS6C4008-55STIN
U5: 1G79; SOT-353_SC-70-5; MPN 74LVC1G79GW,125
U6: 2G00; TSSOP-8_3x3mm_P0.65mm

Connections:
+BATT: BT1.1 (+), DA1.1 (A)
/(A): J1.32, U1.5 (~E2)
/A0: U2.9 (Q0), U4.31 (A10)
/A1: U2.7 (Q1), U4.1 (A11)
/A2: U2.6 (Q2), U4.2 (A9)
/A3: U2.5 (Q3), U4.3 (A8)
/A4: U2.3 (Q4), U4.7 (A15)
/A5: U2.2 (Q5), U4.10 (A16)
/A6: U2.4 (Q6), U4.4 (A13)
/A7: U2.13 (Q7), U4.12 (A12)
/A8: U2.12 (Q8), U4.13 (A7)
/A9: U2.14 (Q9), U4.11 (A14)
/A10: U3.19 (Q0), U4.16 (A4)
/A11: U3.18 (Q1), U4.15 (A5)
/A12: U3.17 (Q2), U4.14 (A6)
/A13: U3.16 (Q3), U4.17 (A3)
/A14: U3.15 (Q4), U4.18 (A2)
/A15: U3.14 (Q5), U4.19 (A1)
/A16: U3.13 (Q6), U4.20 (A0)
/A17: U3.12 (Q7), U4.9 (A18)
/A18_CE2: JP2.2 (B), U4.6 (A17), U5.4 (Q)
/AD0: J1.6, U3.2 (D0), U4.21 (Q0)
/AD1: J1.5, U3.3 (D1), U4.22 (Q1)
/AD2: J1.8, U3.4 (D2), U4.23 (Q2)
/AD3: J1.7, U3.5 (D3), U4.25 (Q3)
/AD4: J1.10, U3.6 (D4), U4.26 (Q4)
/AD5: J1.9, U3.7 (D5), U4.27 (Q5)
/AD6: J1.12, U3.8 (D6), U4.28 (Q6)
/AD7: J1.11, U3.9 (D7), U4.29 (Q7)
/BLOCK: U1.11 (Y4), U2.11 (Reset), U3.11 (LE), U5.2 (C)
/BUS_A8: J1.14, U1.3 (A2)
/BUS_A9: J1.13, U1.2 (A1)
/BUS_A10: J1.16, U5.1 (D)
/BYTE: JP2.1 (A), U1.9 (Y6), U2.10 (CLK), U6.5
/RAMRST: J1.38, JP1.1 (A), R2.2, U6.1, U6.2
/~CE: JP1.2 (B), U4.30 (~CE), U6.3
/~RD: J1.24, U4.32 (~OE)
/~WR: J1.23, U4.5 (~WE)
/~Y0: J1.29, U1.6 (E3)
GND: BT1.2 (-), C1.2, C2.2, C3.2, C4.2, C5.2, C6.2, J1.3, J1.4, J1.21, J1.22, J1.35, J1.36, U1.1 (A0), U1.4 (~E1), U1.8 (GND), U1.24, U2.8 (VSS), U3.1 (~OE), U3.10 (GND), U4.24 (GND), U5.3 (GND), U6.4 (GND)
unnamed: C1.1, R1.2
unnamed: U6.6, U6.7
VBUS: C2.1, C3.1, C4.1, DA1.2 (A), J1.1, J1.2, U1.16 (VCC), U2.16 (VDD), U3.20 (VCC), U5.5 (VCC)
VMEM: C5.1, C6.1, DA1.3 (K), R2.1, U4.8 (VCC), U6.8 (VCC)

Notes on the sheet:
TANDY 102/200 SYSTEM BUS
+5VDC
BUS_A15
INTR
BUS_A14
128k close 256k close 512k open
ALE
(**)
AS6C1008 AS6C2008A AS6C4008
~{INTA}
CLK
(**) A18 must be on pin 6 for 256k or 128k compatibility A17 must be on pin 9 for 128k compatibility
CR2032 - 7-13 years, 4.1mm thick: BT1 = Keystone 3034 C1 = TAJC227K010RNJ - 6032-28 220u 10v CR2016 - 3-7 years, 1.7mm thick: BT1 = Keystone 3028 C1 = TLJW157M010R0200 - 6032-15 150u 10v 128k or 256k: OMIT U5 U6, CLOSE JP1 JP2 512k: OPEN JP1 JP2
GND
IO/~{M}
Only for 512k
CR2016
(or 1G80)
VDD
128k / 256k / 512k TSOP-I-32
BUS BUS BUS (A) ~{YO} _A8 _A9 _A10 -> ~{BLOCK} ~{BYTE} Function L X X X X X X X H X X X X X X X L X X X X H L H L L -> L H Select BLOCK # from BANK 0 H L H L H -> L H Select BLOCK # from BANK 1 H L H H X -> H L Read or Write BYTE ~{BLOCK} L: sets A0-A9 to 0, updates A10-A18 from AD0-AD7 & BUS_A10 H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
RESET
(*) A17 must be opposite AD7 for 128k compatibility
BUS_A11
BUS_A13
double duty as battery-change grace period
(*)
BUS_A12

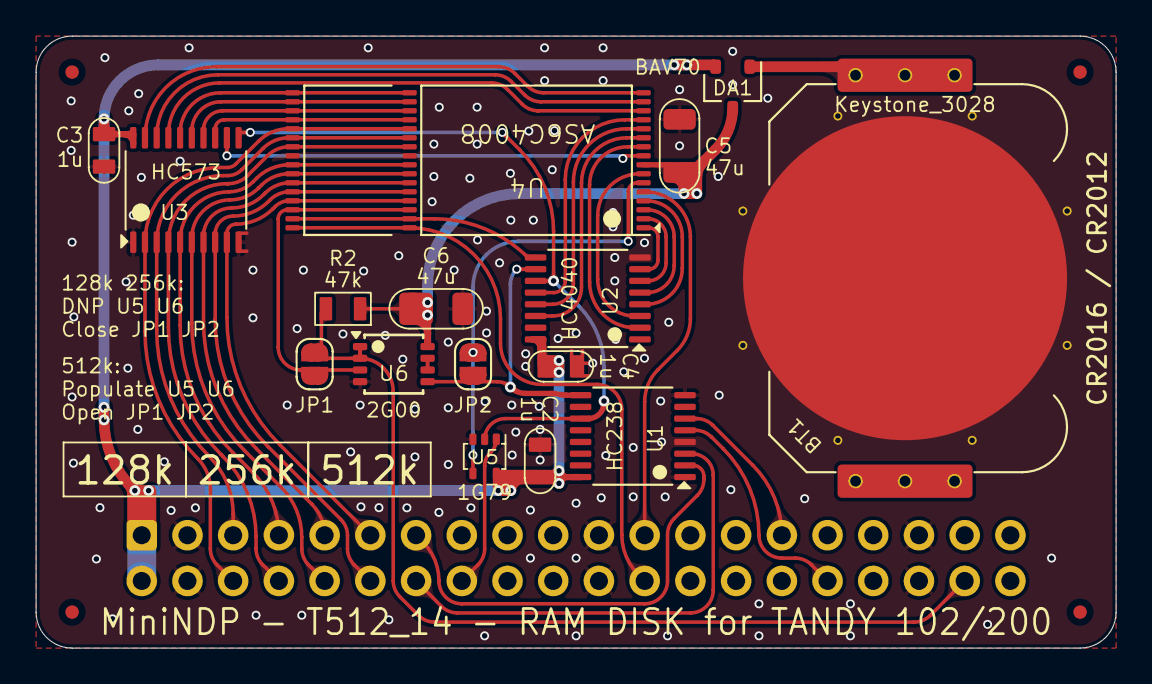
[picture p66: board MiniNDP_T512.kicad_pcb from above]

Board: 2 copper layers, 60.0 x 34.0 mm, 22 parts (1 on the bottom side), 43 nets.

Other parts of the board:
F3, F3#2, F3#3, F3#4: Fiducial_0.75_1.5

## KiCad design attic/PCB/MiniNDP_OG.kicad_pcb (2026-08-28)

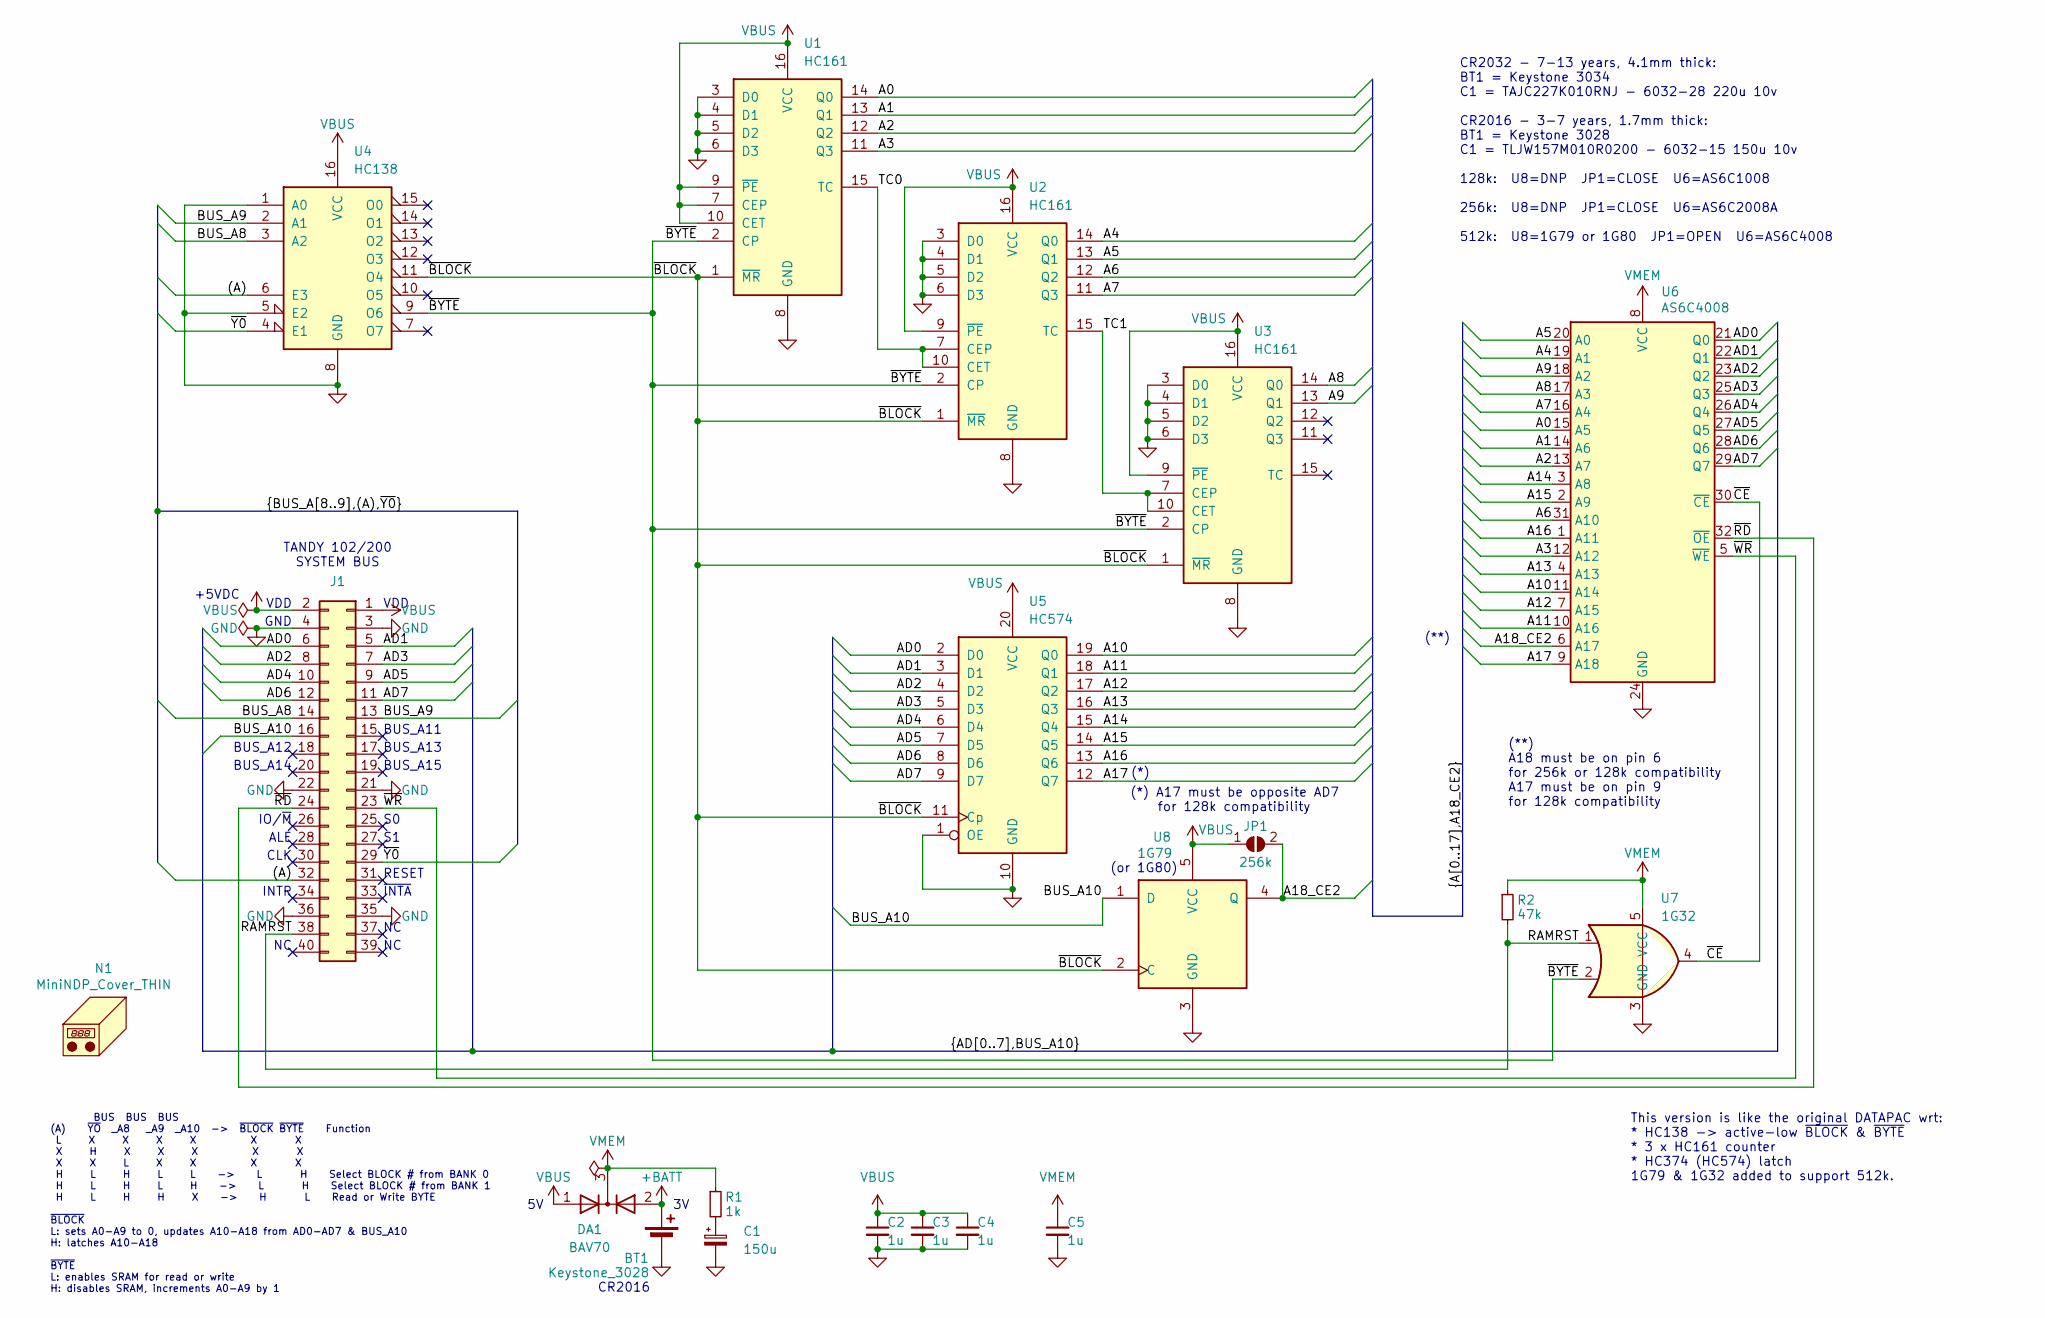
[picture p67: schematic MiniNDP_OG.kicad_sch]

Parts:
BT1: Keystone_3028; Keystone_3028_3034_bkw; MPN Keystone_3028
C1: 150u; CP_6032; MPN TLJW157M010R0200
C2, C3, C4, C5: 1u; C_0805; MPN CL21B105KAFNNNE
DA1: BAV70; SOT-23; MPN BAV70-7-F
J1: Conn_02x20_Odd_Even; IDC-Header_2x20_P2.54mm_Vertical; MPN 302-S401
JP1: 256k; SolderJumper-2_Open 0.65mm
N1: MiniNDP_Cover_THIN; MPN MiniNDP_Cover_THIN.stl
R1: 1k; R_0805; MPN RK73B2ATTD102J
R2: 47k; R_0805; MPN RMCF0805FT47K0
U1, U2, U3: HC161; TSSOP-16; MPN 74HC161PW,118
U4: HC138; TSSOP-16; MPN 74HC138PW,118
U5: HC574; TSSOP-20; MPN 74HC574PW,118
U6: AS6C4008; TSOP32-dual; MPN AS6C4008-55STIN
U7: 1G32; SOT-353_SC-70-5; MPN 74LVC1G32GW,125
U8: 1G79; SOT-353_SC-70-5; MPN 74LVC1G79GW,125

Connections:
+BATT: BT1.1 (+), DA1.2 (A)
/(A): J1.32, U4.6 (E3)
/A0: U1.14 (Q0), U6.15 (A5)
/A1: U1.13 (Q1), U6.14 (A6)
/A2: U1.12 (Q2), U6.13 (A7)
/A3: U1.11 (Q3), U6.12 (A12)
/A4: U2.14 (Q0), U6.19 (A1)
/A5: U2.13 (Q1), U6.20 (A0)
/A6: U2.12 (Q2), U6.31 (A10)
/A7: U2.11 (Q3), U6.16 (A4)
/A8: U3.14 (Q0), U6.17 (A3)
/A9: U3.13 (Q1), U6.18 (A2)
/A10: U5.19 (Q0), U6.11 (A14)
/A11: U5.18 (Q1), U6.10 (A16)
/A12: U5.17 (Q2), U6.7 (A15)
/A13: U5.16 (Q3), U6.4 (A13)
/A14: U5.15 (Q4), U6.3 (A8)
/A15: U5.14 (Q5), U6.2 (A9)
/A16: U5.13 (Q6), U6.1 (A11)
/A17: U5.12 (Q7), U6.9 (A18)
/A18_CE2: JP1.2 (B), U6.6 (A17), U8.4 (Q)
/AD0: J1.6, U5.2 (D0), U6.21 (Q0)
/AD1: J1.5, U5.3 (D1), U6.22 (Q1)
/AD2: J1.8, U5.4 (D2), U6.23 (Q2)
/AD3: J1.7, U5.5 (D3), U6.25 (Q3)
/AD4: J1.10, U5.6 (D4), U6.26 (Q4)
/AD5: J1.9, U5.7 (D5), U6.27 (Q5)
/AD6: J1.12, U5.8 (D6), U6.28 (Q6)
/AD7: J1.11, U5.9 (D7), U6.29 (Q7)
/BUS_A8: J1.14, U4.3 (A2)
/BUS_A9: J1.13, U4.2 (A1)
/BUS_A10: J1.16, U8.1 (D)
/RAMRST: J1.38, R2.2, U7.1
/TC0: U1.15 (TC), U2.7 (CEP), U2.10 (CET)
/TC1: U2.15 (TC), U3.7 (CEP), U3.10 (CET)
/~BLOCK: U1.1 (~MR), U2.1 (~MR), U3.1 (~MR), U4.11 (O4), U5.11 (Cp), U8.2 (C)
/~BYTE: U1.2 (CP), U2.2 (CP), U3.2 (CP), U4.9 (O6), U7.2
/~CE: U6.30 (~CE), U7.4
/~RD: J1.24, U6.32 (~OE)
/~WR: J1.23, U6.5 (~WE)
/~Y0: J1.29, U4.4 (E1)
GND: BT1.2 (-), C1.2, C2.2, C3.2, C4.2, C5.2, J1.3, J1.4, J1.21, J1.22, J1.35, J1.36, U1.3 (D0), U1.4 (D1), U1.5 (D2), U1.6 (D3), U1.8 (GND), U2.3 (D0), U2.4 (D1), U2.5 (D2), U2.6 (D3), U2.8 (GND), U3.3 (D0), U3.4 (D1), U3.5 (D2), U3.6 (D3), U3.8 (GND), U4.1 (A0), U4.5 (E2), U4.8 (GND), U5.1 (OE), U5.10 (GND), U6.24 (GND), U7.3 (GND), U8.3 (GND)
unnamed: C1.1, R1.2
VBUS: C2.1, C3.1, C4.1, DA1.1 (A), J1.1, J1.2, JP1.1 (A), U1.7 (CEP), U1.9 (~PE), U1.10 (CET), U1.16 (VCC), U2.9 (~PE), U2.16 (VCC), U3.9 (~PE), U3.16 (VCC), U4.16 (VCC), U5.20 (VCC), U8.5 (VCC)
VMEM: C5.1, DA1.3 (K), R1.1, R2.1, U6.8 (VCC), U7.5 (VCC)

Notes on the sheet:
TANDY 102/200 SYSTEM BUS
+5VDC
BUS_A15
INTR
BUS_A14
ALE
~{INTA}
CLK
(**) A18 must be on pin 6 for 256k or 128k compatibility A17 must be on pin 9 for 128k compatibility
CR2032 - 7-13 years, 4.1mm thick: BT1 = Keystone 3034 C1 = TAJC227K010RNJ - 6032-28 220u 10v CR2016 - 3-7 years, 1.7mm thick: BT1 = Keystone 3028 C1 = TLJW157M010R0200 - 6032-15 150u 10v 128k: U8=DNP JP1=CLOSE U6=AS6C1008 256k: U8=DNP JP1=CLOSE U6=AS6C2008A 512k: U8=1G79 or 1G80 JP1=OPEN U6=AS6C4008
GND
IO/~{M}
CR2016
(or 1G80)
VDD
BUS BUS BUS (A) ~{YO} _A8 _A9 _A10 -> ~{BLOCK} ~{BYTE} Function L X X X X X X X H X X X X X X X L X X X X H L H L L -> L H Select BLOCK # from BANK 0 H L H L H -> L H Select BLOCK # from BANK 1 H L H H X -> H L Read or Write BYTE ~{BLOCK} L: sets A0-A9 to 0, updates A10-A18 from AD0-AD7 & BUS_A10 H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
RESET
(*) A17 must be opposite AD7 for 128k compatibility
This version is like the original DATAPAC wrt: * HC138 -> active-low ~{BLOCK} & ~{BYTE} * 3 x HC161 counter * HC374 (HC574) latch 1G79 & 1G32 added to support 512k.
(**)
BUS_A11
BUS_A13
(*)
BUS_A12

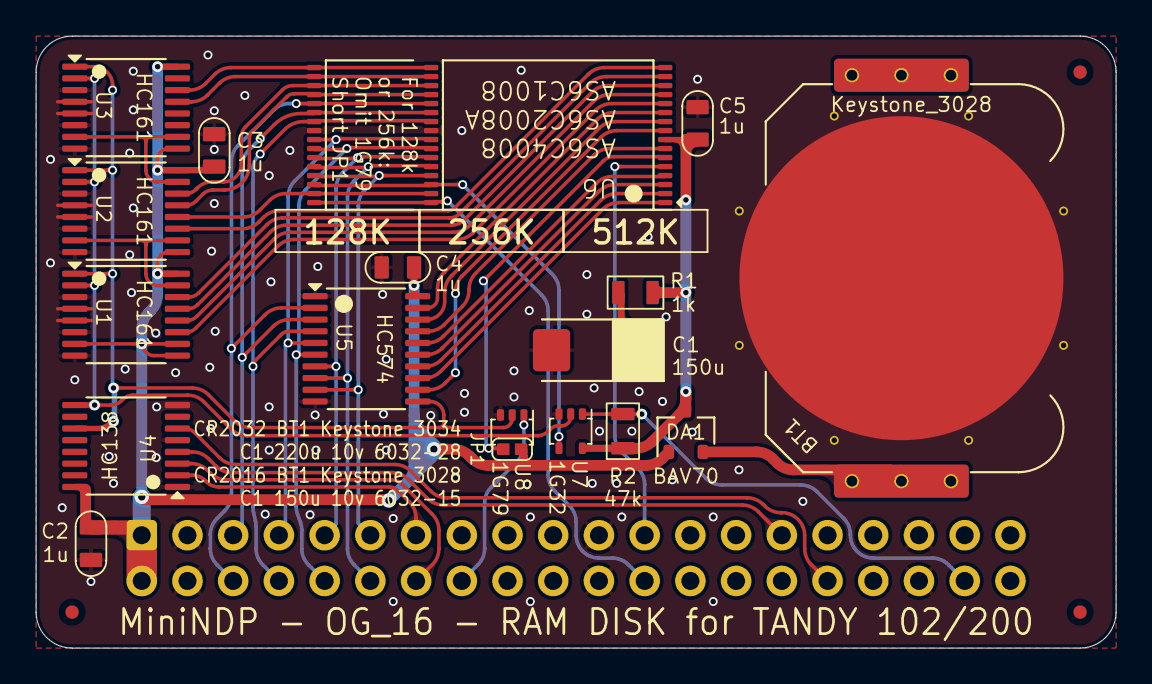
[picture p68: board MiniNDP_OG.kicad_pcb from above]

Board: 2 copper layers, 60.0 x 34.0 mm, 23 parts (1 on the bottom side), 45 nets.

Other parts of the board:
F3, F3#2, F3#3: Fiducial_0.75_1.5

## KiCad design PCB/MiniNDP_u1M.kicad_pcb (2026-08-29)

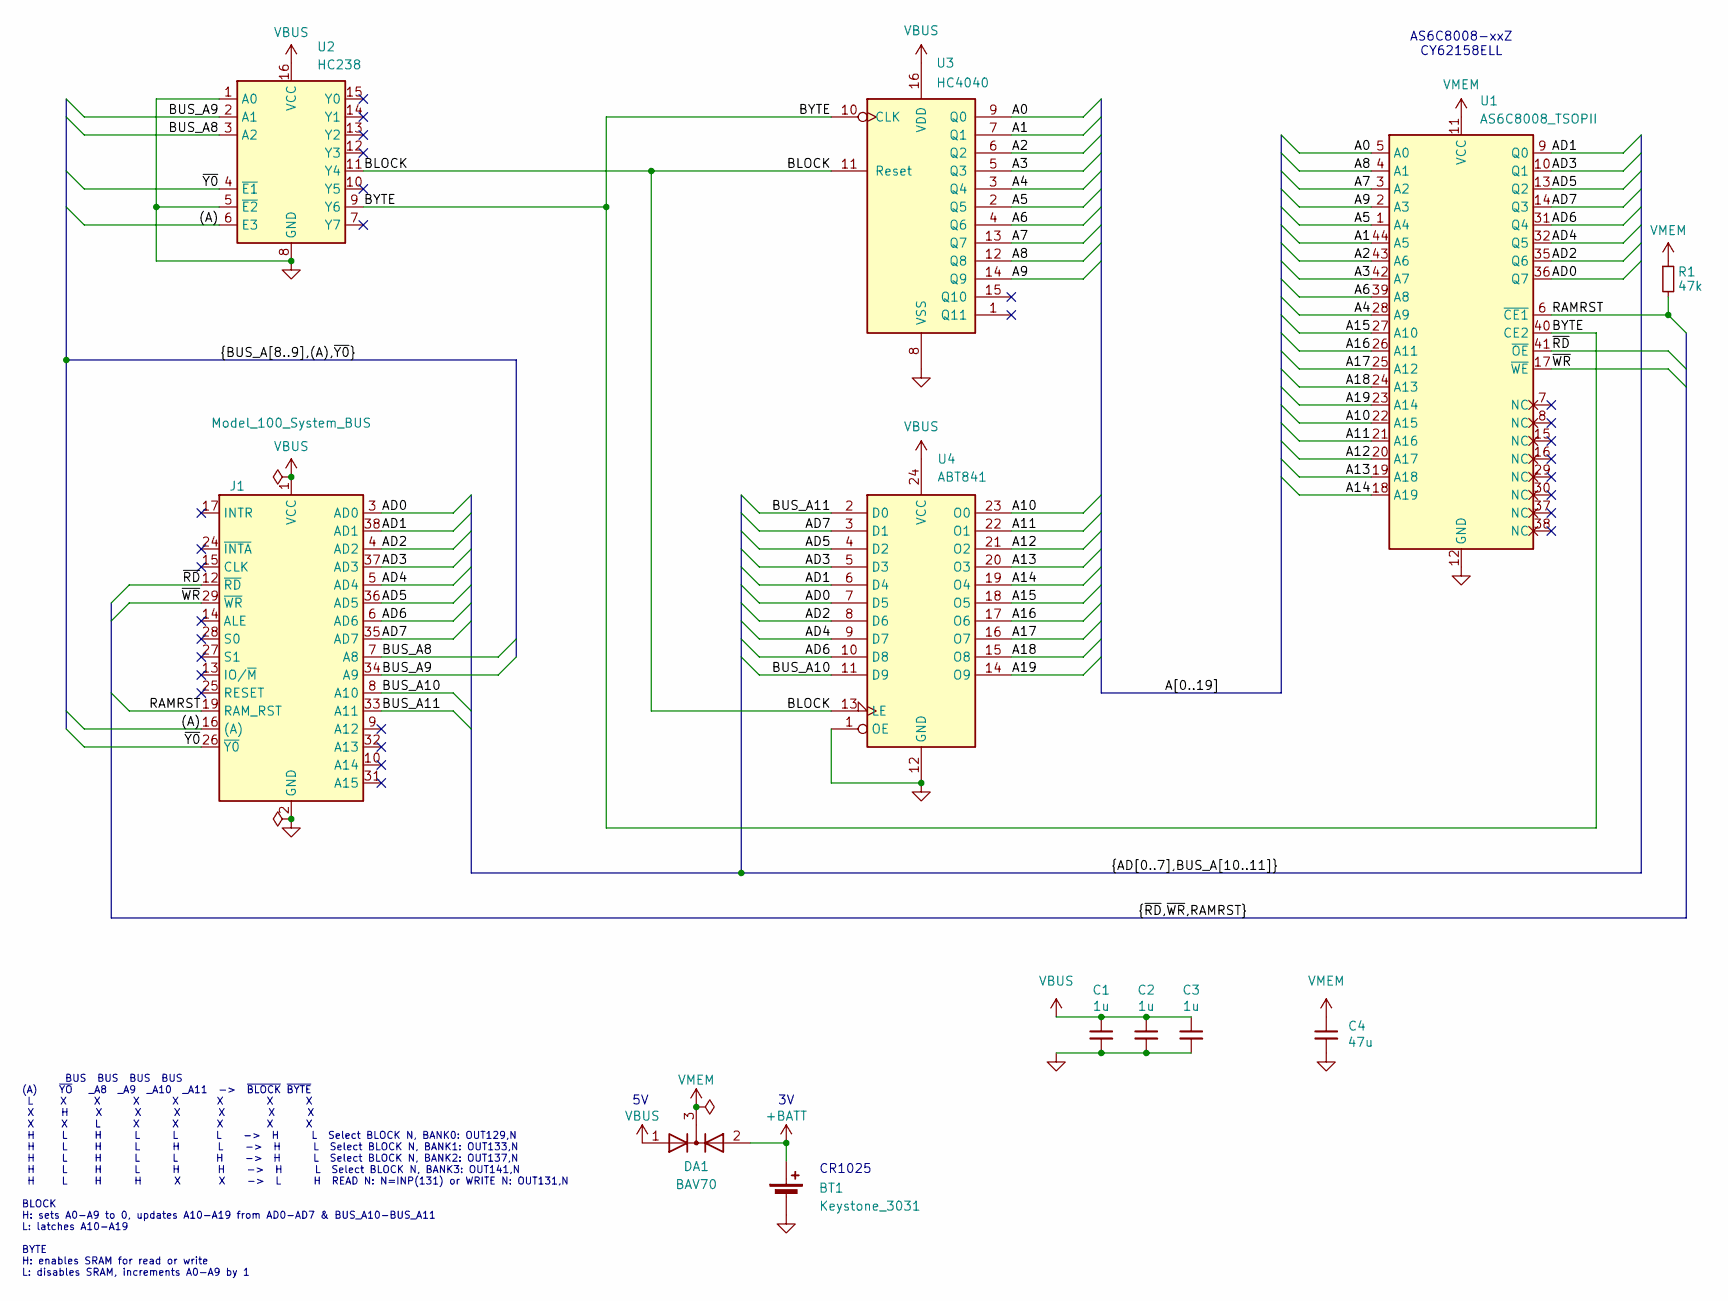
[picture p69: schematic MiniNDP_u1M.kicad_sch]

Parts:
BT1: Keystone_3031; MPN Keystone 3031
C1, C2, C3: 1u; C_0805; MPN CL21B105KAFNNNE
C4: 47u; C_1206; MPN C3216X5R1E476M160DC
DA1: BAV70; SOT-23; MPN BAV70-7-F
J1: Model_100_System_BUS; DIP-40_PCB; MPN 920-0172-01
R1: 47k; R_0805; MPN RMCF0805FT47K0
U1: AS6C8008_TSOPII; TSOP-II-44; MPN AS6C8008-55ZIN
U2: HC238; TSSOP-16; MPN 74HC238PW,118
U3: HC4040; TSSOP-16; MPN 74HC4040PW,118
U4: ABT841; TSSOP-24; MPN SN74ABT841APW

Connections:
+BATT: BT1.1 (+), DA1.2 (A)
/(A): J1.16 ((A)), U2.6 (E3)
/A0: U1.5 (A0), U3.9 (Q0)
/A1: U1.44 (A5), U3.7 (Q1)
/A2: U1.43 (A6), U3.6 (Q2)
/A3: U1.42 (A7), U3.5 (Q3)
/A4: U1.28 (A9), U3.3 (Q4)
/A5: U1.1 (A4), U3.2 (Q5)
/A6: U1.39 (A8), U3.4 (Q6)
/A7: U1.3 (A2), U3.13 (Q7)
/A8: U1.4 (A1), U3.12 (Q8)
/A9: U1.2 (A3), U3.14 (Q9)
/A10: U1.22 (A15), U4.23 (O0)
/A11: U1.21 (A16), U4.22 (O1)
/A12: U1.20 (A17), U4.21 (O2)
/A13: U1.19 (A18), U4.20 (O3)
/A14: U1.18 (A19), U4.19 (O4)
/A15: U1.27 (A10), U4.18 (O5)
/A16: U1.26 (A11), U4.17 (O6)
/A17: U1.25 (A12), U4.16 (O7)
/A18: U1.24 (A13), U4.15 (O8)
/A19: U1.23 (A14), U4.14 (O9)
/AD0: J1.3 (AD0), U1.36 (Q7), U4.7 (D5)
/AD1: J1.38 (AD1), U1.9 (Q0), U4.6 (D4)
/AD2: J1.4 (AD2), U1.35 (Q6), U4.8 (D6)
/AD3: J1.37 (AD3), U1.10 (Q1), U4.5 (D3)
/AD4: J1.5 (AD4), U1.32 (Q5), U4.9 (D7)
/AD5: J1.36 (AD5), U1.13 (Q2), U4.4 (D2)
/AD6: J1.6 (AD6), U1.31 (Q4), U4.10 (D8)
/AD7: J1.35 (AD7), U1.14 (Q3), U4.3 (D1)
/BLOCK: U2.11 (Y4), U3.11 (Reset), U4.13 (LE)
/BUS_A8: J1.7 (A8), U2.3 (A2)
/BUS_A9: J1.34 (A9), U2.2 (A1)
/BUS_A10: J1.8 (A10), U4.11 (D9)
/BUS_A11: J1.33 (A11), U4.2 (D0)
/BYTE: U1.40 (CE2), U2.9 (Y6), U3.10 (CLK)
/RAMRST: J1.19 (RAM_RST), R1.2, U1.6 (~CE1)
/~RD: J1.12 (~RD), U1.41 (~OE)
/~WR: J1.29 (~WR), U1.17 (~WE)
/~Y0: J1.26 (~Y0), U2.4 (~E1)
GND: BT1.2 (-), C1.2, C2.2, C3.2, C4.2, J1.2 (GND), J1.11 (GND), J1.18 (GND), J1.23 (GND), J1.30 (GND), J1.39 (GND), U1.12 (GND), U1.34 (GND), U2.1 (A0), U2.5 (~E2), U2.8 (GND), U3.8 (VSS), U4.1 (OE), U4.12 (GND)
VBUS: C1.1, C2.1, C3.1, DA1.1 (A), J1.1 (VCC), J1.40 (VCC), U2.16 (VCC), U3.16 (VDD), U4.24 (VCC)
VMEM: C4.1, DA1.3 (K), R1.1, U1.11 (VCC), U1.33 (VCC)

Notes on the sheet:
AS6C8008-xxZ CY62158ELL
BUS BUS BUS BUS (A) ~{YO} _A8 _A9 _A10 _A11 -> ~{BLOCK} ~{BYTE} L X X X X X X X X H X X X X X X X X L X X X X X H L H L L L -> H L Select BLOCK N, BANK0: OUT129,N H L H L H L -> H L Select BLOCK N, BANK1: OUT133,N H L H L L H -> H L Select BLOCK N, BANK2: OUT137,N H L H L H H -> H L Select BLOCK N,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
CR1025

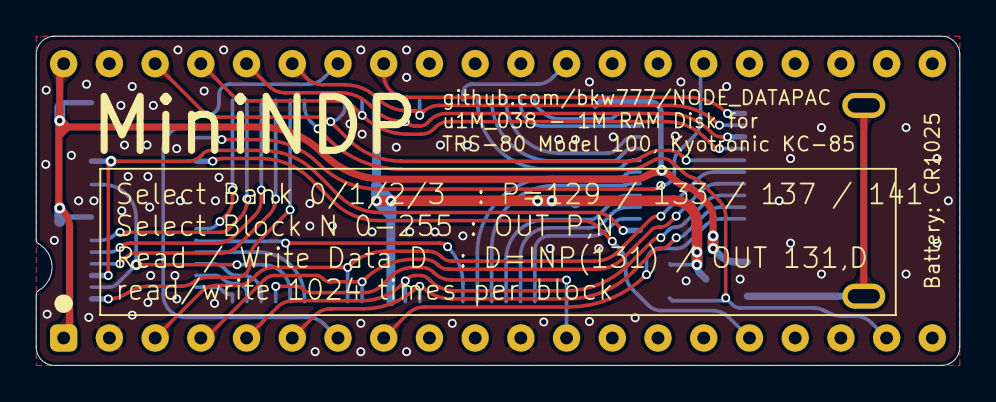
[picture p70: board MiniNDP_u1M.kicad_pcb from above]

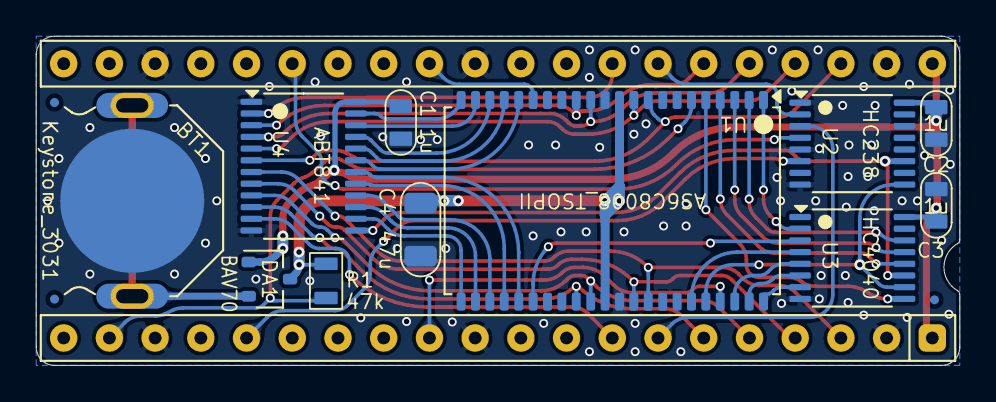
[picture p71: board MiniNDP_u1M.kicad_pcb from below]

Board: 2 copper layers, 51.3 x 18.3 mm, 15 parts (15 on the bottom side), 43 nets.

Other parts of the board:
F1, F2, F3: Fiducial_0.5_1.0

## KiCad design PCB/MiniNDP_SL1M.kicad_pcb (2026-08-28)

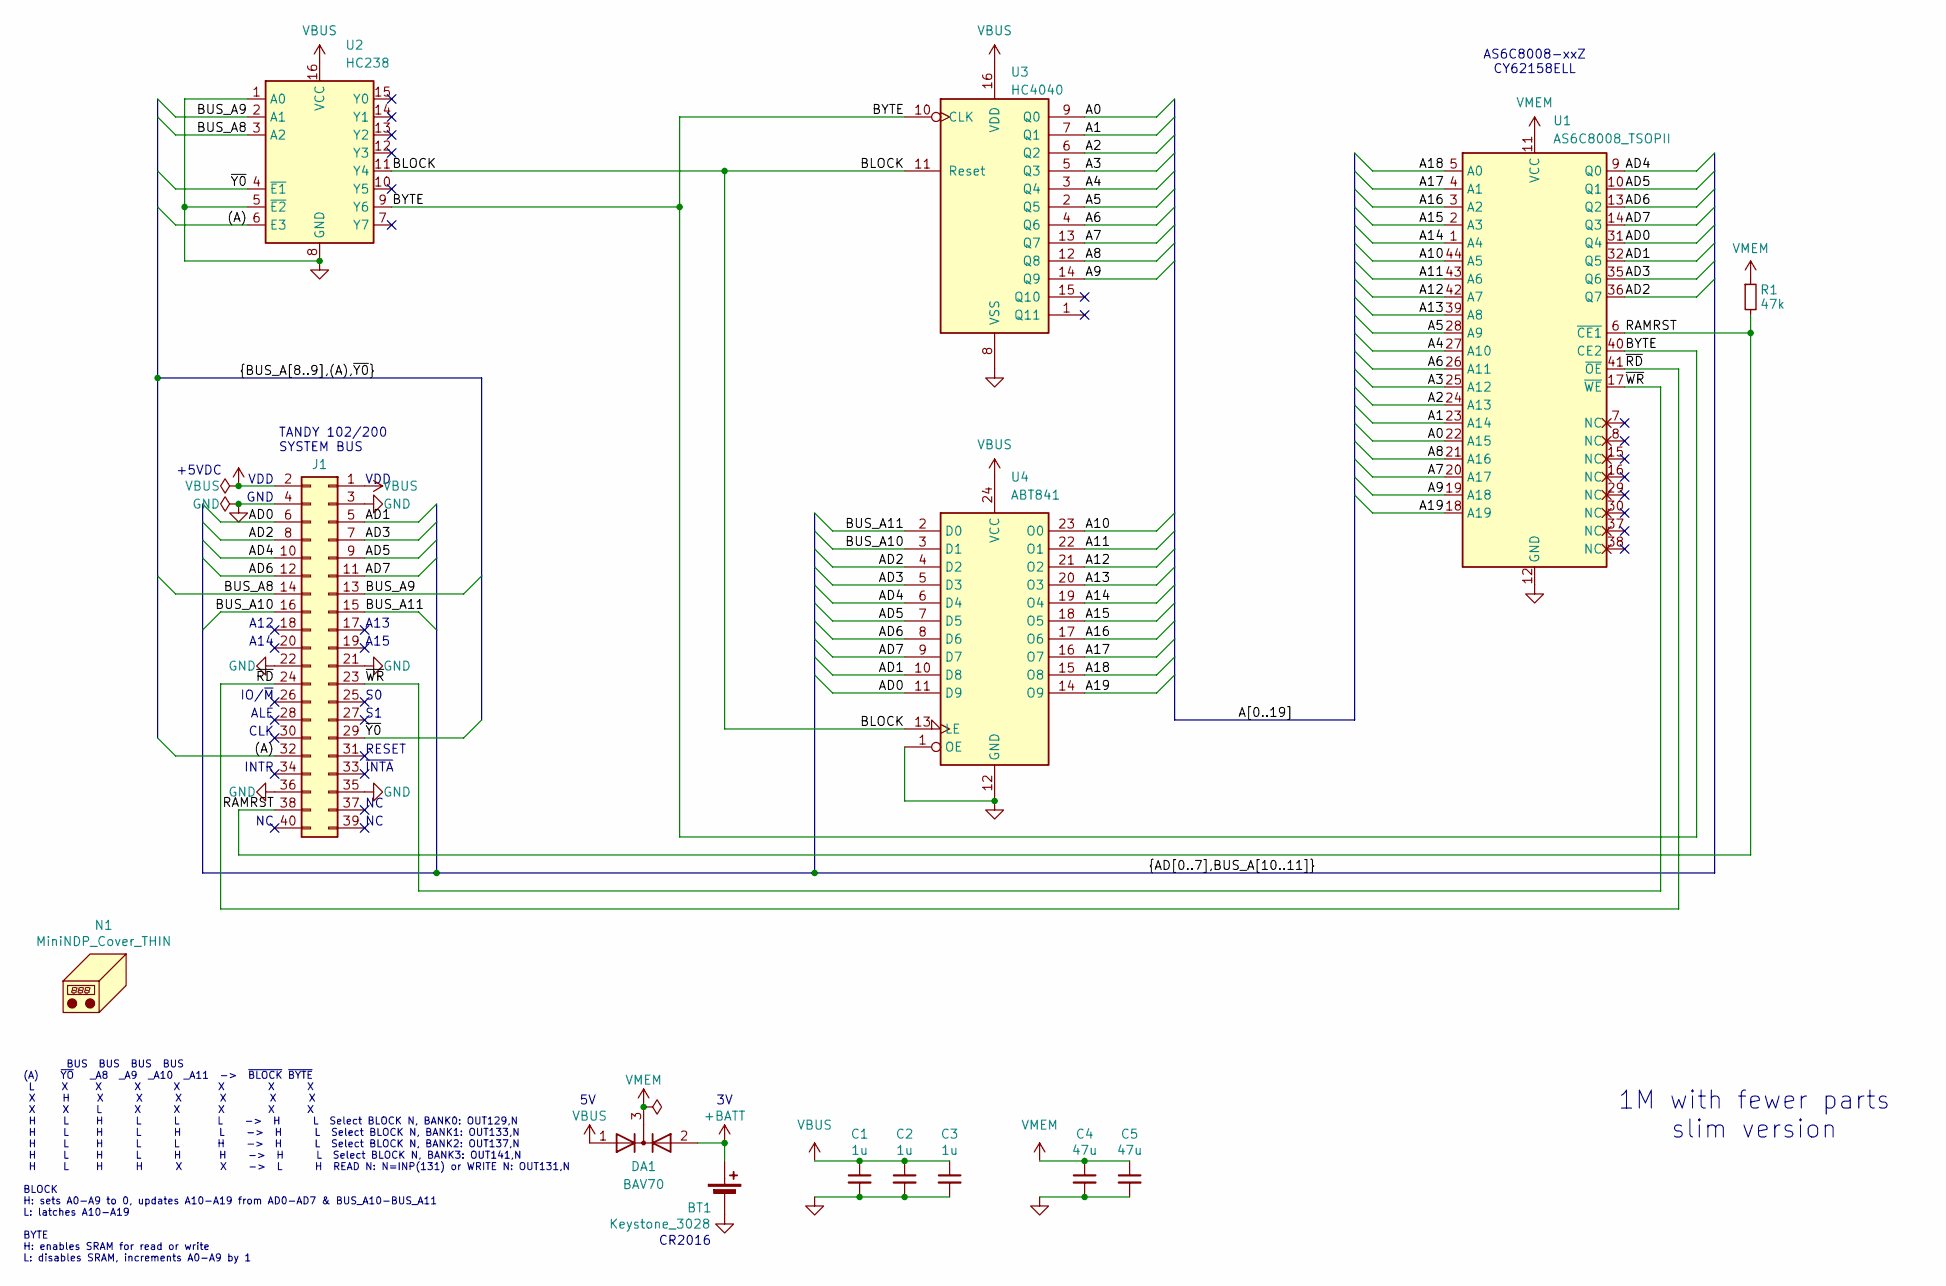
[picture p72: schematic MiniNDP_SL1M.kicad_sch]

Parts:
BT1: Keystone_3028; Keystone_3028_3034_bkw; MPN Keystone 3028
C1, C2, C3: 1u; C_0805; MPN CL21B105KAFNNNE
C4, C5: 47u; C_1206; MPN C3216X5R1E476M160DC
DA1: BAV70; SOT-23; MPN BAV70-7-F
J1: Conn_02x20_Odd_Even; IDC-Header_2x20_P2.54mm_Vertical; MPN 302-S401
N1: MiniNDP_Cover_THIN; MPN MiniNDP_Cover.stl
R1: 47k; R_0805; MPN RMCF0805FT47K0
U1: AS6C8008_TSOPII; TSOP-II-44; MPN AS6C8008-55ZIN
U2: HC238; TSSOP-16; MPN 74HC238PW,118
U3: HC4040; TSSOP-16; MPN 74HC4040PW,118
U4: ABT841; TSSOP-24; MPN SN74ABT841APW

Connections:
+BATT: BT1.1 (+), DA1.2 (A)
/(A): J1.32, U2.6 (E3)
/A0: U1.22 (A15), U3.9 (Q0)
/A1: U1.23 (A14), U3.7 (Q1)
/A2: U1.24 (A13), U3.6 (Q2)
/A3: U1.25 (A12), U3.5 (Q3)
/A4: U1.27 (A10), U3.3 (Q4)
/A5: U1.28 (A9), U3.2 (Q5)
/A6: U1.26 (A11), U3.4 (Q6)
/A7: U1.20 (A17), U3.13 (Q7)
/A8: U1.21 (A16), U3.12 (Q8)
/A9: U1.19 (A18), U3.14 (Q9)
/A10: U1.44 (A5), U4.23 (O0)
/A11: U1.43 (A6), U4.22 (O1)
/A12: U1.42 (A7), U4.21 (O2)
/A13: U1.39 (A8), U4.20 (O3)
/A14: U1.1 (A4), U4.19 (O4)
/A15: U1.2 (A3), U4.18 (O5)
/A16: U1.3 (A2), U4.17 (O6)
/A17: U1.4 (A1), U4.16 (O7)
/A18: U1.5 (A0), U4.15 (O8)
/A19: U1.18 (A19), U4.14 (O9)
/AD0: J1.6, U1.31 (Q4), U4.11 (D9)
/AD1: J1.5, U1.32 (Q5), U4.10 (D8)
/AD2: J1.8, U1.36 (Q7), U4.4 (D2)
/AD3: J1.7, U1.35 (Q6), U4.5 (D3)
/AD4: J1.10, U1.9 (Q0), U4.6 (D4)
/AD5: J1.9, U1.10 (Q1), U4.7 (D5)
/AD6: J1.12, U1.13 (Q2), U4.8 (D6)
/AD7: J1.11, U1.14 (Q3), U4.9 (D7)
/BLOCK: U2.11 (Y4), U3.11 (Reset), U4.13 (LE)
/BUS_A8: J1.14, U2.3 (A2)
/BUS_A9: J1.13, U2.2 (A1)
/BUS_A10: J1.16, U4.3 (D1)
/BUS_A11: J1.15, U4.2 (D0)
/BYTE: U1.40 (CE2), U2.9 (Y6), U3.10 (CLK)
/RAMRST: J1.38, R1.2, U1.6 (~CE1)
/~RD: J1.24, U1.41 (~OE)
/~WR: J1.23, U1.17 (~WE)
/~Y0: J1.29, U2.4 (~E1)
GND: BT1.2 (-), C1.2, C2.2, C3.2, C4.2, C5.2, J1.3, J1.4, J1.21, J1.22, J1.35, J1.36, U1.12 (GND), U1.34 (GND), U2.1 (A0), U2.5 (~E2), U2.8 (GND), U3.8 (VSS), U4.1 (OE), U4.12 (GND)
VBUS: C1.1, C2.1, C3.1, DA1.1 (A), J1.1, J1.2, U2.16 (VCC), U3.16 (VDD), U4.24 (VCC)
VMEM: C4.1, C5.1, DA1.3 (K), R1.1, U1.11 (VCC), U1.33 (VCC)

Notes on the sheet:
TANDY 102/200 SYSTEM BUS
+5VDC
A15
CR2016
INTR
A14
ALE
~{INTA}
CLK
GND
IO/~{M}
VDD
BUS BUS BUS BUS (A) ~{YO} _A8 _A9 _A10 _A11 -> ~{BLOCK} ~{BYTE} L X X X X X X X X H X X X X X X X X L X X X X X H L H L L L -> H L Select BLOCK N, BANK0: OUT129,N H L H L H L -> H L Select BLOCK N, BANK1: OUT133,N H L H L L H -> H L Select BLOCK N, BANK2: OUT137,N H L H L H H -> H L Select BLOCK N,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
RESET
AS6C8008-xxZ CY62158ELL
A13
A12
1M with fewer parts slim version

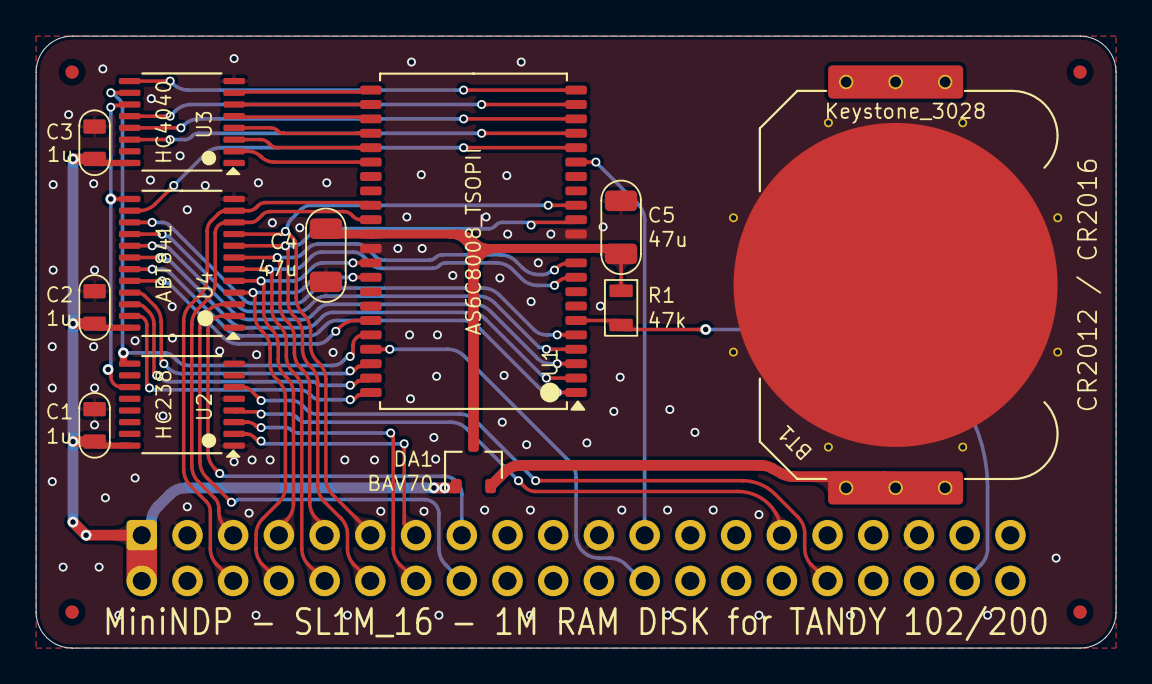
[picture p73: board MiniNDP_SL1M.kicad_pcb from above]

Board: 2 copper layers, 60.0 x 34.0 mm, 18 parts (1 on the bottom side), 43 nets.

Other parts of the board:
F3, F3#2, F3#3, F3#4: Fiducial_0.75_1.5

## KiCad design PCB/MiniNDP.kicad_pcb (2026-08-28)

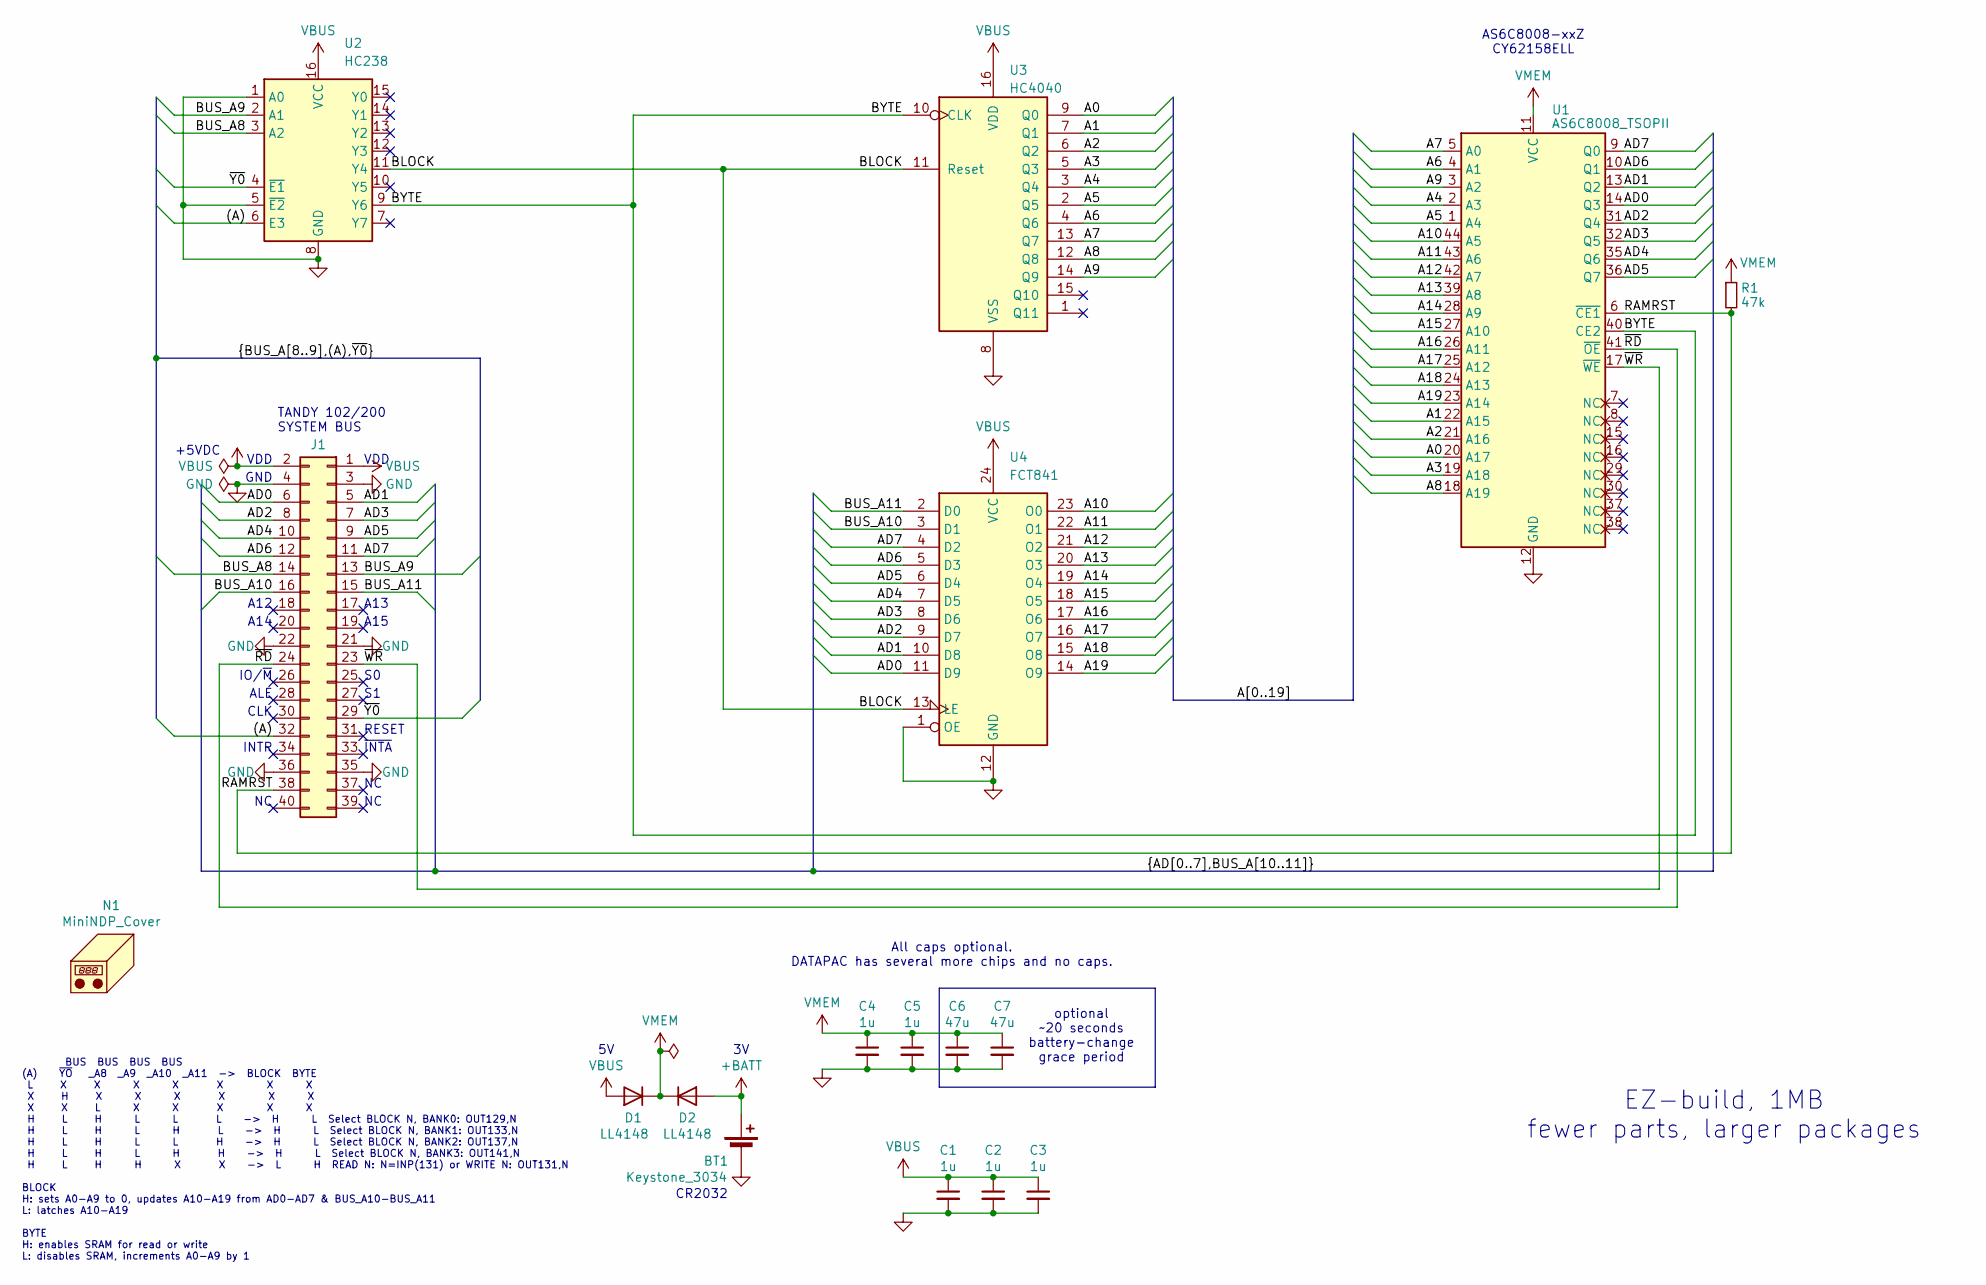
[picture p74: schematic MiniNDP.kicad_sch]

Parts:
BT1: Keystone_3034; Keystone_3028_3034_bkw; MPN Keystone 3034
C1, C2, C3, C4, C5: 1u; C_0805; MPN CL21B105KAFNNNE
C6, C7: 47u; C_1206; MPN C3216X5R1E476M160DC
D1, D2: LL4148; D_MiniMELF; MPN FDLL4148
J1: Conn_02x20_Odd_Even; IDC-Header_2x20_P2.54mm_Vertical; MPN 302-S401
N1: MiniNDP_Cover; MPN MiniNDP_Cover.stl
R1: 47k; R_0805; MPN RMCF0805FT47K0
U1: AS6C8008_TSOPII; TSOP-II-44; MPN AS6C8008-55ZIN
U2: HC238; SOIC-16_3.9x9.9mm_P1.27mm; MPN 74HC238D,653
U3: HC4040; SOIC-16_3.9x9.9mm_P1.27mm; MPN 74HC4040D,653
U4: FCT841; SOIC-24; MPN CY74FCT841CTSOC

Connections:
+BATT: BT1.1 (+), D2.2 (A)
/(A): J1.32, U2.6 (E3)
/A0: U1.20 (A17), U3.9 (Q0)
/A1: U1.22 (A15), U3.7 (Q1)
/A2: U1.21 (A16), U3.6 (Q2)
/A3: U1.19 (A18), U3.5 (Q3)
/A4: U1.2 (A3), U3.3 (Q4)
/A5: U1.1 (A4), U3.2 (Q5)
/A6: U1.4 (A1), U3.4 (Q6)
/A7: U1.5 (A0), U3.13 (Q7)
/A8: U1.18 (A19), U3.12 (Q8)
/A9: U1.3 (A2), U3.14 (Q9)
/A10: U1.44 (A5), U4.23 (O0)
/A11: U1.43 (A6), U4.22 (O1)
/A12: U1.42 (A7), U4.21 (O2)
/A13: U1.39 (A8), U4.20 (O3)
/A14: U1.28 (A9), U4.19 (O4)
/A15: U1.27 (A10), U4.18 (O5)
/A16: U1.26 (A11), U4.17 (O6)
/A17: U1.25 (A12), U4.16 (O7)
/A18: U1.24 (A13), U4.15 (O8)
/A19: U1.23 (A14), U4.14 (O9)
/AD0: J1.6, U1.14 (Q3), U4.11 (D9)
/AD1: J1.5, U1.13 (Q2), U4.10 (D8)
/AD2: J1.8, U1.31 (Q4), U4.9 (D7)
/AD3: J1.7, U1.32 (Q5), U4.8 (D6)
/AD4: J1.10, U1.35 (Q6), U4.7 (D5)
/AD5: J1.9, U1.36 (Q7), U4.6 (D4)
/AD6: J1.12, U1.10 (Q1), U4.5 (D3)
/AD7: J1.11, U1.9 (Q0), U4.4 (D2)
/BLOCK: U2.11 (Y4), U3.11 (Reset), U4.13 (LE)
/BUS_A8: J1.14, U2.3 (A2)
/BUS_A9: J1.13, U2.2 (A1)
/BUS_A10: J1.16, U4.3 (D1)
/BUS_A11: J1.15, U4.2 (D0)
/BYTE: U1.40 (CE2), U2.9 (Y6), U3.10 (CLK)
/RAMRST: J1.38, R1.2, U1.6 (~CE1)
/~RD: J1.24, U1.41 (~OE)
/~WR: J1.23, U1.17 (~WE)
/~Y0: J1.29, U2.4 (~E1)
GND: BT1.2 (-), C1.2, C2.2, C3.2, C4.2, C5.2, C6.2, C7.2, J1.3, J1.4, J1.21, J1.22, J1.35, J1.36, U1.12 (GND), U1.34 (GND), U2.1 (A0), U2.5 (~E2), U2.8 (GND), U3.8 (VSS), U4.1 (OE), U4.12 (GND)
VBUS: C1.1, C2.1, C3.1, D1.2 (A), J1.1, J1.2, U2.16 (VCC), U3.16 (VDD), U4.24 (VCC)
VMEM: C4.1, C5.1, C6.1, C7.1, D1.1 (K), D2.1 (K), R1.1, U1.11 (VCC), U1.33 (VCC)

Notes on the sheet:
TANDY 102/200 SYSTEM BUS
+5VDC
A15
optional ~20 seconds battery-change grace period
CR2032
INTR
A14
ALE
AS6C8008-xxZ CY62158ELL
~{INTA}
CLK
GND
IO/~{M}
VDD
All caps optional. DATAPAC has several more chips and no caps.
BUS BUS BUS BUS (A) ~{YO} _A8 _A9 _A10 _A11 -> BLOCK BYTE L X X X X X X X X H X X X X X X X X L X X X X X H L H L L L -> H L Select BLOCK N, BANK0: OUT129,N H L H L H L -> H L Select BLOCK N, BANK1: OUT133,N H L H L L H -> H L Select BLOCK N, BANK2: OUT137,N H L H L H H -> H L Select BLOCK N, BANK3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
RESET
A13
A12
EZ-build, 1MB fewer parts, larger packages


Board: 2 copper layers, 60.0 x 34.0 mm, 21 parts (1 on the bottom side), 43 nets.

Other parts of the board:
F2, F2#2, F3, F3#2: Fiducial_0.75_1.5

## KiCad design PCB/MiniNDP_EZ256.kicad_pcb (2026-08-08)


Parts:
BT1: Keystone_3034; Keystone_3028_3034; MPN Keystone 3034
C1, C2, C3: 1u; C_1206; MPN CL31B105KAHNNNE
C4, C5: 47u; C_1206; MPN C3216X5R1E476M160DC
D1, D2: LL4148; D_MiniMELF; MPN FDLL4148
J1: Conn_02x20_Odd_Even; IDC-Header_2x20_P2.54mm_Vertical; MPN 302-S401
N1: MiniNDP_Cover; MPN MiniNDP_Cover.stl
R1: 47k; R_1206; MPN CRGCQ1206F47K
U1: HC238; SOIC-16_3.9x9.9mm_P1.27mm; MPN 74HC238D,653
U2: HC4040; SOIC-16_3.9x9.9mm_P1.27mm; MPN 74HC4040D,653
U3: HC573; SOIC-20W_7.5x12.8mm_P1.27mm; MPN 74HC573D,653
U4: AS6C2008A; TSOP-II-SOP-32_dual; MPN AS6C2008A-55SIN

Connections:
+BATT: BT1.1 (+), D2.2 (A)
/(A): J1.32, U1.6 (E3)
/A0: U2.9 (Q0), U4.31 (A15)
/A1: U2.7 (Q1), U4.12 (A0)
/A2: U2.6 (Q2), U4.11 (A1)
/A3: U2.5 (Q3), U4.27 (A8)
/A4: U2.3 (Q4), U4.25 (A11)
/A5: U2.2 (Q5), U4.26 (A9)
/A6: U2.4 (Q6), U4.23 (A10)
/A7: U2.13 (Q7), U4.28 (A13)
/A8: U2.12 (Q8), U4.3 (A14)
/A9: U2.14 (Q9), U4.2 (A16)
/A10: U3.19 (Q0), U4.10 (A2)
/A11: U3.18 (Q1), U4.9 (A3)
/A12: U3.17 (Q2), U4.8 (A4)
/A13: U3.16 (Q3), U4.7 (A5)
/A14: U3.15 (Q4), U4.6 (A6)
/A15: U3.14 (Q5), U4.5 (A7)
/A16: U3.13 (Q6), U4.4 (A12)
/A17: U3.12 (Q7), U4.1 (A17)
/AD0: J1.6, U3.2 (D0), U4.17 (Q3)
/AD1: J1.5, U3.4 (D2), U4.18 (Q4)
/AD2: J1.8, U3.6 (D4), U4.19 (Q5)
/AD3: J1.7, U3.7 (D5), U4.20 (Q6)
/AD4: J1.10, U3.8 (D6), U4.21 (Q7)
/AD5: J1.9, U3.3 (D1), U4.15 (Q2)
/AD6: J1.12, U3.5 (D3), U4.14 (Q1)
/AD7: J1.11, U3.9 (D7), U4.13 (Q0)
/BLOCK: U1.11 (Y4), U2.11 (Reset), U3.11 (LE)
/BUS_A8: J1.14, U1.3 (A2)
/BUS_A9: J1.13, U1.2 (A1)
/BYTE: U1.9 (Y6), U2.10 (CLK), U4.30 (CS2)
/RAMRST: J1.38, R1.2, U4.22 (~CS1)
/~RD: J1.24, U4.24 (~OE)
/~WR: J1.23, U4.29 (~WE)
/~Y0: J1.29, U1.4 (~E1)
GND: BT1.2 (-), C1.2, C2.2, C3.2, C4.2, C5.2, J1.3, J1.4, J1.21, J1.22, J1.35, J1.36, U1.1 (A0), U1.5 (~E2), U1.8 (GND), U2.8 (VSS), U3.1 (~OE), U3.10 (GND), U4.16 (GND)
VBUS: C1.1, C2.1, C3.1, D1.2 (A), J1.1, J1.2, U1.16 (VCC), U2.16 (VDD), U3.20 (VCC)
VMEM: C4.1, C5.1, D1.1 (K), D2.1 (K), R1.1, U4.32 (VCC)

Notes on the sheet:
BUS_A11
TANDY 102/200 SYSTEM BUS
+5VDC
BUS_A15
CY62138FLL-45SXIT
INTR
BUS_A14
ALE
SOP-32 / TSOP-II-32 / SOIC-32
(1)
128k-256k with fewest parts
~{INTA}
CR2032
CLK
IO/~{M}
VDD
RESET
(1) for 128k compatibility A17 must come from AD7 and go to sram pin 1
BUS_A10
BUS_A13
BUS BUS (A) ~{YO} _A8 _A9 -> BLOCK BYTE Function L X X X X X X H X X X X X X L X X X H L H L -> H L Select BLOCK # H L H H -> L H Read or Write BYTE BLOCK H: sets A0-A9 to 0, updates A10-A17 from AD0-AD7 L: latches A10-A17 BYTE H: enables SRAM for read or write L: disables SRAM, increments A0-A9 by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
AS6C1008 128k also compatible
BUS_A12


Board: 2 copper layers, 60.0 x 34.0 mm, 18 parts (1 on the bottom side), 39 nets.

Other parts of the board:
F2, F2#2, F3: Fiducial_0.75_1.5

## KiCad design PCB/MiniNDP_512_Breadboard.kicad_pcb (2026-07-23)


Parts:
J1: Conn_02x20_Odd_Even; IDC-Header_2x20_P2.54mm_Vertical
U1, U2, U3: HC161; DIP-16_W7.62mm
U4: HC138; DIP-16_W7.62mm
U5, U8: HC374; DIP-20_W7.62mm
U6: AS6C4008; DIP-32_W15.24mm
U7: HC32; DIP-14_W7.62mm

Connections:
/(A): J1.32, U4.6 (E3)
/A0: U1.14 (Q0), U6.5 (A7)
/A1: U1.13 (Q1), U6.6 (A6)
/A2: U1.12 (Q2), U6.7 (A5)
/A3: U1.11 (Q3), U6.8 (A4)
/A4: U2.14 (Q0), U6.9 (A3)
/A5: U2.13 (Q1), U6.10 (A2)
/A6: U2.12 (Q2), U6.11 (A1)
/A7: U2.11 (Q3), U6.12 (A0)
/A8: U3.14 (Q0), U6.27 (A8)
/A9: U3.13 (Q1), U6.26 (A9)
/A10: U5.2 (O0), U6.23 (A10)
/A11: U5.5 (O1), U6.25 (A11)
/A12: U5.6 (O2), U6.4 (A12)
/A13: U5.9 (O3), U6.28 (A13)
/A14: U5.12 (O4), U6.3 (A14)
/A15: U5.15 (O5), U6.31 (A15)
/A16: U5.16 (O6), U6.2 (A16)
/A17: U5.19 (O7), U6.30 (A17)
/A18: U6.1 (A18), U8.9 (O3)
/AD0: J1.6, U5.3 (D0), U6.13 (Q0)
/AD1: J1.5, U5.4 (D1), U6.14 (Q1)
/AD2: J1.8, U5.7 (D2), U6.15 (Q2)
/AD3: J1.7, U5.8 (D3), U6.17 (Q3)
/AD4: J1.10, U5.13 (D4), U6.18 (Q4)
/AD5: J1.9, U5.14 (D5), U6.19 (Q5)
/AD6: J1.12, U5.17 (D6), U6.20 (Q6)
/AD7: J1.11, U5.18 (D7), U6.21 (Q7)
/BUS_A8: J1.14, U4.1 (A0)
/BUS_A9: J1.13, U4.2 (A1)
/BUS_A10: J1.16, U8.8 (D3)
/RAMRST: J1.38, U7.2
/TC0: U1.15 (TC), U2.7 (CEP), U2.10 (CET)
/TC1: U2.15 (TC), U3.7 (CEP), U3.10 (CET)
/~BLOCK: U1.1 (~MR), U2.1 (~MR), U3.1 (~MR), U4.14 (O1), U5.11 (Cp), U8.11 (Cp)
/~BYTE: U1.2 (CP), U2.2 (CP), U3.2 (CP), U4.12 (O3), U7.1
/~CE: U6.22 (~CE), U7.3
/~RD: J1.24, U6.24 (~OE)
/~WR: J1.23, U6.29 (~WE)
/~Y0: J1.29, U4.5 (E2)
GND: J1.3, J1.4, J1.21, J1.22, J1.35, J1.36, U1.3 (D0), U1.4 (D1), U1.5 (D2), U1.6 (D3), U1.8 (GND), U2.3 (D0), U2.4 (D1), U2.5 (D2), U2.6 (D3), U2.8 (GND), U3.3 (D0), U3.4 (D1), U3.5 (D2), U3.6 (D3), U3.8 (GND), U4.3 (A2), U4.4 (E1), U4.8 (GND), U5.1 (OE), U5.10 (GND), U6.16 (GND), U7.4, U7.5, U7.7 (GND), U7.9, U7.10, U7.12, U7.13, U8.1 (OE), U8.3 (D0), U8.4 (D1), U8.7 (D2), U8.10 (GND), U8.13 (D4), U8.14 (D5), U8.17 (D6), U8.18 (D7)
VBUS: J1.1, J1.2, U1.7 (CEP), U1.9 (~PE), U1.10 (CET), U1.16 (VCC), U2.9 (~PE), U2.16 (VCC), U3.9 (~PE), U3.16 (VCC), U4.16 (VCC), U5.20 (VCC), U6.32 (VCC), U7.14 (VCC), U8.20 (VCC)

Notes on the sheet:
TANDY 102/200 SYSTEM BUS
+5VDC
A15
INTR
A14
ALE
~{INTA}
CLK
GND
/----- BUS -----\ (A) ~{YO} A8 A9 A10 -> ~{BLOCK} ~{BYTE} L X X X X X X X H X X X X X X X L X X X X H L H L L -> L H Select BLOCK # from BANK0 H L H L H -> L H Select BLOCK # from BANK1 H L H H L -> H L READ/WRITE BYTE H L H H H X X Each ~{BLOCK} pulse low: sets A0-A9 to 0, sets A10-A17 from AD0-AD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
IO/~{M}
VDD
RESET
A11
A13
A12


Board: 2 copper layers, 9 parts (0 on the bottom side), 42 nets.

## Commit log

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2023-08-19 VBUS to U5 /E3, notes, pcb layout no traces
    [NODE_DATAPAC_128K_256K.kicad_pcb, NODE_DATAPAC_128K_256K.kicad_sch]
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2023-08-24 historical & new versions
    [NODE_DATAPAC_128K_256K.kicad_pcb, NODE_DATAPAC_128K_256K.kicad_sch, NODE_DATAPAC_256K_bkw0.kicad_pcb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]
2023-08-25 remove unused 3d models
    [NODE_DATAPAC_256K_bkw0.kicad_pcb, NODE_DATAPAC_256K_bkw0.kicad_sch]
2023-08-26 readme, software, remove nimh from new board
    [NODE_DATAPAC_256K_bkw0.kicad_pcb, NODE_DATAPAC_256K_bkw0.kicad_sch, NODE_DATAPAC_256K_historical.kicad_sch]
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2023-08-27 start decoding circuit theory of operation, organize files
    [NODE_DATAPAC_256K_bkw0.kicad_sch, NODE_DATAPAC_256K_historical.kicad_sch]
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2023-08-30 minindp fix swapped AD0 vs A10 on U5, improve routing
    [MiniNDP_256.kicad_pcb, MiniNDP_256.kicad_sch]
2023-08-30 minindp battery holder part number
    [MiniNDP_256.kicad_pcb, MiniNDP_256.kicad_sch]
2023-08-30 fix missing teardrops
    [MiniNDP_256.kicad_pcb]
2023-08-30 increase clearance around battery+
    [MiniNDP_256.kicad_pcb]
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2023-08-31 readme and tiny pcb trace position adjustments
    [MiniNDP_256.kicad_pcb]
2023-08-31 readme, CR2016 and CR2012 battery holders
    [MiniNDP_256.kicad_pcb, MiniNDP_256.kicad_sch]
2023-09-08 convert wires to busses in bkw sch
    [MiniNDP_256.kicad_pcb, MiniNDP_256.kicad_sch, NODE_DATAPAC_256K_bkw.kicad_pcb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]
2023-09-10 minindp u7 footprint, 2 BAV70 -> 1 BAV70S
    [MiniNDP_256.kicad_pcb, MiniNDP_256.kicad_sch]
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2023-09-22 minindp low reverse leakage diode to protect batt
    [MiniNDP_256.BOM.csv, MiniNDP_256.kicad_pcb, MiniNDP_256.kicad_sch]
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2023-11-08 add slip cover STL from FD Sigleton
    [MiniNDP_256_FD_Sigleton.stl]
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2023-11-13 fix wrong polarity on net names (A), /Y0, /INTA, INTR, RESET
    [MiniNDP_256.kicad_pcb, MiniNDP_256.kicad_sch, NODE_DATAPAC_256K_bkw.kicad_pcb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]
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2023-11-14 text notes in sch, make big cap C1
    [MiniNDP_256.kicad_pcb, MiniNDP_256.kicad_sch]
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2023-11-14 fix active-high notation of ALE & INTR in sch comments
    [MiniNDP_256.kicad_sch, NODE_DATAPAC_256K_bkw.kicad_sch, NODE_DATAPAC_256K_historical.kicad_sch]
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2024-05-17 Redraw 1M for SOIC-24 FCT821, 2mm corners, remove corner holes, update cover
    [MiniNDP_1M.PCB.stl, MiniNDP_1M.kicad_pcb, MiniNDP_1M.kicad_sch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]
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2024-05-20 new 512K_B version using SOP/TSOP-II sram and FCT821 latch
    [MiniNDP_1M.PCB.stl, MiniNDP_1M_enclosure.stl, MiniNDP_512K_B.PCB.stl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]
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2024-05-28 fix 128k compatibility, AD7->A17->pin9
    [MiniNDP_512.kicad_pcb, MiniNDP_512.kicad_sch, MiniNDP_Cover.CR2016.stl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]
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2024-06-13 Add pullup on /WR. Tighter cover fit.
    [MiniNDP_1M.kicad_pcb, MiniNDP_1M.kicad_sch, MiniNDP_512.kicad_pcb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]
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2024-11-15 512_E & 1M silkscreen, MPNs in sch, pos & bom
    [MiniNDP_1M.fab_bom.csv, MiniNDP_1M.kicad_pcb, MiniNDP_1M.kicad_sch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]
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2024-11-20 larger parts on D version and proper bom
    [MiniNDP_512_D.bom.csv, MiniNDP_512_D.kicad_pcb, MiniNDP_512_D.kicad_sch]
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2024-11-26 512k G board - all large 1206 & soic
    [Control_Logic_Reference.kicad_sch, MiniNDP_512_G.bom.csv, MiniNDP_512_G.kicad_pcb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]
2024-11-26 512_G missing trace ramrst to nand
    [MiniNDP_256_F.kicad_pcb, MiniNDP_512_G.kicad_pcb, MiniNDP_512_G.kicad_sch]
2024-11-26 replace 512_F with 512_G
    [MiniNDP_512_F.bom.csv, MiniNDP_512_F.kicad_pcb, MiniNDP_512_F.kicad_sch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]
2024-11-26 512-F re-add ramrst diode, both-F remove /WR pullup
    [MiniNDP_256_F.bom.csv, MiniNDP_256_F.kicad_pcb, MiniNDP_256_F.kicad_sch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]
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2024-11-29 easy boards add 47u cap, remove ramrst diode
    [MiniNDP.bom.csv, MiniNDP.kicad_pcb, MiniNDP.kicad_sch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]
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2024-12-12 256_F wrong sram part# on silkscreen
    [MiniNDP_256_F.kicad_pcb]
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2024-12-13 add SL1M, rename 1M_C to EZ1M, remove 256_F & 512_F from readme
    [MiniNDP.kicad_pcb, MiniNDP.kicad_sch, MiniNDP_EZ1M.bom.csv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]
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2025-10-02 add historical part numbers found on a 1987 unit
    [NODE_DATAPAC_256K_historical_reproduction.kicad_sch]
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2025-11-21 embed code font in pcb, bom export filename variables, delete extra battery trace
    [MiniNDP.kicad_pcb, MiniNDP.kicad_sch, MiniNDP_E.kicad_pcb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]
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2026-05-04 ChipNDP 009 rotate ram chip for /WR /RD
    [ChipNDP.kicad_pcb, ChipNDP.kicad_sch]
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2026-07-23 minindp ez1m sl1m ez512 u1m pcbs trace spacing & gnd paths
    [MiniNDP.kicad_pcb, MiniNDP_EZ512.kicad_pcb, MiniNDP_SL1M.kicad_pcb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]
2026-07-23 minindp og orient bav70 for easier hand solder
    [MiniNDP_OG.kicad_pcb]
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2026-07-27 ez1m, m10, fine tune pcb trace gaps and & fillets
    [MiniNDP.kicad_pcb, MiniNDP_M10.kicad_pcb]
2026-07-28 sl1m fine tune pcb trace gaps and & fillets
    [MiniNDP_SL1M.kicad_pcb]
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2026-08-05 add MiniNDP T512, configurable 128k-512k, 238 4040 573 all tsop/tssop
    [MiniNDP_T512.kicad_pcb, MiniNDP_T512.kicad_sch]
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2026-08-08 M10 & EZ256 trace & via clearances, silkscreen
    [MiniNDP_EZ256.kicad_pcb, MiniNDP_EZ256.kicad_sch, MiniNDP_M10.kicad_pcb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]
2026-08-08 M10_alt common pcb outline & cover, better plug
    [MiniNDP_M10_alt.kicad_pcb, MiniNDP_M10_alt.kicad_sch]
2026-08-09 M10x M-10 w/std pcb outline & std thin cover
    [MiniNDP_M10_alt.kicad_pcb, MiniNDP_M10x.kicad_pcb, MiniNDP_M10x.kicad_sch]
2026-08-10 Make M10x the default M10 version, other version M10c for compact)
    [MiniNDP_M10.bom.csv, MiniNDP_M10.kicad_pcb, MiniNDP_M10.kicad_sch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]
2026-08-10 fix tssop-24 model, update cover models
    [MiniNDP_Cover.scad, MiniNDP_Cover.stl, MiniNDP_Cover_M10compact.stl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]
2026-08-12 M10c compact pcb & cover a little smaller & symmetrical
    [MiniNDP_Cover.scad, MiniNDP_Cover.stl, MiniNDP_Cover_M10compact.stl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]
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2026-08-14 M10 better layout, put old M10 versions in attic
    [MiniNDP_Cover.scad, MiniNDP_Cover_M10.stl, MiniNDP_M10.kicad_pcb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]
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2026-08-14 M10 via too close to u4p13
    [MiniNDP_M10.kicad_pcb]
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2026-08-19 u1M vias near C1 pad, silkscreen, smooth traces
    [MiniNDP.kicad_pcb, MiniNDP_u1M.kicad_pcb]
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2026-08-23 add sram part numbers to 1M versions sch
    [MiniNDP.kicad_sch, MiniNDP_M10.kicad_sch, MiniNDP_SL1M.kicad_sch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]
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2026-08-25 simplify covers, strengthen battery holders, silkscreen, readme
    [MiniNDP.kicad_pcb, MiniNDP.kicad_sch, MiniNDP_Cover.scad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]
2026-08-25 readme links to pcbs & covers, sl1m remove via from batt terminal
    [MiniNDP_SL1M.kicad_pcb]
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2026-09-02 T512 re-layout, shorter simpler traces with no via hops on most signals
    [MiniNDP_T512.bom.csv, MiniNDP_T512.kicad_pcb, MiniNDP_T512_old.kicad_pcb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]
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2026-09-03 remove dead end M10 variants, put OG in attic, clean up cover scad, models, & readmes
    [MiniNDP_Cover.scad, MiniNDP_M10v1.kicad_pcb, MiniNDP_M10v1.kicad_sch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]
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2026-09-05 M10 bus connector closer to end for more clearance to bus compartment door
    [MiniNDP_M10.kicad_pcb]
2026-09-10 M10 move bus connector all the way to the corner, T512 bulk caps on vmem
    [MiniNDP_M10.kicad_pcb, MiniNDP_M10.kicad_sch, MiniNDP_T512.kicad_pcb]
2026-09-11 add filler plate and connector guide for M10 bus compartment
    [M10_BUS_Filler_Plate.scad, M10_BUS_Filler_Plate.stl, MiniNDP_Cover.scad]
2026-09-11 M10 filler plate add chamfer & position tunnel
    [M10_BUS_Filler_Plate.scad, M10_BUS_Filler_Plate.stl]
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
